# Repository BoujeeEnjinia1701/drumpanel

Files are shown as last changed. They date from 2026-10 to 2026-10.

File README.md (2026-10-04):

# DrumPanel

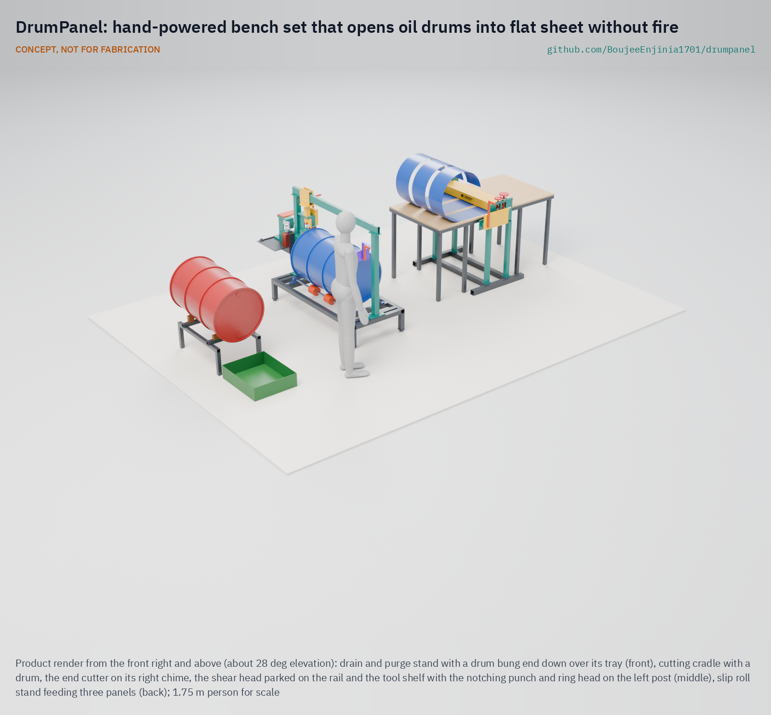
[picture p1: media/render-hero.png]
DrumPanel: hand-powered bench set that opens oil drums into flat sheet without fire


     

**Area:** Circular materials · **TRL:** 3 of 9 (proof of concept on paper) · **Value-engineering target:** USD 3,000 (estimated cost USD 3,489) · **Difficulty:** 3 of 5

Turns empty oil drums into flat sheet by purging and cold-opening them instead of burning them.

## Concept rationale

Used 55 gallon (about 208 L) steel drums are a cheap source of sheet metal for artisans; accounts from Haiti speak of three sheets of about 18 by 72 in (460 by 1,830 mm) per drum. DrumPanel gets three flat panels about 233 x 1,800 mm and two head discs about 552 mm across from each drum. Today the common method is to fill the drum with dried leaves and set it on fire to clear paint and residue, then chisel off the ends, split the side and flatten it. DrumPanel keeps the craft and changes the first steps: purge the drum, check it for vapour, cut it cold and roll it flat with hand-cranked tools on a bench.

The design is manual on purpose. The preliminary IP screen found powered drum cutter-flatteners on the market; DrumPanel assumes workshops with little money and no dependable power. A bench set built from commodity steel and bearings, published openly with a written purge and vapour check, can be made by a local fabricator for an estimated USD 3,489 (value-engineering target USD 3,000, so USD 489 over it) and shared across a workshop cluster.

## Burning platform

In Croix-des-Bouquets, Haiti, the centre of Haitian metal sculpture since Georges Liautaud began the form in the 1950s, drum lids are cut open with a chisel and hammer, the side is split, and the interior is filled with dried sugarcane or grass and set on fire to remove grime before the drum is flattened ([SFO Museum](https://www.sfomuseum.org/exhibitions/haitian-metal-sculpture)). Other accounts describe stuffing drums with banana leaves to burn off paint and residue, and cutting with only hammers and chisels ([Singing Rooster](https://singingrooster.org/about-haitian-art/)). Artists then flatten the body by climbing inside and using their weight to open it up ([Roots of Development](https://store.rootsofdevelopment.org/wp-content/uploads/2023/12/About-Haitian-Metal-Art.pdf)).

This first stage is where newcomers begin: new artists usually start by burning out whole 55 gallon drums, cutting them down and pounding the surfaces flat ([Global Exchange](https://globalexchange.org/tag/haiti-oil-drum-art/)). The work is loud enough that a support group tried supplying ear plugs ([Singing Rooster](https://singingrooster.org/about-haitian-art/)). The raw material is plentiful, a byproduct of shipping through the harbour in Port-au-Prince ([Haiti Hub](https://haitihub.com/the-story-of-haitian-metal-art/)), so better tools for this stage would reach many workshops.

## Where it could be used

### By industry

| Industry | Use |
| --- | --- |
| Artisan metalwork and crafts | Opening and flattening drums into sheet for sculpture, wall art and homewares |
| Informal fabrication | Sheet for stoves, boxes, roofing patches and small tanks in workshops without sheet stock |
| Drum reconditioning and recycling | Cold, manual opening of drums that cannot be reused whole |
| Vocational training | A documented, safer drum preparation method for apprentices |
| Fair trade and export buyers | A cleaner, repeatable supply chain for drum-based products |

### By country or region

| Country or region | Why it matters there |
| --- | --- |
| Haiti, Croix-des-Bouquets | Noailles in Croix-des-Bouquets has long been the centre of Haitian metal art, though gang violence has recently forced artists to relocate ([SFO Museum](https://www.sfomuseum.org/exhibitions/haitian-metal-sculpture)). |
| Haiti, Port-au-Prince | Drums come to artisans as a byproduct of shipping through the harbour, and each 55 gallon drum yields three sheets of about 18 by 72 in ([Haiti Hub](https://haitihub.com/the-story-of-haitian-metal-art/)). |
| United States | Fair trade stores sell Haitian oil drum art, giving artisans who export under fair labour conditions a route out of poverty ([Global Exchange](https://globalexchange.org/tag/haiti-oil-drum-art/)). |
| Europe and North America | Croix-des-Bouquets sculpture made with hacksaws, hammers and chisels is shown in galleries, museums and private collections ([Nader Haitian Art](https://www.naderhaitianart.com/blogs/news/a-deep-dive-into-metal-sculptures-from-croix-des-bouquets)). |

## What sparked the idea

Haiti Hub's account of Haitian metal art says it plainly: each drum is first burned to remove all paint and residue, then cut vertically down both sides and flattened into panels ([Haiti Hub](https://haitihub.com/the-story-of-haitian-metal-art/)). Every sheet in the craft starts with a fire and a chisel. DrumPanel asks whether that first step can be done cold, on a bench, with hand tools a local fabricator can make.

## Problem

Metal artisans who turn used oil drums into sheet usually burn each drum out first and then cut and flatten it by hand with chisels and body weight. The work is loud and relies on open fire, and there is no simple, documented bench method to open drums cold.

Full problem statement: [docs/01-problem.md](docs/01-problem.md)

## Concept

A bench set of manual tools that purges an empty oil drum, checks it for vapour, cold-cuts the ends and seam, and rolls the body flat; metal artisans clamp and crank to turn drums into flat sheet instead of burning them open.

Full design precis: [docs/02-concept.md](docs/02-concept.md) · Requirements: [docs/03-requirements.md](docs/03-requirements.md)

## Key components

- Drain and purge stand, drain tray and purge kit
- Vapour check kit (pumped gas detector)
- Cutting cradle: frame, rollers under the hoops, drum brake
- Rail posts, rail beam, trolley and a swivelling rotary shear head
- End cutter for the heads
- Slip roll: geared pinch rolls, bending roll, 3:1 chain crank, guards and tables
- Bench plate, deburring tools and pictogram procedure sheets

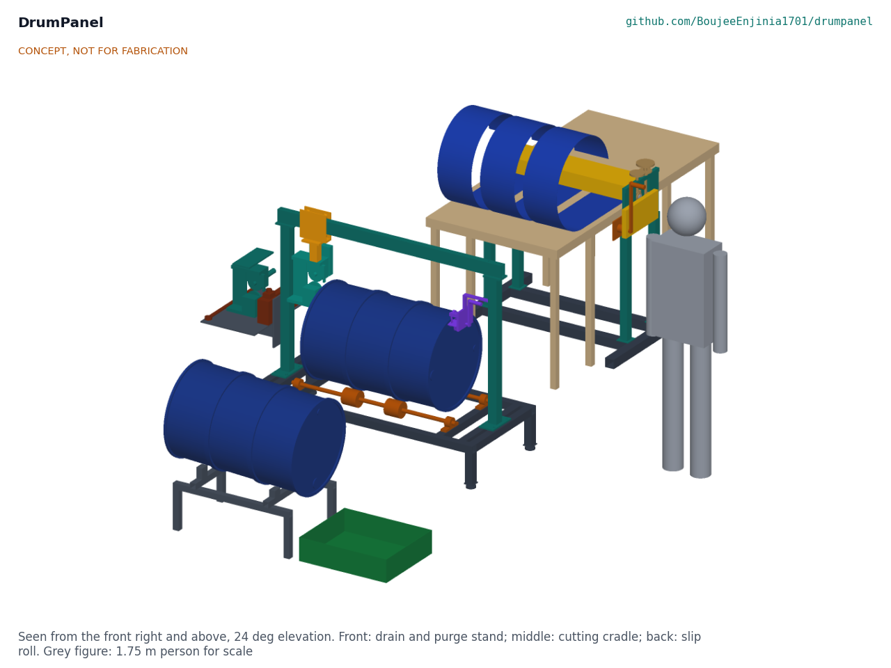
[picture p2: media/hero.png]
Concept overview: drain stand, cutting cradle and slip roll


## Building the prototype

The prototype build plan ([docs/05-build-plan.md](docs/05-build-plan.md)) shows how to make each of the 24 groups of parts and put them together, with a making sketch for every made part, close-ups of the joints and a picture for every assembly step. Almost everything is sawn, drilled and stick-welded from square tube and plate; the rolls are turned on a lathe; the slitting discs, cutter wheel, notching punches and dies, bearings, gears and gas detector are bought or made by a tool shop. It is a plan, not yet built: building and testing it is TRL 4 work.

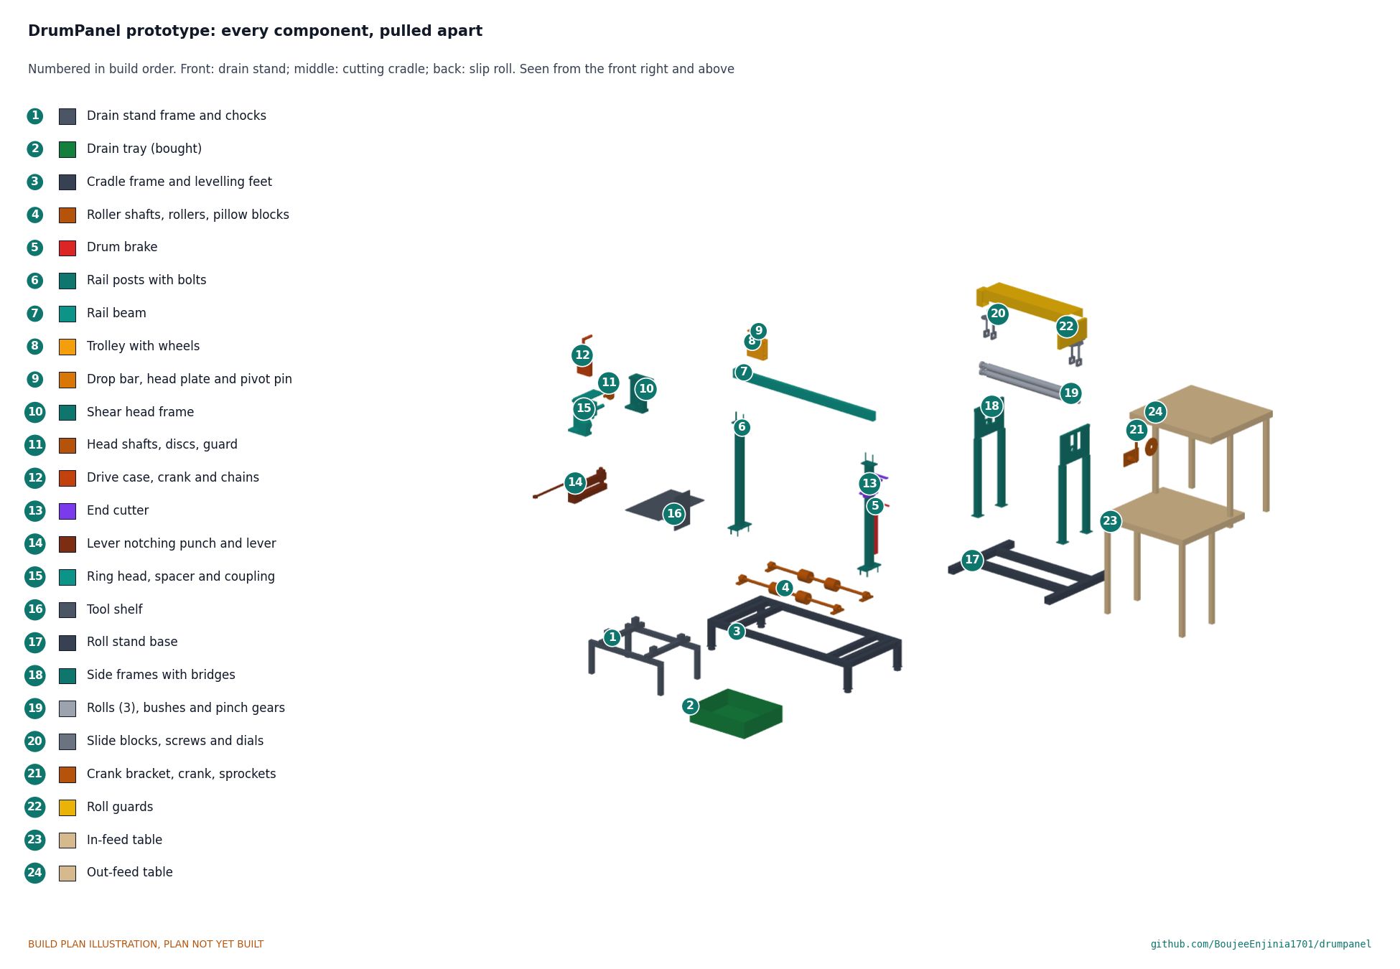
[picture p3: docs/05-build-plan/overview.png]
Every component, pulled apart and numbered in build order


## Safety

> Empty drums can still hold flammable vapour. Never cut, grind, weld or heat a drum until the purge is done and the vapour check passes below 5 % LEL.
>
> Do not process drums that held fuel, solvent, chemicals or unknown contents, or that have no readable label.
>
> A drum full of water weighs about 240 kg: fill and drain it on the stand, never lift it.
>
> Cut steel edges are sharp; wear cut-resistant gloves and eye protection, and deburr sheets before handling.
>
> Crank-driven rolls and cutters have pinch points; keep guards fitted and one person on the crank.
>
> This design is published as an open engineering reference. It is not certified equipment. It is a TRL 3 concept, not for fabrication until built and tested at TRL 4.

## Repository layout

| Folder | Contents |
| --- | --- |
| `docs/` | Problem, concept, requirements, calculations and design decisions |
| `cad/src/` | build123d Python source, the source of truth for all geometry |
| `cad/step/`, `cad/stl/` | Exported models for FreeCAD, other CAD tools and printing |
| `cad/drawings/` | 2D sketches and dimensioned drawings |
| `bom/` | Bill of materials |
| `electronics/` | KiCad schematics and PCB layouts |
| `firmware/` | Microcontroller code |
| `media/` | Renders, perspectives and photos |
| `build-log/` | Dated prototyping notes |

## Documentation

Controlled documents follow the portfolio [documentation standard](.kit/STANDARDS.md). Each carries a document ID (DMP-PRC-001 for the precis), a version and a revision history. Branded PDFs are built with `python .kit/render.py` and attached to GitHub Releases when a document is tagged, for example `DMP-PRC-001/v1.0`.

## Credits

Designed by Amish Chadha at Design Molecule Labs. See [CONTRIBUTORS.md](CONTRIBUTORS.md) for roles. To cite this design, use [CITATION.cff](CITATION.cff) (GitHub shows it as "Cite this repository").

AI assistance (Claude) was used to accelerate prototype documentation and first-pass research. Design direction and all decisions are Amish Chadha's, recorded in this repository's decision records (`docs/decisions/`).

## Licenses

- **Hardware** (CAD, drawings, BOM, electronics): [CERN-OHL-S v2](LICENSE)
- **Software** (firmware, scripts, notebooks): [MIT](LICENSE-SOFTWARE)

A project of the [Design Molecule](https://designmolecule.com) lab.

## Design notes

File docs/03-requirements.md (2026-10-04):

---
doc_id: DMP-REQ-001
title: DrumPanel requirements
project: DrumPanel
doc_type: Requirements
version: "0.5"
status: Draft
date: '2026-10-03'
author: Amish Chadha
license: CERN-OHL-S-2.0
revisions:
- version: "0.1"
  date: '2026-09-30'
  author: Amish Chadha
  change: Initial scaffold
- version: "0.2"
  date: '2026-10-03'
  author: Amish Chadha
  change: TRL 2; targets firmed up; R10 guarding, R11 handling and R12 yield added; concept status for each requirement
- version: "0.3"
  date: '2026-10-03'
  author: Amish Chadha
  change: TRL 3; status of every requirement from DMP-CAL-001 on the constructable design (DMP-DDR-002); R9 worded against the value-engineering target; R12 changed to three panels per drum
- version: "0.4"
  date: '2026-10-03'
  author: Amish Chadha
  change: 'R7 restated to 2.5 drums an hour by Amish on 2026-10-03 (decision 5A, DMP-DDR-003); status of R5, R6, R7, R9 and R11 from DMP-CAL-001 v0.2 after the notching punch, ring head and dial adjuster'
- version: "0.5"
  date: '2026-10-03'
  author: Amish Chadha
  change: "Round-2 decision 5A (DMP-DDR-004): R7 kept at 2.5 drums an hour; the TRL 4 timed trial decides; no design change"
---

# DrumPanel requirements

On paper, the constructable design meets ten of the twelve requirements, misses one, and is over the value-engineering target of R9. On 2026-10-03 Amish chose option A on every requirement decision put to him ("1A 2A 3A 4A 5A 6A 7A 8A 9A 10A 11A"); for DrumPanel that added a lever notching punch and a ring head and restated R7 from 4 to 2.5 drums an hour (5A), and added a fine-pitch dial adjuster to the bending roll (8A) (DMP-DDR-003). R7 is still not met: the estimate is about 2.26 drums an hour, up from 2.0. R5 is now met on paper with a trial pass for each batch of drum steel: the dial sets the bending roll to 0.025 mm against a 0.29 mm allowance. Every figure is from DMP-CAL-001 v0.2 (`docs/04-calcs/sizing.py`); the tag in brackets is the line of its output.

*Table 1. Requirements and their status at TRL 3.*

| ID | Requirement | Target | Verification (TRL 4) | Status at TRL 3 |
| --- | --- | --- | --- | --- |
| R1 | No open flame in the process | Zero heat or flame steps from drum to flat sheet | Procedure review and observed trial | Met by design: purge, check, cut and roll are all cold; no grinder or torch touches a drum |
| R2 | Vapour check before cutting | Check reliably flags a drum with flammable vapour at or above 10 % of the lower explosive limit (LEL) | Bump test of the bought detector with 50 % LEL gas; bench test with a calibrated gas | Met by design: a bought pumped LEL detector with its alarm set at 5 % LEL, half the target (DMP-DDR-001, D2) |
| R3 | Remove ends cold | Both heads off a 208 L drum in under 10 minutes by one person | Timed trials on a batch of drums | Met on paper: about 3.9 min [H7]; crank force 12 to 27 N [C10 to C15] |
| R4 | Open the side | Straight slit along the full body length, edge deviation at or below 5 mm | Measure the cut line on trial drums | Met by design: the shear head runs on a rail straight within 1 mm |
| R5 | Flat sheet | Panels flat within 10 mm over 1 m after rolling | Straightedge and feeler check | Met on paper, with a trial pass for each batch: needs the bending roll within 0.29 mm of the right height [E13], which is 11.8 divisions of the new 0.025 mm dial [E14d], held by a lock nut; a fixed setting can leave 188 mm of sag on other steel [E12], so the reading is found by a trial pass on the first drum of each batch; the last 90 mm of each panel end is set by hand [E15, E16] |
| R6 | Manageable effort | Crank force at or below 150 N at the handle | Spring scale on the handle during trials | Met on paper: end cutter 27 N, shear head 68 N for the slit and 136 N for two ring cuts at 1.5 mm wall, notching punch lever 131 N, slip roll 20 N [C15, D15, D15r, K3, E23] |
| R7 | Throughput | At least 2.5 drums to flat sheet per hour for a two-person team (restated 2026-10-03, was 4) | Timed half-day workshop trial | Not met on paper: about 2.26 drums an hour [H5], 53.1 hands-on minutes a drum against 48.0 [H4, H9]. Kept at 2.5 by Amish (round 2); the TRL 4 timed trial decides |
| R8 | Local build | All parts made or bought in a town with a welder and a lathe | Build by a partner fabricator from the drawings | Met by design: welding, drilling and turning only; the rolls need a lathe with 1.1 m between centres; discs, cutter wheel, bearings, gears and chain are bought |
| R9 | Value engineering | Bench set parts cost at or below the USD 3,000 value-engineering target | Costed bill of materials | Over the target: estimated USD 3,489, USD 489 over the value-engineering target [J1 to J3] |
| R10 | Guarding | No finger reaches a roll nip, disc nip, gear or chain in normal use; guards need a tool to remove | ISO 13857 check of the guards as built | Met on paper: every slot 8 mm or less and 45 mm or more from its nip [G1 to G3]; the shear head's chains run inside its closed drive case and the ring head coupling turns inside a guard sleeve |
| R11 | Handling | No lift over 25 kg by one person; a drum full of water is never lifted | Weigh parts; procedure review | Met with a two-person rule: heaviest piece the 34 kg cradle frame [I4]; shear head 23.7 kg, ring head 20.4 kg, notching punch 18.7 kg [I5, I7, I9]; a full drum (about 240 kg) is filled and drained in place [B2] |
| R12 | Yield | Per drum: three flat panels about 233 x 1,800 mm and two head discs about 550 mm across | Measure the output of trial drums | Met by design: panels 233, 234 and 233 x 1,800 mm; heads 552 mm [A1 to A3] |

## Requirement restated on 2026-10-03

R7 was "at least 4 drums to flat sheet per hour for a two-person team". Amish restated it to 2.5 drums an hour when he chose option 5A on 2026-10-03 ("1A 2A 3A 4A 5A 6A 7A 8A 9A 10A 11A"): add a lever notching punch and a second shear head so two ring cuts are made per pass, and restate R7 to 2.5 drums an hour. The record is DMP-DDR-003.

In round 2 Amish kept R7 at 2.5 drums an hour (5A of DMP-DDR-004): "i agree with all the 46 recommendations you provided. please proceed." The paper estimate of 2.26 drums an hour is not changed, and R7 is not claimed as met. The gap is about 10 % of the hands-on time, inside the uncertainty of the task-time estimates, so the TRL 4 timed half-day trial decides, and no design change is made at TRL 3.

## Assumptions

- Most drums reaching artisans held oils or similar contents that a water purge can clear enough to cut cold. Drums that did not are rejected at the door (DMP-PRB-001, Constraints).
- Artists accept painted panels, with paint removal as a separate cold step (DMP-DDR-001, D4).
- Drum body steel has a yield strength of 200 to 300 MPa and a wall of 0.8 to 1.2 mm; heads are 1.0 to 1.5 mm.
- The rolling hoops are cut out as two strips, so the slip roll never has to straighten them (DMP-DDR-002, P7).
- A pumped LEL detector, bump-tested each day, is good enough for a pass or fail check before cold cutting.

## Safety

> **Safety:** R1, R2, R10 and R11 are safety requirements. They are not traded against cost or throughput: where a cheaper or faster option would weaken them, the conservative option was taken (DMP-DEC-001). The bench set is an open engineering reference, never certified equipment.

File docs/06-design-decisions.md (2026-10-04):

---
doc_id: DMP-DEC-001
title: DrumPanel design decisions register
project: DrumPanel
doc_type: Design decisions register
version: "0.3"
status: Draft
date: '2026-10-03'
author: Amish Chadha
license: CERN-OHL-S-2.0
revisions:
- version: "0.1"
  date: '2026-10-03'
  author: Amish Chadha
  change: Register opened at TRL 3; every decision made under Amish's pre-approval of 2026-10-03
- version: "0.2"
  date: '2026-10-03'
  author: Amish Chadha
  change: Amish's requirement decisions 5A (R7) and 8A (R5) of 2026-10-03 moved to Decisions made (DMP-DDR-003); new open decision on the remaining R7 gap; value engineering updated
- version: "0.3"
  date: '2026-10-03'
  author: Amish Chadha
  change: "Open decision 1 (R7 gap) decided, round 2, 5A (DMP-DDR-004); no open decisions"
---

# DrumPanel design decisions register

Every design decision still to be made, and every decision made, in one place. Each decision is argued in full in its decision record under `docs/decisions/`; this register is the index Amish works from. The build plan (`docs/05-build-plan.md`) describes the design as it stands and does not list open decisions.

## Open decisions

None. Open decision 1 (the remaining R7 gap) was decided by Amish on 2026-10-03: R7 stays at 2.5 drums an hour and the TRL 4 timed trial decides; see Decisions made and DMP-DDR-004.

## To confirm when parts are bought

*Table 2. Items to confirm when parts are bought.*

| # | What to confirm | Why it matters | Source |
| --- | --- | --- | --- |
| 1 | The slitting discs bought: 101 mm outside, 10 mm thick, 25 mm bore, hardness 58 to 60 HRC | The 1.0 mm overlap, the shaft shoulders and the guard clearance are drawn to these sizes | DMP-DDR-002, P4 |
| 2 | The end cutter wheel bought: 50 mm across, 6 mm thick, and its bore | Sets the cutter arm and the cut line 4 mm inside the chime wall | DMP-DDR-002, P3 |
| 3 | Real drums from the first supplier: chime inside radius, hoop positions and height, wall and head thickness | Hoop cut lines (30 mm each side of each hoop), roller positions and the steel range of the calculations | DMP-CAL-001, Table 1 |
| 4 | The gas detector bought: pumped sampling, a 1 m probe that fits a 20 mm bung, an alarm that can be set at 5 % LEL, and its calibration gas | The vapour check procedure depends on it | DMP-DDR-001, D2 |
| 5 | Pinch gear mesh at 61 to 61.5 mm centres with the module 3 gears bought | The pinch opens as the sheet thickens | DMP-CAL-001, section 5.5 |
| 6 | The bending roll setting for the first batch of drums, found by a trial pass | R5 depends on it; the calculation gives only a range (9.3 to 19.3 mm) | DMP-CAL-001, section 5.3 |
| 7 | The driven disc's grip on a 1.5 mm wall | Traction margin is only 1.17 at 1.5 mm | DMP-CAL-001, section 4 |
| 8 | The notching punch on a scrap chime and a scrap hoop: force and a clean cut | The chime notch force (24.3 kN) is the least certain number and sets the lever force (131 N against 150 N) | DMP-CAL-001, section 9 |
| 9 | The #35 sprockets bought (12, 28 and two of 15 teeth) bored to 20 and 25 mm, and their chains' centre distances in the drive case | The drive case bores are drawn to these sprockets | DMP-DDR-003, Q3 |

## Value engineering

Value-engineering target: USD 3,000 (a hypothetical control target, not a limit). Estimated cost of the constructable design: USD 3,489 (USD 489 over the target). Amish's decisions of 2026-10-03 added USD 695 (DMP-DDR-003). Main cost drivers and savings worth trying:

- The vapour check kit (USD 600) is the largest line. It is a safety item; a shared detector across a cooperative's workshops spreads its cost, but the bench set never runs without one.
- The shear head (USD 340) and the ring head (USD 255), mostly their four D2 discs: standard slitter knives from a cutting tool supplier are cheaper than custom-ground discs, and four bought together cost less each.
- The notching punch (USD 330), mostly its two ground punch and die sets: punch and die blanks from a press tooling supplier, finished locally, could save about USD 60.
- The three rolls (USD 285) and their turning: buying ground shafting of the right length and turning only the journals could save about USD 60.
- The side frames (USD 150): plasma-cut plate from a local shop is cheaper than sawn and drilled plate.
- Throughput still limits the design more than cost (R7 not met; open decision 1). Ideas worth trying at TRL 4: set stops on the rail for the three ring passes, and notching a batch of drums ahead of time while another is cut.

## Decisions made

*Table 3. Decisions made.*

| Date | Decision | Decided by | Record |
| --- | --- | --- | --- |
| 2026-10-03 | Purge by water fill with detergent, soak 10 min, drain; water reused through a settling drum | Amish, pre-approval: "start with the first 14 repos from the list of 29 projects. I pre-approve the batch runs along with any recommendations you come up with. I also accept any cost overruns or variations from the assumed scope cost." | DMP-DDR-001, D1 |
| 2026-10-03 | Vapour check with a bought pumped LEL detector; pass only below 5 % LEL (conservative; a reviewed log of 50 drums could support 10 %) | Amish, pre-approval: "start with the first 14 repos from the list of 29 projects. I pre-approve the batch runs along with any recommendations you come up with. I also accept any cost overruns or variations from the assumed scope cost." | DMP-DDR-001, D2 |
| 2026-10-03 | Accept only drums labelled for non-volatile oils; reject fuel, solvent, chemical, unknown and unlabelled drums (conservative) | Amish, pre-approval: "start with the first 14 repos from the list of 29 projects. I pre-approve the batch runs along with any recommendations you come up with. I also accept any cost overruns or variations from the assumed scope cost." | DMP-DDR-001, D3 |
| 2026-10-03 | Panels leave painted; paint removal is a separate cold step outside the design | Amish, pre-approval: "start with the first 14 repos from the list of 29 projects. I pre-approve the batch runs along with any recommendations you come up with. I also accept any cost overruns or variations from the assumed scope cost." | DMP-DDR-001, D4 |
| 2026-10-03 | End cutter: wheel cutter on the chime, after expired US3161952A | Amish, pre-approval: "start with the first 14 repos from the list of 29 projects. I pre-approve the batch runs along with any recommendations you come up with. I also accept any cost overruns or variations from the assumed scope cost." | DMP-DDR-001, D5 |
| 2026-10-03 | One rotary shear head for the slit and all ring cuts | Amish, pre-approval: "start with the first 14 repos from the list of 29 projects. I pre-approve the batch runs along with any recommendations you come up with. I also accept any cost overruns or variations from the assumed scope cost." | DMP-DDR-001, D6 |
| 2026-10-03 | Flatten with a hand slip roll | Amish, pre-approval: "start with the first 14 repos from the list of 29 projects. I pre-approve the batch runs along with any recommendations you come up with. I also accept any cost overruns or variations from the assumed scope cost." | DMP-DDR-001, D7 |
| 2026-10-03 | Steel range: body 0.8 to 1.5 mm, heads 1.0 to 1.5 mm | Amish, pre-approval: "start with the first 14 repos from the list of 29 projects. I pre-approve the batch runs along with any recommendations you come up with. I also accept any cost overruns or variations from the assumed scope cost." | DMP-DDR-001, D8 |
| 2026-10-03 | One shared bench set per cooperative or cluster | Amish, pre-approval: "start with the first 14 repos from the list of 29 projects. I pre-approve the batch runs along with any recommendations you come up with. I also accept any cost overruns or variations from the assumed scope cost." | DMP-DDR-001, D9 |
| 2026-10-03 | Standard 300 mm crank and #40 chain, drawn to accept the proposed hand capstan block later | Amish, pre-approval: "start with the first 14 repos from the list of 29 projects. I pre-approve the batch runs along with any recommendations you come up with. I also accept any cost overruns or variations from the assumed scope cost." | DMP-DDR-001, D10 |
| 2026-10-03 | First co-design candidate to approach: Haitian metal artists through a fair trade partner (Singing Rooster first); not agreed | Amish, pre-approval: "start with the first 14 repos from the list of 29 projects. I pre-approve the batch runs along with any recommendations you come up with. I also accept any cost overruns or variations from the assumed scope cost." | DMP-DDR-001, D11 |
| 2026-10-03 | Slit 50 mm beside the drum's welded seam | Amish, pre-approval: "start with the first 14 repos from the list of 29 projects. I pre-approve the batch runs along with any recommendations you come up with. I also accept any cost overruns or variations from the assumed scope cost." | DMP-DDR-001, D12 |
| 2026-10-03 | Design for construction, changes P1 to P14: fixed sloping drain stand, rollers under the hoops and a screw brake, end cutter on the head only, rail-mounted shear head with a web in the cut, hacksaw notches, slip roll, hoop strips cut out (three panels per drum), swivelling head, guards, hand-set panel ends, bolted side frames, posts moved out, torque arm, height set by the levelling feet | Amish, pre-approval: "start with the first 14 repos from the list of 29 projects. I pre-approve the batch runs along with any recommendations you come up with. I also accept any cost overruns or variations from the assumed scope cost." | DMP-DDR-002 |
| 2026-10-03 | Guards: every nip slot 8 mm or less and at least 20 mm from its nip; guards need a tool to remove (conservative) | Amish, pre-approval: "start with the first 14 repos from the list of 29 projects. I pre-approve the batch runs along with any recommendations you come up with. I also accept any cost overruns or variations from the assumed scope cost." | DMP-DDR-002, P9 |
| 2026-10-03 | Two-person rule for any lift over 25 kg; a drum full of water is never lifted (conservative) | Amish, pre-approval: "start with the first 14 repos from the list of 29 projects. I pre-approve the batch runs along with any recommendations you come up with. I also accept any cost overruns or variations from the assumed scope cost." | DMP-DDR-002, P1 |
| 2026-10-03 | Requirements R10 (guarding), R11 (handling) and R12 (yield) added; R7 reported as not met and R5 as at risk, with no redesign beyond TRL 3 | Amish, pre-approval: "start with the first 14 repos from the list of 29 projects. I pre-approve the batch runs along with any recommendations you come up with. I also accept any cost overruns or variations from the assumed scope cost." | DMP-REQ-001 v0.3 |
| 2026-10-03 | R7 throughput (5A): a lever notching punch replaces the four hacksaw notches (chime notch widened to 60 mm), and a ring head bolted to the shear head makes two ring cuts a pass; R7 restated from 4 to 2.5 drums an hour. Result: about 2.26 drums an hour, not met (open decision 1) | Amish: "1A 2A 3A 4A 5A 6A 7A 8A 9A 10A 11A" | DMP-DDR-003, Q1 and Q2; DMP-REQ-001 v0.4 |
| 2026-10-03 | R5 flatness (8A): fine-pitch M20 x 1.5 bending screws with 60-division dials (0.025 mm) and lock nuts. Result: the 0.29 mm allowance is 11.8 divisions; R5 met on paper with a trial pass for each batch | Amish: "1A 2A 3A 4A 5A 6A 7A 8A 9A 10A 11A" | DMP-DDR-003, Q4 |
| 2026-10-03 | Design for construction while carrying out 5A: the shear head crank moved onto a raised crank shaft in a closed 2.33 to 1 chain drive case (the former crank swept through the drum wall), and a tool shelf on the left rail post | Made under STANDARDS section 18 (Amish, 2026-09-30: "fix the design assumptions to match and be physically feasible") to carry out Amish's 5A: "1A 2A 3A 4A 5A 6A 7A 8A 9A 10A 11A" | DMP-DDR-003, Q3 and Q5 |
| 2026-10-03 | 5A (round 2): R7 kept at 2.5 drums an hour (paper estimate 2.26, not met on paper); the TRL 4 timed half-day trial decides; no design change | Amish: "i agree with all the 46 recommendations you provided. please proceed." | DMP-DDR-004 |

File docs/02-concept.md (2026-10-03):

---
doc_id: DMP-PRC-001
title: DrumPanel design precis
project: DrumPanel
doc_type: Precis
version: "0.4"
status: Draft
date: '2026-10-03'
author: Amish Chadha
license: CERN-OHL-S-2.0
revisions:
- version: "0.1"
  date: '2026-09-30'
  author: Amish Chadha
  change: Initial scaffold
- version: "0.2"
  date: '2026-10-03'
  author: Amish Chadha
  change: TRL 2; how it works in three stations, key design choices, first-order numbers, open questions answered (DMP-DDR-001)
- version: "0.3"
  date: '2026-10-03'
  author: Amish Chadha
  change: 'TRL 3; constructable design (DMP-DDR-002): hoop strips cut out so the body gives three panels, slip roll with a pinch pair, shear head on an overhead rail; figures from DMP-CAL-001'
- version: "0.4"
  date: '2026-10-03'
  author: Amish Chadha
  change: 'Amish''s requirement decisions of 2026-10-03 (DMP-DDR-003): lever notching punch, ring head for two ring cuts a pass, raised shear head drive, fine-pitch dial adjuster on the bending roll; figures from DMP-CAL-001 v0.2'
---

# DrumPanel design precis

Turns empty oil drums into flat sheet by purging and cold-opening them instead of burning them.

## How it works

DrumPanel is a hand-powered bench set in three stations that takes an empty 208 L oil drum to flat steel without fire. Two people run it; nothing needs electricity.

1. **Accept or reject.** Only a drum whose label shows it held a non-volatile oil is taken in. Anything else goes back.
2. **Drain and purge** (drain and purge stand). The drum lies on a low stand that slopes 2.9 degrees toward its bungs, over a tray. Residue drains out of the bottom bung; the drum is then filled with water and a little detergent through the top bung, left 10 minutes, and drained. The water settles in a spare drum and is reused.
3. **Vapour check.** A pumped gas detector samples through both bungs. The drum passes only below 5 % of the lower explosive limit; otherwise it is purged again.
4. **Heads off** (cutting cradle). The drum rolls onto four rollers that carry it on its rolling hoops. A hand-cranked end cutter clamps over the chime: a knurled wheel drives it round while a hardened wheel cuts the head out just inside the chime. A torque arm against a rail post stops it turning with the drum. Both heads come out as flat discs about 552 mm across.
5. **Notch and slit.** A lever notching punch, slid into the open drum end, punches a notch through each chime and a slot through each hoop on the slit line, beside the drum's own welded seam, with up to about 18 swings of its ratchet lever for each. The drum brake is screwed on. A hand-cranked rotary shear head, hanging from a trolley on an overhead rail, is wound along the top of the drum: its upper disc is driven through a small chain drive whose crank turns high, clear of the drum, its lower disc runs inside, and its thin web runs in the cut behind them, so the drum is slit from end to end.
6. **Ring cuts.** The head is swung 90 degrees on its pivot and a second head, the ring head, is lowered through the slit and bolted to it 233 mm along the drum, its upper disc coupled to the first. With the brake off, the crank turns the drum on its rollers past both pairs of discs three times, making two cuts each time: 30 mm in from each end to take off the chime rings, and each side of each hoop to take out the hoop strips. What is left is three curled panels.
7. **Roll flat** (slip roll stand). The three panels are fed side by side, paint side up, through a hand-cranked slip roll: a pinch pair geared together drives them, and a bending roll behind bends them the other way just enough that they spring back flat. The bending roll is set on fine-pitch screws with dials and lock nuts: a trial pass on the first drum of each batch finds the dial reading, and every later drum is set to it. The last 90 mm of each panel end is set flat by hand on a steel plate.
8. **Deburr.** Every cut edge is filed or scraped before the panels are stacked.

Figure 1. Concept overview

*Figure 1. The three stations: drain and purge stand (front), cutting cradle (middle), slip roll stand (back).*

## Components

*Table 1. Components, in build order. Numbers match `bom/bom.csv`.*

| BOM | Component | Role |
| --- | --- | --- |
| 1 | Drain and purge stand | Welded frame with hardwood chocks that holds a drum, full of water if need be, bung end low over the tray |
| 2 | Drain tray | Catches residue and purge water |
| 3 | Purge kit | Hose, bung adaptors, non-sparking bung wrench, settling drum fittings, detergent |
| 4 | Vapour check kit | Pumped LEL gas detector with its alarm at 5 % LEL, and bump-test gas |
| 5 | Cradle frame with levelling feet | Low welded frame; the feet also set the drum height under the rail |
| 6 | Cradle rollers, shafts and pillow blocks | Four rollers under the rolling hoops let the drum turn |
| 7 | Drum brake | Screw and pad that hold the drum still for the slit |
| 8 | Rail posts and rail beam | Portal over the cradle that carries the shear head |
| 9 | Trolley, swivel and drop bar | Carries the head along the rail; the pivot sets slit or ring position |
| 10 | Rotary shear head | Two hardened discs, driven upper and idle lower, in a frame whose web runs in the cut; a 2.33 to 1 chain drive in a closed case with a 155 mm crank |
| 11 | End cutter | Cuts each head out just inside the chime |
| 12 | Roll stand base | Wide base that keeps the slip roll from tipping |
| 13 | Side frames | Plates on legs that carry the three rolls |
| 14 | Rolls | Lower and upper pinch rolls and the bending roll, 60 mm |
| 15 | Bushes, slide blocks and screws | Bronze bushes; blocks and screws that set the pinch and the bend; dials and lock nuts on the fine-pitch bending screws |
| 16 | Pinch gears | Keep the pinch rolls turning together |
| 17 | Crank and chain drive | 300 mm crank and a 3:1 chain to the lower roll |
| 18 | Roll guards | Nip guards with 8 mm slots, lid, chain and gear guards |
| 19 | In-feed and out-feed tables | Support the 1.8 m panels at the sheet line |
| 20 | Finishing tools and bench plate | Plate and mallet for the panel ends; deburring tools |
| 21 | Lever notching punch | C-frame punch with two stations that notches the chimes and slots the hoops on the slit line |
| 22 | Procedure sheets | Pictogram sheets for acceptance, purge, check, cutting, rolling and finishing |
| 23 | Fasteners, paint and welding consumables | Allowance |
| 24 | Personal protective equipment | Cut-resistant gloves, glasses, ear defenders, aprons |
| 25 | Ring head with spacer and coupling | A second shear head bolted to the first for two ring cuts at a time |
| 26 | Tool shelf | Shelf on the left rail post for the notching punch and the ring head |

## Key design choices

Choices 1 to 8 were decided on 2026-10-03 under Amish's pre-approval (DMP-DDR-001 and DMP-DDR-002); choices 9 and 10 are Amish's requirement decisions of 2026-10-03 (DMP-DDR-003). All are in the register DMP-DEC-001.

1. **Water purge, not air or steam.** Water displaces vapour and washes residue with no power or fuel; the water is reused.
2. **A bought pumped LEL detector, pass below 5 % LEL.** Half the usual 10 % hot-work limit, because a cold cut still has friction and a failed check costs only a second purge.
3. **Accept only drums labelled for non-volatile oils.** The purge is sized for oils, not fuels or solvents.
4. **Three panels, hoops cut out.** Straightening a rolling hoop would stretch its crown about 8 %; cutting the hoop strips out leaves three flat panels about 233 x 1,800 mm instead of one buckled sheet.
5. **One shear head for the slit, two for the ring cuts.** It swivels 90 degrees on its pivot; the slit is made with the drum still, the ring cuts with the drum turning and the ring head bolted on.
6. **Slip roll, not a three-roll pyramid.** A pyramid of three plain rolls cannot drive the panels by friction alone; the geared pinch pair grips them with a set force and the bending roll does the bending.
7. **Trial-pass setting.** The setting that leaves a panel flat changes with each batch of drum steel, so the first panel of each batch is used to find it.
8. **Shared bench set.** One set serves a cooperative or a cluster of workshops.
9. **Throughput (R7).** A lever notching punch replaces the hacksaw notches and a ring head makes two ring cuts a pass, so two people turn about 2.26 drums an hour, against Amish's restated target of 2.5.
10. **Flatness (R5).** Fine-pitch bending screws with dials (0.025 mm a division) and lock nuts set the bending roll well inside the 0.29 mm allowance and hold it.

## First-order numbers

*Table 2. Key figures from DMP-CAL-001. Assumptions: drum steel yield 200 to 300 MPa, body 0.8 to 1.2 mm, heads 1.0 to 1.5 mm, shear strength 0.8 of a 360 MPa tensile strength.*

| Quantity | Value | Source |
| --- | --- | --- |
| Output per drum | Three panels 233, 234 and 233 x 1,800 mm; two head discs 552 mm | [A1 to A3] |
| Flat area per drum | 1.26 m² of panels and 0.48 m² of heads | [A4, A5] |
| Drum full of water | About 240 kg, filled and drained in place | [B2] |
| Purge | Fill 11 min at 20 L/min; drain 2.3 min; about 1.4 L left below the bung | [B3 to B5] |
| End cutter | Crank force 12 to 27 N; about 2 min a head with setting up | [C10 to C15, H7] |
| Shear head | Separating force up to 1,429 N; crank force 16 to 68 N for the slit, 32 to 136 N for two ring cuts | [D8 to D15r] |
| Notching punch | 24.3 kN for a chime notch; lever force up to 131 N | [K1, K3] |
| Slip roll | Bending roll about 13.4 mm above the lower roll for 250 MPa, 1.0 mm steel; 9.3 to 19.3 mm over the range; set to 0.29 mm, 11.8 dial divisions | [E10, E11, E13, E14d] |
| Slip roll crank | 20 N at 300 mm through a 3:1 chain; feed 1.9 m/min | [E23, E24] |
| Throughput | About 2.26 drums an hour for two people (estimate; R7 asks 2.5) | [H5] |
| Masses | Cradle with its tools about 196 kg, slip roll stand about 191 kg, drain stand about 15 kg | [I1 to I3] |
| Cost | Value-engineering target: USD 3,000. Estimated cost of the constructable design: USD 3,489 (USD 489 over the target) | [J1 to J3] |

## Patent design-arounds

From the preliminary patent, trademark and prior-art screen (not legal advice):

- Stay manual; powered drum cutter-flatteners already exist. Every DrumPanel station is hand-cranked.
- Publish the purge and vapour check procedure openly with the design. It is in this precis, the build plan and the procedure sheets.
- Build on expired prior art such as the US3161952A drum-head cutter. The end cutter follows its principle: a wheel cutting the head just inside the chime.

## Shared blocks

- Hand crank and chain drive: the slip roll's 300 mm crank with a #40 chain at 3:1 is drawn so it can later be swapped for the proposed hand capstan common block (SaltDrag, SiltHaul) if that block is adopted (DMP-DDR-001, D10).
- CalRig proof-load: used at TRL 4 for the drain stand, frame and post checks; nothing in the TRL 3 design depends on it.

## Safety

> **Safety:** An empty oil drum can still hold flammable vapour. Never cut, grind, weld or heat a drum until the purge is done and the vapour check passes below 5 % LEL; repeat the check if a drum stands overnight.

> **Safety:** Do not process drums that held fuel, solvent, chemicals or unknown contents, or that have no readable label.

> **Safety:** Cut steel edges are sharp. Wear cut-resistant gloves and eye protection for every task that handles cut steel, and deburr every edge before panels are stacked or carried.

> **Safety:** The shear head, ring head, end cutter and slip roll have in-running nips, and the slip roll and the shear head have chains. Keep every guard fitted (a tool is needed to remove them), keep one person on a crank and nobody else's hands near the work, and never reach past a guard.

> **Safety:** A drum full of water weighs about 240 kg. Fill and drain it on the stand; never lift or tip a full drum. Lift anything over 25 kg with two people.

> **Safety:** Purge water carries oil. Settle it, skim the oil into a closed container for a recycler, and never pour it on the ground or into a drain.

This design is published as an open engineering reference. It is not certified equipment.

## Next steps

TRL 3 is complete on paper (DMP-CAL-001, DMP-BLD-001). The recommended next step, for Amish to authorise when the portfolio phase allows it, is TRL 4: approach the first co-design candidate, build the bench set to DMP-BLD-001, and run the first checks in its section 5, starting with the vapour check procedure and the slip roll trial pass (R2, R5).

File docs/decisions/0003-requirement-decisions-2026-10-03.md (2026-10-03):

---
doc_id: DMP-DDR-003
title: DrumPanel requirement decisions of 2026-10-03
project: DrumPanel
doc_type: Design decision record
version: "0.1"
status: Draft
date: '2026-10-03'
author: Amish Chadha
license: CERN-OHL-S-2.0
revisions:
- version: "0.1"
  date: '2026-10-03'
  author: Amish Chadha
  change: Amish's choices 5A (R7) and 8A (R5) carried into the model, calculations, drawings and build plan
---

# 0003: Requirement decisions of 2026-10-03

- **Date:** 2026-10-03
- **Status:** accepted. Decided by Amish on 2026-10-03, choosing option A on every requirement decision put to him: "1A 2A 3A 4A 5A 6A 7A 8A 9A 10A 11A". For DrumPanel these are 5A (R7) and 8A (R5).

## Context

At TRL 3 the constructable design (DMP-DDR-002) missed R7, four drums an hour for two people, at about 2.0 drums an hour: the four hacksaw notches (8 minutes) and the six single ring cuts (about 12 minutes) made the cutting cradle the bottleneck. R5, flat within 10 mm over 1 m, was at risk: the bending roll must be within 0.29 mm of the right height, which was about 1.4 divisions of the 12-division handwheels on the M20 x 2.5 bending screws.

## Options considered

*Table 1. The two decisions put to Amish.*

| Decision | Option chosen | What it asked for |
| --- | --- | --- |
| 5A, R7 throughput | A | Add a lever notching punch to replace the four hacksaw notches, and a second shear head so two ring cuts are made per pass; recompute hands-on minutes and drums an hour; restate R7 to 2.5 drums an hour |
| 8A, R5 flatness | A | Add a fine-pitch screw adjuster with a dial and a lock to set the bending roll height |

## Decision

*Table 2. Changes made to the model, the BOM and the calculations.*

| # | Change | How it is built | Result |
| --- | --- | --- | --- |
| Q1 | Lever notching punch (5A) | A C-frame punch of S355 plate with two stations, slid into the open drum end: station 1 notches each chime (60 x 35 mm, open-ended) with the frame's back face on the drum end; station 2, 338 mm out, slots each hoop (40 x 32 mm) with the drum end against the station 1 die block. D2 punches with faces raked 10 degrees, each pushed by a Tr24 x 5 screw turned by a 500 mm ratchet lever. The chime notch is widened from 40 to 60 mm so the punch's lower jaw passes in through it to reach the hoop | Chime notch 24.3 kN, lever 131 N; hoop slot 6.6 kN, lever 36 N; four notches in 4.0 minutes, down from 8 (DMP-CAL-001, section 9) |
| Q2 | Ring head (5A) | A second shear head made to the same drawings without a drive, lowered through the slit and bolted to the main head with a 10 mm spacer plate once the main head is swivelled for ring cuts; nips 233 mm apart (234 mm for the middle pass); a coupling shaft in a loose guard sleeve joins the two upper shafts | Six ring cuts in three passes, 9.5 minutes, down from about 12.4; 20.4 kg (DMP-CAL-001, sections 4.1 and 8) |
| Q3 | Raised shear head drive (design for construction, found while carrying out Q2) | The crank moves off the upper shaft onto a raised crank shaft in a closed drive case on the side of the head: 12 to 28 tooth #35 chain to a jackshaft, then 15 to 15 tooth down to the upper shaft, 2.33 to 1; crank 155 mm | The former 200 mm crank on the upper shaft swept through the drum wall (about 13,700 mm³ in the model's sweep check), so it could not make a full turn in either mode. The new crank sweeps clear of the drum, posts, beam and trolley in both modes, and two ring cuts on 1.5 mm steel need 136 N, within R6; the slit needs 68 N but takes 2.7 minutes, up from 2.3 |
| Q4 | Fine-pitch dial adjuster (8A) | Each bending screw becomes an M20 x 1.5 fine-pitch screw with an 80 mm dial of 60 divisions (0.025 mm each) clamped to it, a pointer on the bridge, and a lock nut on the bridge that holds the setting | The 0.29 mm allowance is 11.8 divisions; the trial pass on the first drum of a batch gives a reading that every later drum is set to (DMP-CAL-001, section 5.3) |
| Q5 | Tool shelf | A plate shelf bolted to the outer face of the left rail post holds the notching punch, its lever and the ring head with its spacer plate and coupling | The tools have a place at the cradle; about 40 kg on the shelf |

Q3 is a change made to keep the design constructable under STANDARDS section 18 (Amish, 2026-09-30: "fix the design assumptions to match and be physically feasible"). It keeps what the shear head does and does not change the pitch or the safety case; the closed drive case is also the guard for its two chains.

**R7 restated.** R7 now reads "at least 2.5 drums to flat sheet per hour for a two-person team" (DMP-REQ-001 v0.4), as Amish chose in 5A.

## Consequences

- R7: about 2.26 drums an hour for two people, 53.1 hands-on minutes a drum against the 48.0 that 2.5 drums an hour needs. Up from 2.0, but still not met. What to do about the remaining gap is posed to Amish in the register (DMP-DEC-001, Open decisions).
- R5: met on paper with a trial pass for each batch of drum steel.
- R6: met on paper; the hardest efforts are two ring cuts on 1.5 mm steel (136 N) and the punch lever on a chime (131 N).
- R11: the shear head with its drive is 23.7 kg, the ring head 20.4 kg and the punch 18.7 kg, all under the 25 kg one-person limit; the cradle frame (33.7 kg) is still the only two-person lift.
- Cost: value-engineering target USD 3,000. Estimated cost of the constructable design: USD 3,489 (USD 489 over the target). The changes added USD 695: notching punch USD 330 in place of the USD 45 hacksaw line, ring head USD 255, shear head drive USD 75, dial adjusters USD 40, tool shelf USD 40.
- The chime notch force is the least certain new number: a real chime's layers and clinch vary. It is to be confirmed on a scrap chime at TRL 4 (DMP-DEC-001, To confirm when parts are bought).
- The model (52 components), its checks (now with ring passes for both heads, crank sweeps and the four punch positions), the general arrangement DMP-DWG-001 Rev P2, making sketches DMP-DWG-105, 109, 110 and 116 at Rev P2 and new sketches DMP-DWG-120 to 123, the concept media and the build plan DMP-BLD-001 v0.2 are drawn from the changed model.

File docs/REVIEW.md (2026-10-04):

# Review note: DrumPanel

## Session 2026-09-30: scaffolded

### What was done

- Repository created from kit 1.6.0 at TRL 1, target TRL 2.
- `docs/01-problem.md` (DMP-PRB-001 v0.1): problem with cited evidence, users, environment, constraints, prior work, open questions.
- `docs/02-concept.md` (DMP-PRC-001 v0.1): how it works, components, patent design-arounds, shared blocks, safety.
- `docs/03-requirements.md` (DMP-REQ-001 v0.1): 9 proposed requirements.
- `README.md` with concept rationale, burning platform, where it could be used, and what sparked the idea.

### Next

- Run `/populate` to bring the repo to a strong TRL 2 with concept media.

## Session 2026-10-03: TRL 2 (populate), kit 1.7.0

Run as the first half of `/to-trl3` under Amish's pre-approval of 2026-10-03: "start with the first 14 repos from the list of 29 projects. I pre-approve the batch runs along with any recommendations you come up with. I also accept any cost overruns or variations from the assumed scope cost."

### What was done

- Kit 1.7.0 installed (`.kit/`, `.claude/commands/`, `CLAUDE.md`); `.kit/PHASE.yaml` as installed.
- `docs/01-problem.md` (DMP-PRB-001 v0.2): drum facts, the acceptance rule for drum contents, the first co-design candidate and a co-design checklist.
- `docs/03-requirements.md` (DMP-REQ-001 v0.2): targets firmed up; R10 guarding, R11 handling and R12 yield added.
- `docs/02-concept.md` (DMP-PRC-001 v0.2): how it works in three stations, key design choices, first-order numbers, safety.
- Concept media from the model (`cad/src/concept_media.py`): `media/hero.png`, `media/concept-blueprint.png` and `.pdf`, `media/model.glb` and `media/viewer.html`, `media/cutaway.png`, `media/exploded.png`, `media/flow.png` (material flow per drum, estimates).
- `bom/bom.csv` with every line priced.

### Results

- The five open questions of DMP-PRB-001 answered (purge by water, paint left on, steel range, shared set, first partner candidate).

### Requirements not met at TRL 2

- None found at concept level; R7 throughput was flagged for checking at TRL 3.

### Decisions made under the pre-approval (DMP-DDR-001)

- D1 water purge; D2 pumped LEL detector, pass below 5 % LEL; D3 accept only drums labelled for non-volatile oils; D4 panels left painted; D5 end cutter on the chime; D6 one rotary shear head; D7 slip roll; D8 steel range; D9 shared bench set; D10 standard crank and chain; D11 first co-design candidate to approach (not agreed); D12 slit beside the welded seam.

### Safety concerns

- Flammable vapour in "empty" drums is the main hazard; handled by the acceptance rule, the purge and a conservative 5 % LEL pass level (D2, D3).

## Session 2026-10-03: TRL 3 (advance, design for construction, build plan)

### What was done

- `cad/src/model.py`: parametric build123d model of the whole bench set, 42 components; `python cad/src/model.py --check` passes (no overlaps, 49 contacts, shear head clear in all six ring cut positions and at seven slit stations). STEP: `cad/step/drumpanel-bench-set.step`, `drain-stand.step`, `cutting-cradle.step`, `slip-roll-stand.step`, `rotary-shear-head.step`, `end-cutter.step`, `upper-pinch-roll.step`; STL of the shear head and end cutter.
- `docs/04-calcs/01-sizing.md` (DMP-CAL-001 v0.1) and `docs/04-calcs/sizing.py` (writes `results.csv`).
- `cad/drawings/DMP-DWG-001` general arrangement, Rev P1 (`cad/src/sheets.py`).
- `bom/bom.csv`: 24 lines, all priced.
- Design made constructable: `docs/decisions/0002-design-for-construction.md` (DMP-DDR-002); `design_state: constructable`.
- Build plan pictures (`cad/src/build_plan_media.py`): overview, 19 making sketches `cad/drawings/DMP-DWG-101` to `119`, 12 joint close-ups, 17 assembly steps.
- `docs/05-build-plan.md` (DMP-BLD-001 v0.1) and `docs/06-design-decisions.md` (DMP-DEC-001 v0.1).
- Precis DMP-PRC-001 v0.3, requirements DMP-REQ-001 v0.3, problem DMP-PRB-001 v0.3, README (hero render, build section, links), `project.yaml` at TRL 3.
- Appearance model `cad/src/product_model.py` (hero, exploded, detail); scenes exported to `/home/claude/renders/drumpanel` for the photoreal render on Amish's Mac.

### Key results (DMP-CAL-001)

- Output per drum: three panels 233, 234 and 233 x 1,800 mm and two head discs 552 mm.
- Crank forces: end cutter 27 N, shear head 111 N at 1.5 mm wall, slip roll 20 N (limit 150 N).
- Slip roll bending roll setting 13.4 mm nominal, 9.3 to 19.3 mm over likely steel; must be within 0.29 mm for R5.
- Throughput about 2.0 drums an hour for two people.
- Masses: cradle 130 kg, slip roll stand 189 kg, drain stand 15 kg; heaviest lift the 34 kg cradle frame.
- Value-engineering target: USD 3,000. Estimated cost of the constructable design: USD 2,794 (USD 206 under the target).

### Requirements not met

- **R7 not met:** about 2.0 drums an hour against 4. The hacksaw notches and six ring cuts make the cradle the bottleneck. Not redesigned beyond TRL 3; ideas are in the register's value engineering section.
- **R5 at risk:** flatness depends on setting the bending roll by a trial pass for each batch; the last 90 mm of each panel end is set by hand.

### Decisions made under the pre-approval

- DMP-DDR-002, changes P1 to P14 (see build plan findings below). All recorded in DMP-DEC-001 under Decisions made, dated 2026-10-03, decided by Amish with his pre-approval quote. Open decisions: none. Seven items to confirm when parts are bought.

### Build plan findings: design changes made for construction

- P1 fixed drain stand sloping 2.9 degrees; a full drum (240 kg) is never tipped.
- P2 rollers under the rolling hoops and a screw brake.
- P3 end cutter takes the head out inside the chime; the chime ring comes off with the shear head.
- P4 rotary shear head on a trolley and overhead rail; driven upper disc, idle lower disc, web in the cut.
- P5 hacksaw notches through the chime rings and hoops on the slit line.
- P6 slip roll (geared pinch pair, bending roll) instead of a three-roll pyramid, which cannot drive the sheet.
- P7 hoop strips cut out (rolling a hoop flat would stretch it 8.5 %); the body gives three panels, not one sheet.
- P8 head swivels 90 degrees for the six ring cuts.
- P9 guards with 8 mm slots, disc guard skirt, chain and gear guards, cutter cover.
- P10 panel ends set by hand on a bench plate.
- P11 side frames bolted to the base so the lower roll can be fitted.
- P12 rail posts moved out to 712.5 mm.
- P13 end cutter torque arm against a post.
- P14 drum height under the rail set by the levelling feet.

### Appearance model deviations (decided under the pre-approval)

- The chain is drawn as links on its straight runs only; a nameplate, a hazard label, painted drums, a floor and a 1.75 m mannequin are added for the look. The detail view shows a second state (drum with heads off, head halfway along the slit) that is not in `model.py`'s assembled state; its geometry is taken from `model.py`.

### Safety concerns

- Vapour: cut only after a purge and a check below 5 % LEL, with a bump-tested detector; only drums labelled for non-volatile oils. A log of 50 drums reviewed by a competent person could support relaxing the pass level to 10 % LEL.
- In-running nips at the discs, end cutter and rolls: all guarded on paper (ISO 13857 slots); a competent person must check the guards as built.
- Sharp cut edges: cut-resistant gloves and deburring before handling.
- Handling: a full drum is never lifted; two people for the 34 kg cradle frame.
- Oily purge water: settled and skimmed, never poured out.

### Recommended next step

- Photoreal renders on Amish's Mac from `/home/claude/renders/drumpanel` (`media/render-hero.png` is referenced by the README), then `python .kit/cards.py .`.
- When the portfolio phase allows TRL 4: approach the first co-design candidate and build to DMP-BLD-001, starting with the vapour check procedure and the slip roll trial pass.

## 2026-10-03: photoreal renders

Rendered with Blender Cycles on Amish's Mac from `cad/src/product_model.py`; captioned with `.kit/photo_caption.py`; `media/card.png` and `media/social-preview.png` made with `.kit/cards.py`. Views: hero, exploded, detail. image_qc passes and `render.py --check` has no FAIL.

## 2026-10-03: Amish's requirement decisions carried out

Amish chose option A on every requirement decision put to him: "1A 2A 3A 4A 5A 6A 7A 8A 9A 10A 11A". For DrumPanel these are 5A (R7) and 8A (R5). Record: `docs/decisions/0003-requirement-decisions-2026-10-03.md` (DMP-DDR-003).

### Changes and new results

- **Lever notching punch (5A).** A two-station C-frame punch replaces the four hacksaw notches (`cad/src/model.py`, BOM line 21, sketch DMP-DWG-121, joint 14). The chime notch is widened from 40 to 60 mm so the punch's lower jaw passes through it to reach the hoop. Chime notch 24.3 kN, lever 131 N; hoop slot 6.6 kN, lever 36 N [K1 to K4]; four notches in 4.0 minutes, down from 8.
- **Ring head (5A).** A second shear head bolted to the main head with a spacer plate and a coupling in a guard sleeve makes two ring cuts a pass (BOM line 25, sketch DMP-DWG-122, joint 13). Six ring cuts in three passes, 9.5 minutes, down from about 12.4; 20.4 kg.
- **R7 restated to 2.5 drums an hour (5A).** DMP-REQ-001 v0.4. New result: about 2.26 drums an hour (53.1 hands-on minutes a drum against 48.0 needed). **R7 not met**, up from 2.0.
- **Fine-pitch dial adjuster (8A).** M20 x 1.5 bending screws, 60-division dials (0.025 mm) and lock nuts (BOM line 15, sketch DMP-DWG-116 Rev P2). The 0.29 mm allowance is 11.8 divisions [E14d]. **R5 met on paper** with a trial pass for each batch (was at risk).
- **Raised shear head drive (design for construction, found while carrying out 5A).** The former 200 mm crank on the upper shaft swept through the drum wall (about 13,700 mm³ in the new sweep check), so it could not turn. The crank now sits on a raised crank shaft in a closed 2.33 to 1 #35 chain drive case, 155 mm (BOM line 10, sketch DMP-DWG-120). Slit crank 68 N, two ring cuts 136 N at 1.5 mm wall. **R6 met on paper** (worst 136 N). Slit time 2.7 minutes, up from 2.3.
- **Tool shelf** on the left rail post for the punch and ring head (BOM line 26, sketch DMP-DWG-123).
- **R11:** shear head with drive 23.7 kg, ring head 20.4 kg, punch 18.7 kg; met with the two-person rule for the 33.7 kg cradle frame.
- **Cost (R9):** Value-engineering target: USD 3,000. Estimated cost of the constructable design: USD 3,489 (USD 489 over the target). The decisions added USD 695; every new BOM line carries its price basis.
- **Masses:** cradle station with its tools 196 kg, slip roll stand 191 kg, drain stand 15 kg.

### Files

- Model and checks: `cad/src/model.py`, 52 components; `--check` passes (no overlaps, all contacts, three ring passes with both heads, crank sweeps in both modes, four punch positions). New STEP: `cad/step/notching-punch.step`, `cad/step/shear-head-with-ring-head.step`; STL `cad/stl/notching-punch.stl`; all others regenerated.
- Calculations: `docs/04-calcs/01-sizing.md` (DMP-CAL-001 v0.2, new section 9) and `sizing.py`, `results.csv`.
- Drawings: DMP-DWG-001 Rev P2; DMP-DWG-105, 109, 110, 116 Rev P2; new DMP-DWG-120 to 123.
- Build plan DMP-BLD-001 v0.2: overview, joints 6, 9, 13 and 14, steps 8 to 18 (new step 10; former steps 10 to 17 renumbered 11 to 18), new sections 3.13 to 3.15.
- Concept media: hero, exploded, cutaway, model.glb, concept blueprint (Rev P2). Precis DMP-PRC-001 v0.4; register DMP-DEC-001 v0.2; README cost and build lines.
- Appearance model `cad/src/product_model.py` (drive case, tool shelf, punch, ring head, dials; new group "tools" in the hero and exploded views); scenes exported to `/home/claude/renders/drumpanel`. Photoreal renders not redone: `media/render-hero.png` and the other renders now predate these changes.

### Decisions proposed and awaiting Amish

- **R7 gap (register, open decision 1).** About 2.26 against 2.5 drums an hour. Options: A keep 2.5 and let the TRL 4 timed trial decide; B restate R7 to 2.25; C add more speed-ups now (rail stops for the ring passes, a second deburring station). Recommendation: A, because the gap is about 10 % of hands-on time, inside the uncertainty of the task-time estimates.

### Safety

- New hazards covered in the build plan: the coupling shaft turns in a guard sleeve; both shear head chains are inside the closed drive case; the punch moves only by its screw, hands on the lever (safety stop S10). The chime punch force is the least certain number and is to be confirmed on a scrap chime (register, item 8).

## 2026-10-03: photoreal renders redone after Amish's requirement decisions

Rendered with Blender Cycles on Amish's Mac from `cad/src/product_model.py`; captioned with `.kit/photo_caption.py`; `media/card.png` and `media/social-preview.png` made with `.kit/cards.py`. Views: hero, exploded, detail. image_qc passes and `render.py --check` has no FAIL.

## 2026-10-03: Amish's round-2 requirement decisions carried out

Amish, 2026-10-03: "i agree with all the 46 recommendations you provided. please proceed." For DrumPanel this is decision 5A on R7, recorded in `docs/decisions/0004-r7-kept-at-2-5-drums-an-hour.md` (DMP-DDR-004) and in the register `docs/06-design-decisions.md` (DMP-DEC-001 v0.3). A records and wording change only: no geometry, bill of materials, drawing or picture changed.

| Change | Files | New result |
| --- | --- | --- |
| R7 kept at 2.5 drums an hour; the TRL 4 timed trial decides | `docs/03-requirements.md` v0.5, `docs/05-build-plan.md` (Throughput check wording), `docs/06-design-decisions.md` v0.3, DMP-DDR-004 | **R7 not met on paper: about 2.26 drums an hour, 53.1 hands-on minutes a drum against 48.0**; the gap is about 10 % of hands-on time, inside the estimate's uncertainty; the trial decides |
| Open decision 1 closed | register v0.3 | Open decisions: none |
| Cost | unchanged | Value-engineering target: USD 3,000. Estimated cost of the constructable design: USD 3,489 (USD 489 over the target). `budget_usd` unchanged |

Mass unchanged. Pictures changed: none; the appearance model is unchanged and no views were re-exported.

### Decisions proposed, awaiting Amish

None.

### Cross-repo actions

None.

### Safety

The throughput target never justifies skipping a vapour stop: S4 and S5 apply to every drum.

### Recommended next step

TRL 4 (the timed half-day trial, with each task timed, is the test that decides R7) needs a new instruction from Amish.

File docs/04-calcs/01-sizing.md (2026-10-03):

---
doc_id: DMP-CAL-001
title: DrumPanel sizing calculations
project: DrumPanel
doc_type: Calculation
version: "0.2"
status: Draft
date: '2026-10-03'
author: Amish Chadha
license: CERN-OHL-S-2.0
revisions:
- version: "0.1"
  date: '2026-10-03'
  author: Amish Chadha
  change: First issue at TRL 3, on the constructable design of DMP-DDR-002
- version: "0.2"
  date: '2026-10-03'
  author: Amish Chadha
  change: Amish's requirement decisions of 2026-10-03 (DMP-DDR-003); lever notching punch (new section 9), ring head and raised shear head drive, fine-pitch dial adjuster, throughput against R7 restated to 2.5 drums an hour, masses and cost
---

# DrumPanel sizing calculations

On paper the DrumPanel bench set meets ten of its twelve requirements and misses one, and its estimated cost is over the value-engineering target. Every crank and lever force is at or below 136 N against the 150 N limit of R6, and the guards meet ISO 13857 on paper. R7, restated by Amish on 2026-10-03 to 2.5 drums an hour, is not met: with the lever notching punch, the ring head and the dial-set bending roll, two people would turn about 2.26 drums an hour into flat panels, up from 2.0. R5 is met on paper with a trial pass for each batch: the slip roll leaves a panel flat only when its bending roll is within about 0.29 mm of the right height for that batch of drum steel, and the new fine-pitch dial sets and holds that height to 0.025 mm, about a twelfth of the allowance; the last 90 mm at each panel end is still set by hand. Value-engineering target: USD 3,000. Estimated cost of the constructable design: USD 3,489 (USD 489 over the target). Rolling the hoops flat would stretch their crowns about 8.5 %, which is why the hoops are cut out and the body becomes three panels about 233 x 1,800 mm. Every number in this note is printed by `docs/04-calcs/sizing.py`; the tag in brackets, for example [D15], is the line of that script's output that carries it.

> **Safety:** These are first-principles estimates for a paper proof of concept. They do not show that a purged drum is free of vapour, that the guards are safe as built, or that the frames carry their loads in service. The vapour check, the guard openings and the drain stand must be checked on hardware before any drum is cut. See DMP-PRC-001, Safety.

## Scope and method

The note checks every requirement in DMP-REQ-001 v0.4 against the design in DMP-PRC-001 v0.4 and the parametric model `cad/src/model.py`. The script imports the model's `PARAMS`, `levels()` and `components()`, so the drum, rollers, shear head, slip roll and guards used here are the ones in the STEP files and in drawing DMP-DWG-001. It reads `bom/bom.csv` for the cost and `budget_usd` in `project.yaml` for the target. Run it from the repo root with `python docs/04-calcs/sizing.py`; it also writes `docs/04-calcs/results.csv`. The model's own checks (`python cad/src/model.py --check`) show that no two of its 52 parts overlap, that every joint face touches, that the shear head with the ring head bolted on clears the drum in all three ring passes and alone at seven stations along the slit, that its crank sweeps clear of the drum, the posts, the rail beam and the trolley in both modes, and that the notching punch fits each of the four notches with its die faces on the steel.

## Assumptions

*Table 1. Main assumptions.*

| Area | Assumption | Basis |
| --- | --- | --- |
| Drum | 572 mm inside diameter, 880 mm over the chimes, body 1.0 mm (0.8 to 1.2), heads 1.2 mm (1.0 to 1.5), hoops 298.5 mm outside radius at 147 mm each side of the middle | Common 55 US gallon tight-head drums |
| Steel | Yield 250 MPa (200 to 300), tensile strength 360 MPa, shear strength 0.8 of tensile, modulus 200 GPa, elastic and perfectly plastic in bending | Low-carbon drum sheet; screening values |
| Shearing | Force = shear strength x t² / (2 tan of the nip angle); feed resistance = force x tan of half the nip angle; discs overlap 1.0 mm | Standard rotary shear estimate |
| Edge spreading | Pushing the cut edges round the 10 mm web adds 100 N at 1.2 mm, scaling with the cube of the wall | Estimate, to confirm at TRL 4 |
| Traction | Driven shear disc: effective friction 0.3 (the edge bites); knurled end cutter wheel 0.3; steel pinch rolls on painted steel 0.15 | Screening values |
| Losses | 20 % for the shear head bearings and idle disc; 30 % for the end cutter's rollers; bronze bushes friction 0.10; chain 95 % | Screening values |
| Slip roll | Panels fed three side by side (700 mm); pinch rolls 60 mm, bending roll 90 mm behind the pinch line; pinch force 2 kN set by two M16 screws | Model geometry |
| Notching punch | Inclined-edge shear per edge 0.5 x shear strength x t² / tan(rake), punch faces raked 10 degrees; the chime is five layers; 20 % for stripping; Tr24 x 5 screw, friction 0.15 | Screening values; the chime force is to confirm on a scrap chime at TRL 4 |
| Work rate | 30 crank turns a minute; times for loading, setting up and handling as listed in section 8 | Estimates for a practised two-person team |
| Purge | Hose at 20 L/min; 50 mm bung, discharge coefficient 0.6 | Screening values |

## 1. What a drum yields

After the two heads, the two chime rings and the two hoop strips are cut out, the body gives three panels and the heads give two discs.

*Table 2. Output per drum.*

| Quantity | Value | Tag |
| --- | --- | --- |
| Panel length (body circumference at mid-wall) | 1,800 mm | [A1] |
| Panel widths, outer, middle, outer | 233, 234 and 233 mm | [A2] |
| Head discs, two | 552 mm across | [A3] |
| Flat area: panels; heads | 1.26 m²; 0.48 m² | [A4, A5] |
| Empty drum; three panels at 1.0 mm | 19.2 kg; 9.9 kg | [A6, A7] |

The rest of the steel comes off as two chime rings and two hoop strips, about 4.8 kg, which artisans can use as strip.

## 2. Drain and purge

A full drum is filled and drained on its stand, never lifted. The stand slopes 2.9 degrees toward the bung end so it drains to within about 1.4 L.

*Table 3. Purge and the drain stand.*

| Quantity | Value | Tag |
| --- | --- | --- |
| Inside volume (brimful) | 221 L | [B1] |
| Drum full of water | 240 kg | [B2] |
| Fill time at 20 L/min | 11.0 min | [B3] |
| Drain time through the 2 in bung | 2.3 min | [B4] |
| Water left below the bung opening | 1.4 L | [B5] |
| Contact on the chocks, from vertical | 31.5 deg | [B6] |
| Normal force on each chock, full drum | 691 N | [B7] |
| Bending stress in a saddle, full drum | 10.4 MPa | [B8] |
| Compressive stress in a leg, full drum | 1.3 MPa | [B9] |

The stresses are small against the 275 MPa yield of S275; the stand is sized by handling and welding, not strength. The purge itself is a procedure, not a calculation: fill, soak 10 minutes with detergent, drain, then check (DMP-DDR-001, D1 and D2). Whether one fill is enough for a given drum is what the vapour check decides; a failed check means a second fill.

## 3. End cutter

The end cutter needs little force: the cut is short-stroke shearing of the head against the chime's inside wall.

*Table 4. End cutter, 50 mm cutter wheel, 40 mm drive wheel, 150 mm crank.*

| Head thickness | Cut force | Feed resistance | Drive torque | Crank force | Tag |
| --- | --- | --- | --- | --- | --- |
| 1.0 mm | 429 N | 70 N | 1.8 N·m | 12 N | [C10] |
| 1.2 mm | 571 N | 100 N | 2.6 N·m | 17 N | [C12] |
| 1.5 mm | 807 N | 156 N | 4.1 N·m | 27 N | [C15] |

The drive wheel and guide roller must pinch the chime with about 520 N for the knurl to drive a 1.5 mm head [C20]; the cutter's clamp screw sets this. One trip round a head is 13.8 crank turns, about half a minute [C21, C22].

## 4. Rotary shear head

The shear head with the ring head bolted on is the hardest crank in the set: two ring cuts at once on a 1.5 mm wall need 136 N, inside the 150 N limit of R6.

The crank is no longer on the upper shaft. A 200 mm crank there swept through the drum wall in both slit and ring modes (the model's sweep check found about 13,700 mm³ of overlap), so it could not make a full turn. The crank now sits on a raised crank shaft in a drive case on the side of the head: a 12 tooth to 28 tooth #35 chain to a jackshaft, then a 15 tooth to 15 tooth chain down to the upper shaft, 2.33 to 1 overall, with a 155 mm crank (DMP-DDR-003, Q3). The reduction keeps two ring cuts on one crank within R6; the drive case is the chain guard.

*Table 5. Shear head, 101 mm discs, 1.0 mm overlap, 155 mm crank through a 2.33 to 1 drive (chains 95 % each).*

| Wall | Separating force | Nip angle | Feed resistance | Crank force, one cut (slit) | Crank force, two ring cuts | Traction over resistance | Tag |
| --- | --- | --- | --- | --- | --- | --- | --- |
| 0.8 mm | 482 N | 10.8 deg | 85 N | 16 N | 32 N | 1.69 | [D8, D8r] |
| 1.0 mm | 713 N | 11.4 deg | 139 N | 26 N | 52 N | 1.54 | [D10, D10r] |
| 1.2 mm | 977 N | 12.0 deg | 213 N | 39 N | 79 N | 1.38 | [D12, D12r] |
| 1.5 mm | 1,429 N | 12.8 deg | 365 N | 68 N | 136 N | 1.17 | [D15, D15r] |

Only the upper disc of each head is driven, because a gear between the discs would have to pass through the drum wall. With the ring head on, a coupling shaft joins the two upper shafts, so each head drives its own cut and the traction margin is the same as for one head. At 1.5 mm the driven disc has 17 % more traction than it needs; if it slips on a thick drum, the operator pushes the trolley along by hand while cranking. The separating force is carried round the frame: the 10 mm web sees 12.1 MPa and a 25 mm shaft 17.7 MPa [D20, D21]. At 30 crank turns a minute the discs now cut at 4.08 m/min [D22], about 2.3 times slower than a direct crank; the ring head more than wins this back by halving the number of ring passes (section 8). The trolley, drop bar and head with its drive weigh 28.2 kg and bend the rail beam 0.15 mm at mid-span [D23, D24].

### 4.1 Ring head

The ring head is a second shear head, made to the same drawings without a drive, that is lowered through the slit and bolted to the main head with a 10 mm spacer plate once the main head is swivelled for ring cuts (DMP-DDR-003, Q2). Its nip sits 233 mm along the drum from the main head's (234 mm for the middle pass), so the six ring cuts are made in three passes: the left chime ring with the left hoop's outer side, the two inner hoop sides, and the right hoop's outer side with the right chime ring. It weighs 20.4 kg with its spacer plate and coupling [D25]; with both heads at mid-span the rail beam bends 0.26 mm [D26], and the spacer plate carrying the ring head 233 mm out sees 24.4 MPa [D27].

## 5. Slip roll: reverse bending to flat

### 5.1 Why the hoops are cut out

A rolling hoop stands about 12 mm out from the body wall. Bent to the reverse curvature the slip roll needs, its crown would be stretched about 8.5 % [E29], far past what the sheet can take without tearing or buckling. So the hoop strips are cut out with the shear head (DMP-DDR-002, P7) and only flat panels go through the rolls.

### 5.2 The setting that leaves a panel flat

A panel leaves the drum curled to a 286.5 mm radius [E1]. To come out flat, it must be bent the other way past the elastic limit by just the right amount, so that it springs back to flat. For an elastic and perfectly plastic sheet the change of curvature x (in units of the elastic limit curvature) must satisfy x - M(x) / M_e = drum curvature / elastic limit curvature, where M / M_e = 1.5 (1 - 1 / (3 x²)). The script solves this for each steel and wall, then finds the bending roll height that bends the panel to that radius between the pinch line and the bending roll 90 mm behind it.

*Table 6. Settings and forces for the three panels fed together (700 mm).*

| Yield | Wall | Reverse radius | Bending roll above lower roll | Moment | Bending roll force | Feed resistance | Tag |
| --- | --- | --- | --- | --- | --- | --- | --- |
| 200 MPa | 0.8 mm | 278 mm | 13.4 mm | 21.5 N·m | 239 N | 71 N | [E200-8] |
| 200 MPa | 1.0 mm | 345 mm | 11.0 mm | 33.9 N·m | 376 N | 112 N | [E200-10] |
| 200 MPa | 1.2 mm | 411 mm | 9.3 mm | 49.1 N·m | 545 N | 163 N | [E200-12] |
| 250 MPa | 0.8 mm | 225 mm | 16.4 mm | 26.6 N·m | 295 N | 87 N | [E250-8] |
| 250 MPa | 1.0 mm | 278 mm | 13.4 mm | 41.9 N·m | 466 N | 138 N | [E250-10] |
| 250 MPa | 1.2 mm | 331 mm | 11.4 mm | 60.8 N·m | 676 N | 201 N | [E250-12] |
| 300 MPa | 0.8 mm | 189 mm | 19.3 mm | 31.6 N·m | 351 N | 103 N | [E300-8] |
| 300 MPa | 1.0 mm | 234 mm | 15.8 mm | 49.9 N·m | 554 N | 164 N | [E300-10] |
| 300 MPa | 1.2 mm | 278 mm | 13.4 mm | 72.5 N·m | 805 N | 239 N | [E300-12] |

The nominal setting is 13.4 mm [E10]; the range over likely drum steel is 9.3 to 19.3 mm [E11], well inside the 60 mm of slot travel.

### 5.3 The trial pass and the dial adjuster (R5)

The setting is sensitive. If the nominal setting were used on steel at the edges of the range, a panel could sag up to 188 mm over 1 m [E12]. To stay within the 10 mm over 1 m of R5, the bending roll must be within 0.29 mm of the right height [E13]. With the former M20 x 2.5 screws and 12-division handwheels that allowance was only about 1.4 divisions [E14c], so the setting was at risk.

Each bending screw is now a fine-pitch M20 x 1.5 screw with an 80 mm dial of 60 divisions, 0.025 mm each, read against a pointer on the bridge, and a lock nut that holds the setting (DMP-DDR-003, Q4). The 0.29 mm allowance is 71 degrees of a turn, or 11.8 divisions [E14, E14d], so both ends can be set to the same reading well inside it and returned to after a change. The right height still depends on the batch of drum steel, so the first panel of each batch is passed, checked with a straightedge, and the dials adjusted until it comes out flat; the reading is then written on the batch and every later drum is set to it. R5 is met on paper with this trial pass; a TRL 4 trial will show how many passes the first panel of a batch takes.

### 5.4 Panel ends

The slip roll cannot bend the leading 90 mm of a panel (from the pinch line to the bending roll) [E15]; left alone, that end would stand 14.1 mm above flat [E16]. The ends are set flat by hand with a dead-blow mallet over the edge of the bench plate. This is quieter and far shorter work than the hammering it replaces.

### 5.5 Drive, rolls and bushes

*Table 7. Slip roll drive and parts, worst case (300 MPa, 1.2 mm).*

| Quantity | Value | Tag |
| --- | --- | --- |
| Bending roll force | 805 N | [E17] |
| Feed resistance | 239 N | [E18] |
| Pinch force needed (friction 0.15, margin 1.5) | 1,193 N | [E19] |
| Pinch force set by the two M16 screws | 2,000 N | [E20] |
| M16 screw torque for 1 kN; force on the 90 mm handwheel rim | 3.2 N·m; 71 N | [E21] |
| Torque to turn the pinch rolls | 16.8 N·m | [E22] |
| Crank force at 300 mm through the 3:1 chain | 20 N | [E23] |
| Feed speed at 30 crank turns a minute | 1.9 m/min | [E24] |
| Upper pinch roll load; mid-span deflection | 2,805 N; 0.25 mm | [E25] |
| Upper pinch roll bending stress | 15.5 MPa | [E26] |
| Bronze bush pressure | 2.3 MPa | [E27] |
| Pinch gear tooth stress (Lewis) | 15 MPa | [E28] |

Every part runs far below its limits; the rolls are 60 mm because they must stay straight to a fraction of the 0.29 mm setting tolerance, not for strength.

## 6. Cutting cradle

The drum sits on its hoops at 33 degrees from vertical each side [F2], with its axis 603 mm and its top 890 mm from the floor [F1], a comfortable height for the crank work. With 1 kN on the drum (the drum plus a person leaning on it) a roller shaft sees 72 MPa and bends 3.2 mm at mid-span [F3]; under the drum alone it bends about 0.6 mm. A sideways push of 122 N rolls an empty drum over a roller [F4], so the drum brake is used whenever the drum must stay still.

## 7. Guards (ISO 13857, slot openings)

ISO 13857 Table 4 allows a slot opening of up to 8 mm when the danger point is at least 20 mm behind it.

*Table 8. Guard openings.*

| Opening | Slot | Distance to the nip | Needed | Result | Tag |
| --- | --- | --- | --- | --- | --- |
| Slip roll in-feed slot under the nip guard | 8.0 mm | 45 mm | 20 mm | Meets | [G1] |
| Slip roll out-feed slot | 8.0 mm | 85 mm | 20 mm | Meets | [G2] |
| Shear head front skirt over the sheet | 7.5 mm | 52 mm | 20 mm | Meets | [G3] |

The slip roll chain, sprockets and pinch gears are fully enclosed, and so are the shear head's two chains, inside its drive case. The coupling shaft between the main head and the ring head is a smooth 25 mm shaft turning at about 13 revolutions a minute inside a loose guard sleeve. The end cutter's wheel works inside the head recess under a sheet cover. The notching punch moves only as its screw is turned by the lever, with the hands 480 mm from the punch. These are desk checks on the model; a competent person checks the guards as built before any trial.

## 8. Throughput

Two people turn about 2.26 drums an hour into flat panels [H5], against the 2.5 of R7 as restated by Amish on 2026-10-03. R7 is not met: 2.5 drums an hour needs 48.0 hands-on minutes per drum [H9], and the estimate is 53.1 [H4].

*Table 9. Hands-on minutes per drum.*

| Station | Before (DMP-CAL-001 v0.1) | Now | Tag |
| --- | --- | --- | --- |
| Purge and vapour check | 14 | 14 | [H1] |
| Cutting cradle: load, two heads, four notches, slit, six ring cuts, unload | 30.1 | 23.6 | [H2] |
| Slip roll and finishing: setting, three passes, handling, panel ends, deburring | 17.1 | 15.6 | [H3] |
| Total | 61.2 | 53.1 | [H4] |
| Drums per hour for two people | 2.0 | 2.26 | [H5] |

What changed at the cradle [H8]: the four notches take 4.0 minutes with the lever notching punch, down from 8 with a hacksaw (1.2 minutes for each chime notch, 0.8 for each hoop slot [K9]). The six ring cuts take 9.5 minutes in three passes with the ring head, down from about 12.4 in six, including a minute a drum to bolt the ring head on and take it off. The slit takes 2.7 minutes, up from 2.3, because the new drive turns the discs 2.33 times slower. At the slip roll, the dial lets every drum after the first of a batch be set to a written reading: the trial pass is taken as 10 minutes for a batch of about ten drums plus half a minute a drum to check the dials, 1.5 minutes a drum in all, down from 3.

The purge takes about 22.9 minutes elapsed but runs while the cradle works [H6]. Taking both heads off is about 3.9 minutes [H7]. The remaining gap of about 5 minutes a drum is spread over handling, setting up the ring passes and deburring; ways to close it are listed in the design decisions register (DMP-DEC-001, Open decisions and Value engineering). Even at 2.26 drums an hour, a two-person team turns a drum into panels in under 30 minutes, against the hours of fire and chisel work the method replaces.

## 9. Lever notching punch

The discs cannot start a cut through a folded chime or a hoop ridge, so four notches are made on the slit line first: an open-ended notch 60 x 35 mm at each drum end through the chime, and a slot 40 x 32 mm through each hoop. The lever notching punch replaces the hacksaw for these (DMP-DDR-003, Q1). It is a C-frame that slides into the open drum end with its lower jaw inside the drum: station 1, at the back of the frame, notches the chime with the frame's back face on the drum end; station 2, 338 mm out, slots the hoop with the drum end against the station 1 die block, its lower jaw passing in through the chime notch already cut. Each station has a D2 punch with its face raked 10 degrees, pushed into a matching die by a Tr24 x 5 screw turned by a 500 mm ratchet lever.

*Table 10. Lever notching punch, 1.5 mm steel (the worst case of the accepted range).*

| Quantity | Chime notch | Hoop slot | Tag |
| --- | --- | --- | --- |
| Punch force | 24.3 kN | 6.6 kN | [K1, K2] |
| Screw torque; lever force at 480 mm | 63 N·m; 131 N | 17 N·m; 36 N | [K3, K4] |
| Jaw root bending stress, lower and upper jaw | 18 and 18 MPa | 96 and 93 MPa | [K5, K6] |
| Lever swings under load (60 degrees each) | 18 | 8 | [K8] |
| Time per notch | 1.2 min | 0.8 min | [K9] |

The chime notch is the hard one: the punch shears five layers of the folded seam. The lever force of 131 N is within R6, and the jaws, S355 plate, are at about a third of yield at the hoop station. Under the hoop slot force the jaws open about 1.3 mm at the hoop station [K7]; the punch is guided in its boss, so this is taken up in the screw stroke rather than shifting the punch off its die. The chime force is the least certain number here, because a real chime seam's layers and its clinch vary; it is to be confirmed on a scrap chime at TRL 4. The punch weighs 18.7 kg and is carried to the drum by one person [I9].

## 10. Masses

*Table 11. Masses (steel at 7,850 kg/m³; chocks, tray, bushes and plywood at their own densities).*

| Item | Mass | Tag |
| --- | --- | --- |
| Drain and purge stand with tray | 15 kg | [I1] |
| Cutting cradle with posts, beam, shear head, ring head, end cutter, notching punch and tool shelf | 196 kg | [I2] |
| Slip roll stand with tables | 191 kg | [I3] |
| Heaviest lift: cradle frame, one welded piece | 33.7 kg | [I4] |
| Shear head with shafts, discs, guard, drive and drop bar | 23.7 kg | [I5] |
| Lower pinch roll | 21.0 kg | [I6] |
| Ring head with its spacer plate and coupling | 20.4 kg | [I7] |
| Side frame with legs and bridge, each | 20.1 kg | [I8] |
| Notching punch, carried to the drum | 18.7 kg | [I9] |

Only the cradle frame is over the 25 kg one-person limit of R11; it is lifted by two people. The shear head with its drive (23.7 kg) and the ring head (20.4 kg) are under the limit but awkward to hold while bolting; the build plan fits each with a second person steadying it.

## 11. Cost

Value-engineering target: USD 3,000. Estimated cost of the constructable design: USD 3,489 (USD 489 over the target) [J1 to J3]. The decisions of 2026-10-03 added USD 695: the notching punch (USD 330, replacing the USD 45 hacksaw line), the ring head (USD 255), the shear head drive (USD 75), the dial adjusters (USD 40) and the tool shelf (USD 40). The largest lines are now the vapour check kit (USD 600), the shear head (USD 340), the notching punch (USD 330) and the three rolls (USD 285) [J4 to J7].

## 12. Results against the requirements

*Table 12. Requirement status at TRL 3.*

| ID | Requirement | Result | Status |
| --- | --- | --- | --- |
| R1 | No open flame | All steps cold | Met by design |
| R2 | Vapour check flags 10 % LEL | Detector alarm at 5 % LEL | Met by design |
| R3 | Both heads off in under 10 min | 3.9 min [H7] | Met on paper |
| R4 | Straight slit, 5 mm | Rail-guided head | Met by design |
| R5 | Flat within 10 mm over 1 m | Needs 0.29 mm setting accuracy [E13]; dial reads 0.025 mm, the allowance is 11.8 divisions [E14d]; set by a trial pass for each batch; ends hand-set [E16] | Met on paper, with a trial pass for each batch |
| R6 | Crank force at or below 150 N | 136 N worst, two ring cuts at 1.5 mm [D15r]; punch lever 131 N [K3] | Met on paper |
| R7 | 2.5 drums an hour, two people (restated 2026-10-03) | 2.26 drums an hour [H5] | **Not met** |
| R8 | Local build | Welding, drilling, turning; bought discs and bearings | Met by design |
| R9 | Value-engineering target USD 3,000 | USD 3,489 [J1] | Over the target by USD 489 |
| R10 | Guarding | All slots meet ISO 13857 on paper [G1 to G3] | Met on paper |
| R11 | Handling | 33.7 kg frame by two people [I4]; every other piece 23.7 kg or less [I5 to I9]; full drum never lifted | Met with a two-person rule |
| R12 | Yield | Three panels 233 to 234 x 1,800 mm, two 552 mm heads [A1 to A3] | Met by design |

## Where the numbers come from

- `docs/04-calcs/sizing.py` (this note's script) and `docs/04-calcs/results.csv`.
- `cad/src/model.py`: geometry, `PARAMS`, `levels()`, fit checks.
- `bom/bom.csv` and `project.yaml`.
- ISO 13857:2019, Safety of machinery: safety distances to prevent hazard zones being reached by upper and lower limbs, Table 4.

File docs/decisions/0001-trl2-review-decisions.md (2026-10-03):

---
doc_id: DMP-DDR-001
title: DrumPanel TRL 2 review decisions
project: DrumPanel
doc_type: Design decision record
version: "0.1"
status: Draft
date: '2026-10-03'
author: Amish Chadha
license: CERN-OHL-S-2.0
revisions:
- version: "0.1"
  date: '2026-10-03'
  author: Amish Chadha
  change: TRL 2 review items and the open questions of DMP-PRB-001 decided under Amish's pre-approval of 2026-10-03
---

# 0001: TRL 2 review decisions

- **Date:** 2026-10-03
- **Status:** accepted. Decided by Amish under his pre-approval of 2026-10-03: "start with the first 14 repos from the list of 29 projects. I pre-approve the batch runs along with any recommendations you come up with. I also accept any cost overruns or variations from the assumed scope cost."

## Context

The TRL 2 review (`docs/REVIEW.md`, session 2026-10-03, TRL 2) found five open questions in DMP-PRB-001 v0.1 and eight key design choices for the precis. Amish pre-approved every recommendation for this batch, so each is recorded here as decided. Choices that touch safety take the conservative option, and each says what evidence would relax it. Partners and regions are the first candidate to approach, not agreed.

## Options considered

*Table 1. Options for each item.*

| # | Item | Options | Chosen |
| --- | --- | --- | --- |
| D1 | Purge method | (a) water fill with detergent, soak and drain; (b) air flush with a blower; (c) steam | (a): no power or fuel; water reused through a settling drum |
| D2 | Vapour check | (a) bought pumped LEL detector, pass below 5 % LEL; (b) pass below 10 % LEL; (c) indicator tubes or a smell test | (a), the conservative threshold |
| D3 | Drums accepted | (a) only drums labelled for non-volatile oils (flash point above 60 °C); (b) any drum after purge | (a), the conservative rule |
| D4 | Paint | (a) panels leave painted, paint removal a separate cold step; (b) a stripping station in the set | (a) |
| D5 | Heads | (a) hand-cranked wheel cutter on the chime, after US3161952A; (b) chisel; (c) bought deheader | (a) |
| D6 | Side and rings | (a) one hand-cranked rotary shear head for the slit and the ring cuts; (b) lever shear; (c) separate tools | (a) |
| D7 | Flattening | (a) hand slip roll; (b) three-roll pyramid; (c) hammering | (a); see DMP-DDR-002, P6 |
| D8 | Steel range | Body 0.8 to 1.5 mm, heads 1.0 to 1.5 mm; forces sized at 1.5 mm | As stated |
| D9 | Ownership | (a) one shared bench set per cooperative or cluster; (b) one per workshop | (a) |
| D10 | Shared blocks | (a) standard 300 mm crank with #40 chain, drawn to accept the proposed hand capstan block later; (b) wait for the block | (a) |
| D11 | First co-design partner | (a) Haitian metal artists reached through a fair trade organisation already working with them (first candidate: Singing Rooster), a vocational welding school second; (b) a vocational school first | (a), first candidate to approach only; nothing agreed |
| D12 | Slit position | (a) 50 mm beside the drum's welded side seam; (b) through it | (a): the shear cannot cut the seam weld cleanly |

## Decision

*Table 2. Decisions.*

| # | Decision | Safety note: evidence that would relax it |
| --- | --- | --- |
| D1 | Water fill with a little detergent through the top bung, soak 10 min, drain through the bottom bung; repeat if the check fails. Water settles in a spare drum; oil is skimmed for a recycler | Not a safety relaxation |
| D2 | Pumped LEL detector, bump-tested each day; a drum passes only below 5 % LEL at both bungs; recheck a drum that stands overnight | A log of at least 50 drums with readings, reviewed by a competent person, could support the 10 % LEL limit used for hot work, since cold cutting is a smaller ignition source |
| D3 | Only drums labelled for non-volatile oils; fuel, solvent, chemical, unknown and unlabelled drums are rejected | A supplier audit and a validated purge for a named product could add it to the accepted list |
| D4 | Panels painted; paint removal outside the design, cold only | None needed |
| D5 | End cutter with a hardened wheel cutting just inside the chime | None needed |
| D6 | One shear head, swivelled 90 degrees between slit and ring position | None needed |
| D7 | Slip roll (pinch pair plus bending roll) | None needed |
| D8 | Steel range as stated | None needed |
| D9 | Shared bench set | None needed |
| D10 | Standard crank and chain now | None needed |
| D11 | First candidate to approach as stated; not agreed | None needed |
| D12 | Slit 50 mm beside the welded seam | None needed |

## Consequences

The purge, vapour check and acceptance rule are written into DMP-PRC-001 and DMP-BLD-001 and into the procedure sheets (BOM line 22). The vapour check kit is the largest cost line (USD 600). D6 and D7 set the shape of the constructable design in DMP-DDR-002.

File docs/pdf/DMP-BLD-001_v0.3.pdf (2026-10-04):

D R U M PA N E L · B U I L D P L A N

# DrumPanel prototype build plan

Design Molecule Lab · designmolecule.com

D O C U M E N T CO N T RO L

Document ID | DMP-BLD-001 | Version | 0.3
Status | Draft | Date | 2026-10-03
Author | Amish Chadha | License | CERN-OHL-S-2.0
Project TRL | TRL 3 | Proof of concept
Repository | github.com/BoujeeEnjinia1701/drumpanel
Source | docs/05-build-plan.md @ uncommitted

R EV I S I O N H I STO RY

Version | Date | Author | Change
0.3 | 2026-10-03 | Amish Chadha

Throughput check names the TRL 4 timed trial as the test that decides R7 (DMP-DDR-004, Amish's round-2 decision 5A)

0.2 | 2026-10-03 | Amish Chadha | Amish's requirement decisions of 2026-10-03 (DMP-DDR-003): lever notching punch, ring head, raised shear head drive, dial adjusters on the bending screws, tool shelf
0.1 | 2026-10-03 | Amish Chadha | First build plan; design made constructable (DMP-DDR-002)

D R A F T · N O T F O R F A B R I C A T I O N

## DrumPanel prototype build plan

Plan, not yet built. How to build the first proof-of-concept prototype, component by component. Building and testing to it is TRL 4 work. Decisions are kept in the design decisions register (docs/06-design-decisions.md), not here.

### 1. What you are building

Figure 1. Every component pulled apart and numbered in build order.
The prototype is a hand-powered bench set in three stations that turns an empty 208 L oil drum into flat steel without fire: a drain and purge stand where the drum is washed out with water and checked for vapour, a cutting cradle where the heads are cut out and the body is slit and cut into three panels, and a slip roll that bends the curled panels flat. Beside the cradle stand a lever notching punch, which notches the drum on its slit line before it is slit, and a ring head, a second shear head that is bolted to the first so the ring cuts are made two at a time; both live on a shelf on the left rail post. The overview shows the 24 groups of parts in the order you make or fit them. Nearly everything is sawn, drilled and stick-welded from square tube and plate; the three rolls are turned on a lathe; the slitting discs, the end cutter wheel, the punches and dies, bearings, bushes, gears, chains, the gas detector and the hand tools are bought or made by a tool shop. The parts cost about USD 3,489 from the bill of materials, USD 489 over the USD 3,000 value-engineering target.

Safety: An empty oil drum can still hold flammable vapour and explode when cut, ground or heated. No drum comes near the workshop's welding area, and no drum is cut until it has been purged and has passed the vapour check below 5 % LEL. Building the bench set involves stick welding, grinding and lifts of up to 34 kg; using it involves sharp cut edges and in-running nips at the discs and rolls. Work only within the safety stops of section 6. Nothing in this plan authorises cutting a drum; the first cut is TRL 4 work.

### 2. What changed to make it buildable

The concept named eight tools in words; some could not be made or could not work as described. Each change keeps what DrumPanel does and is recorded in decision record DMP-DDR-002, decided on 2026-10-03. The last four rows carry out Amish's requirement decisions of 2026-10-03 and are recorded in DMP-DDR-003.
Table 1. Changes from the concept.

Component | The concept had | The buildable design has | Why
Drain and purge station | A tilting stand | A fixed stand sloping 2.9 degrees to the bung end (Figure 2) | A drum full of water weighs about 240 kg and is never tipped
Drum cradle and clamps | Not defined | Rollers under the rolling hoops and a screw brake (Figure 5) | The drum must turn for the ring cuts and stay still for the slit
End cutter | Cuts each whole end off | Cuts the head out just inside the chime (Figure 21) | No hand wheel cuts the five-layer chime seam
Seam slitter | A lever or crank tool | A rotary shear head on a trolley and overhead rail, web running in the cut (Figure 16) | Straight cut; the discs cannot be geared through the drum wall
Start of the cut | Not shown | Notches through the chime rings and hoops on the slit line | The discs cannot shear a seam or a ridge
Flattening rolls | A three-roll set | A slip roll: geared pinch pair and adjustable bending roll (Figure 31) | A plain three-roll set cannot drive the sheet by friction
Drum body | Rolled flat in one piece | Hoop strips cut out; three panels about 233 x 1,800 mm | Rolling a hoop flat would stretch it 8.5 %
Ring cuts | A separate tool | The same shear head swivelled 90 degrees on its pivot | One tool
Guards | None drawn | Disc guard with skirt, nip guards with 8 mm slots, chain and gear guards, cutter cover (Figure 36) | Fingers kept out of every nip
Panel ends | Not considered | Last 90 mm set by hand on the bench plate | A slip roll cannot bend them
Side frames | Not considered | Bolted to the base; rolls fitted in order | The lower roll cannot go between welded frames
Rail posts | Not drawn | 712.5 mm each side of the middle on two cross members | Room for the end cutter and the parked head
Notches | Cut with a hacksaw Punched with a lever notching punch; the
| | chime notches widened to 60 mm (Figure 23) | Four notches in about 4 minutes instead of
| | | 8
Ring cuts, faster One cut a pass | A ring head bolted to the shear head, so
| | two cuts are made each pass (Figure 26) | Three passes instead of six
Shear head crank | On the upper shaft, 200 mm | On a raised crank shaft in a closed 2.33 to 1 chain drive case, 155 mm (Figure 19) | A crank on the upper shaft sweeps through the drum wall; two ring cuts on one crank stay under 150 N
Bending roll setting | Screws with marked handwheels | Fine-pitch screws with dials of 0.025 mm and lock nuts (Figure 33) | The setting must be within 0.29 mm and must hold

### 3. Making the components

Make and check each component before the assembly step that needs it. Sizes are in millimetres. "Left" and "right" are as seen from the front (the drain stand side); "front" is toward the drain stand, "back" toward the slip roll. Workshop tolerance is 0.5 mm unless a step says otherwise. Weld with 3.2 mm E6013 electrodes; fillets are 4 mm on 3 mm tube and 6 mm on plate. Mark every part with its name in paint marker as you make it. No drum is in the workshop while welding or grinding.

### 3.1 Drain and purge stand

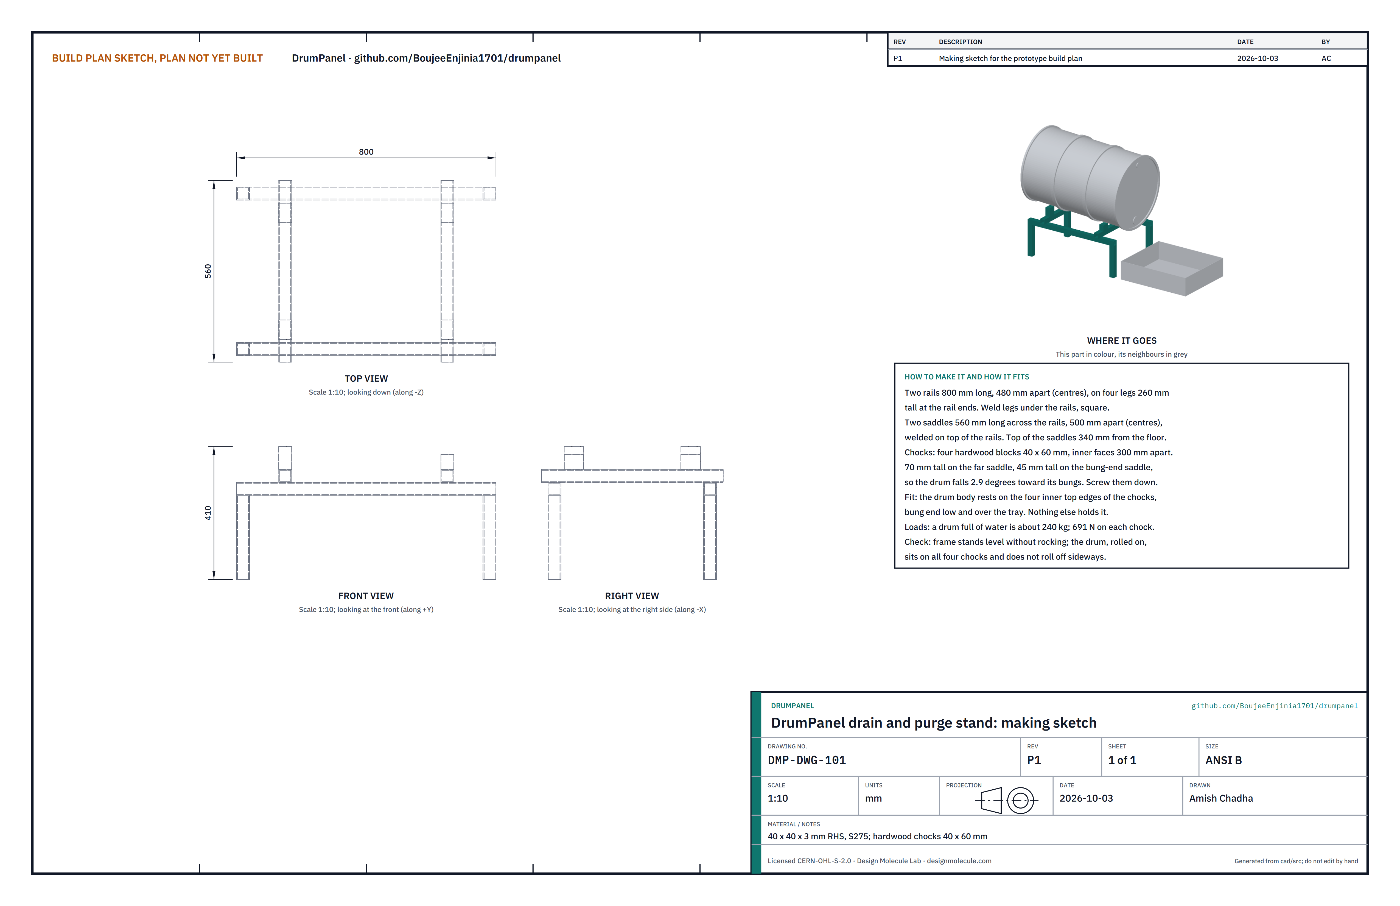
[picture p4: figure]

Figure 2. Drain stand making sketch (DMP-DWG-101).
What it is and what it is made from. A low frame that holds a drum on its side, bung end low, over the tray, full of water if need be. 40 x 40 x 3 mm square tube, S275; four hardwood chocks 40 x 60 mm.
How to make it.
Cut two rails 800 mm, four legs 260 mm and two saddles 560 mm from the tube.
Weld a leg square under each end of each rail. Lay the rails 480 mm apart between centres.
Weld the saddles across the top of the rails, 500 mm apart between centres, centred on the frame.
Cut the chocks: two 70 mm tall and two 45 mm tall. Screw the tall pair to the far saddle and the short pair to the bung-end saddle, with their inner faces 300 mm apart.

How it fits the parts next to it.

1.
2.
3.
4.

Figure 3. Joint 1. The drum body rests on the inner top edges of the four chocks; nothing else holds it.
The tray stands on the floor under the bung end, its near edge 60 mm beyond the stand legs.
Check before moving on. The stand does not rock on the floor; a drum rolled on sits on all four chocks and falls toward the bung end.

### 3.2 Cradle frame

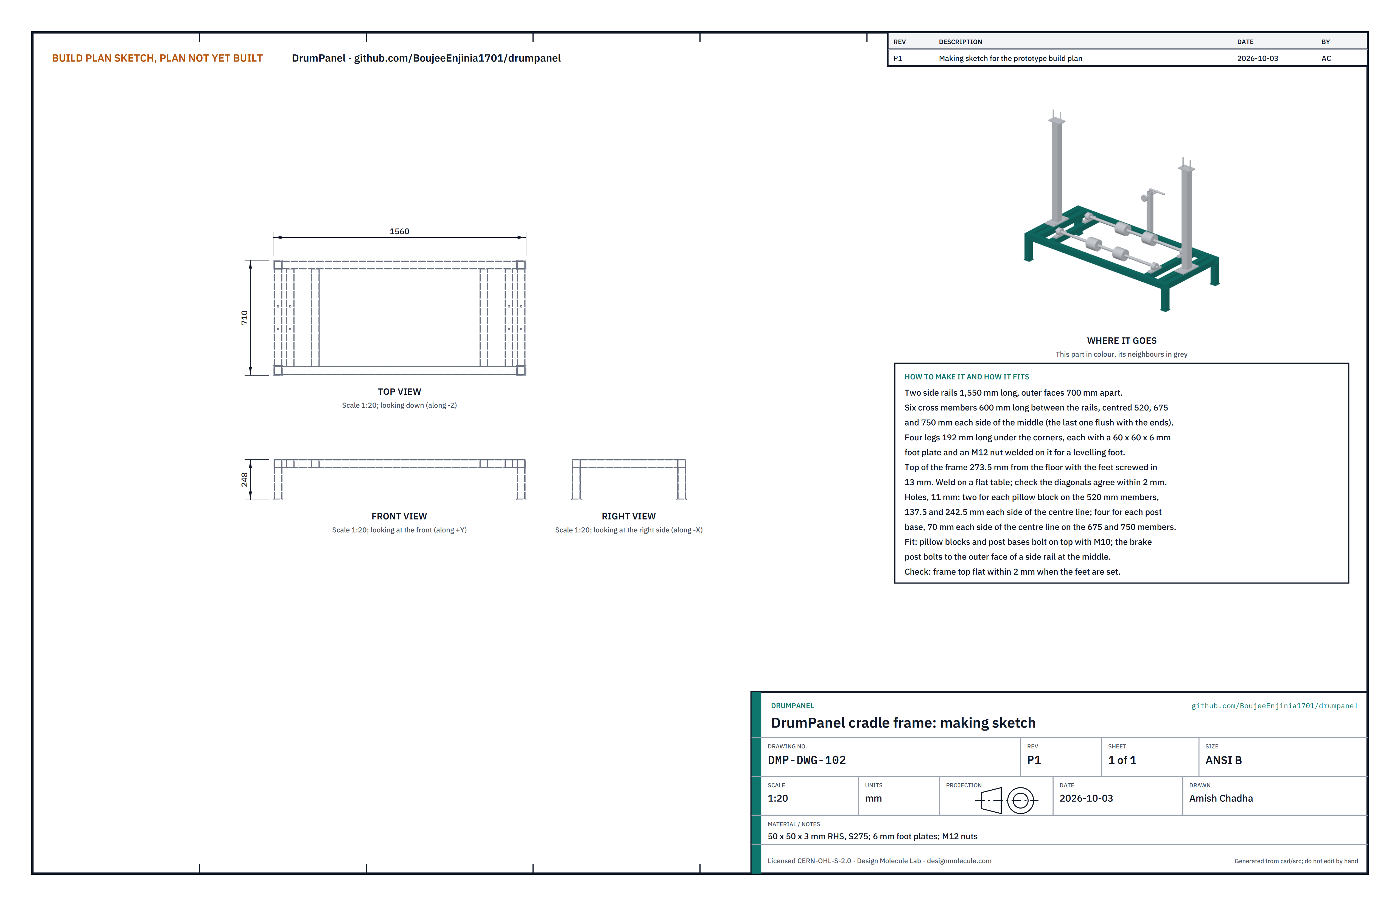
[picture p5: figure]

Figure 4. Cradle frame making sketch (DMP-DWG-102).
What it is and what it is made from. The low frame that carries the rollers, the brake and the two rail posts. 50 x 50 x 3 mm square tube, S275; 6 mm foot plates; four M12 nuts and levelling feet.
How to make it.
Cut two side rails 1,550 mm, six cross members 600 mm and four legs 192 mm.
Lay the side rails on a flat table, outer faces 700 mm apart. Weld the cross members between them, centred 520, 675 and 750 mm each side of the middle (the outer pair flush with the ends). Check the diagonals agree within 2 mm.
Weld a 60 x 60 x 6 mm foot plate with an M12 nut on its underside to one end of each leg; weld the legs under the four corners.
Drill 11 mm holes: two for each pillow block on the 520 mm cross members, 137.5 and 242.5 mm each side of the centre line; four for each post base, 70 mm each side of the centre line, on the 675 and 750 mm members.

How it fits the parts next to it. The pillow blocks and post bases bolt on top with M10 bolts; the brake post bolts to the outer face of the right-hand side rail at the middle.
Check before moving on. With the feet screwed in 13 mm, the frame top is 273.5 mm from the floor and flat within 2 mm.

1.
2.

3.

4.

### 3.3 Roller shafts with rollers (make 2)

Figure 5. Roller shaft making sketch (DMP-DWG-103).
What it is and what it is made from. Two shafts, each with two rollers that carry the drum on its rolling hoops. 25 mm bright steel bar; 101.6 x 4 mm tube; 10 mm plate discs; four bought UCP205 pillow blocks.
How to make it.
Cut each shaft 1,120 mm and chamfer the ends.
Cut four tube pieces 100 mm long. Cut eight 10 mm discs 93 mm across, bore them 25 mm, and weld one into each end of each tube piece.
Slide two rollers onto each shaft, centred 147 mm each side of its middle. Weld the discs to the shaft all round. Turn the roller faces true in a lathe if they run out more than 0.5 mm.

How it fits the parts next to it.

1.
2.

3.
4.

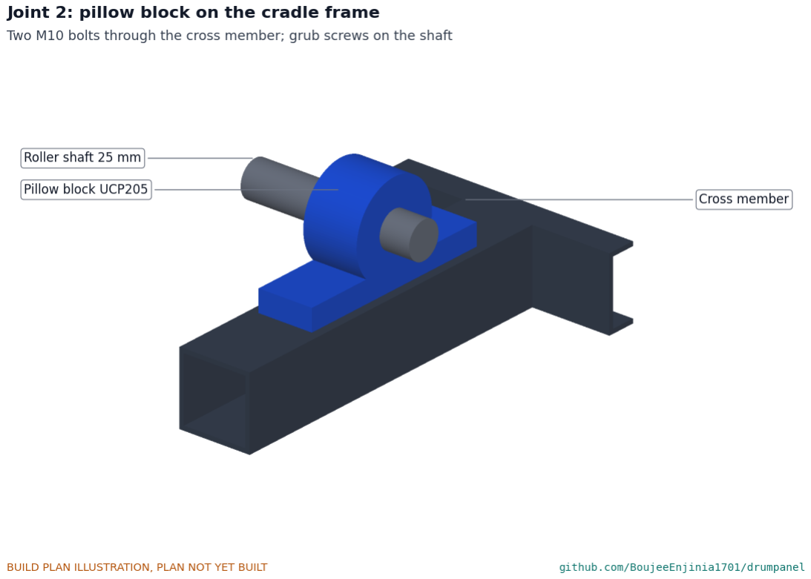
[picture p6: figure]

Figure 6. Joint 2. Each pillow block sits on a 520 mm cross member with two M10 bolts; its grub screws lock the shaft.

Figure 7. Joint 8. The drum's hoop sits on the rollers at 33 degrees from vertical on each side; the shafts are 380 mm apart.
Check before moving on. Each shaft turns freely by hand in its blocks; the rollers run true within 0.5 mm.

### 3.4 Drum brake

Figure 8. Drum brake making sketch (DMP-DWG-104).
What it is and what it is made from. A screw and pad that hold the drum still while it is slit. 40 x 40 x 3 mm tube; an M16 x 200 screw and nut; 16 mm bar; a 60 mm rubber pad.
How to make it.
Cut the post 460 mm. Drill two 11 mm holes 25 mm apart, 56 and 81 mm from its foot.
Drill an 18 mm hole through both walls 423 mm from the foot. Weld an M16 nut over it on the outer face.
Weld a 16 mm bar 160 mm long across the screw head as a T-handle. Fit the rubber pad on a swivel plate at the screw tip.

How it fits the parts next to it. The post bolts to the outer face of the right side rail at the middle of the frame with two M10 bolts. Screwed in, the pad presses on the drum side between the hoops, at the height of the drum axis. Check before moving on. With the screw tight, a drum on the rollers cannot be turned by hand.

1.
2.
3.

### 3.5 Rail posts (make 2)

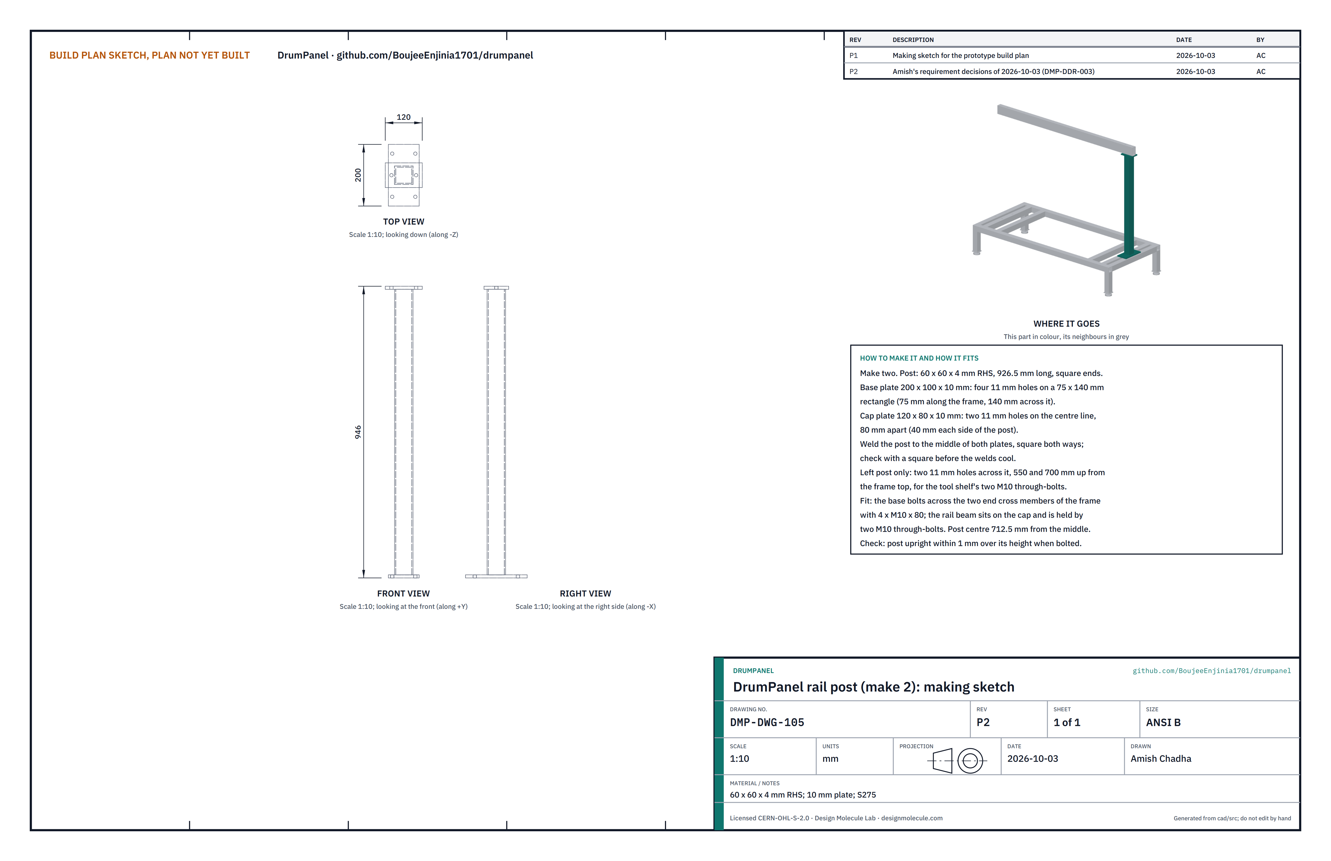
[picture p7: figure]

Figure 9. Rail post making sketch (DMP-DWG-105).
What it is and what it is made from. The two posts that hold the rail beam over the cradle. 60 x 60 x 4 mm tube; 10 mm plate.
How to make it.
Cut each post 926.5 mm with square ends.
Cut a base plate 200 x 100 mm with four 11 mm holes on a 75 x 140 mm rectangle, and a cap plate 120 x 80 mm with two 11 mm holes 80 mm apart on its centre line.
Weld the post to the middle of both plates, square both ways.
Left post only: drill two 11 mm holes straight across it, 550 and 700 mm up from the frame top, for the tool shelf's bolts.

How it fits the parts next to it.

1.
2.

3.
4.

Figure 10. Joint 3. The base plate spans the two end cross members and is held by four M10 x 80 bolts. Check before moving on. Bolted down, each post is upright within 1 mm over its height.

### 3.6 Rail beam

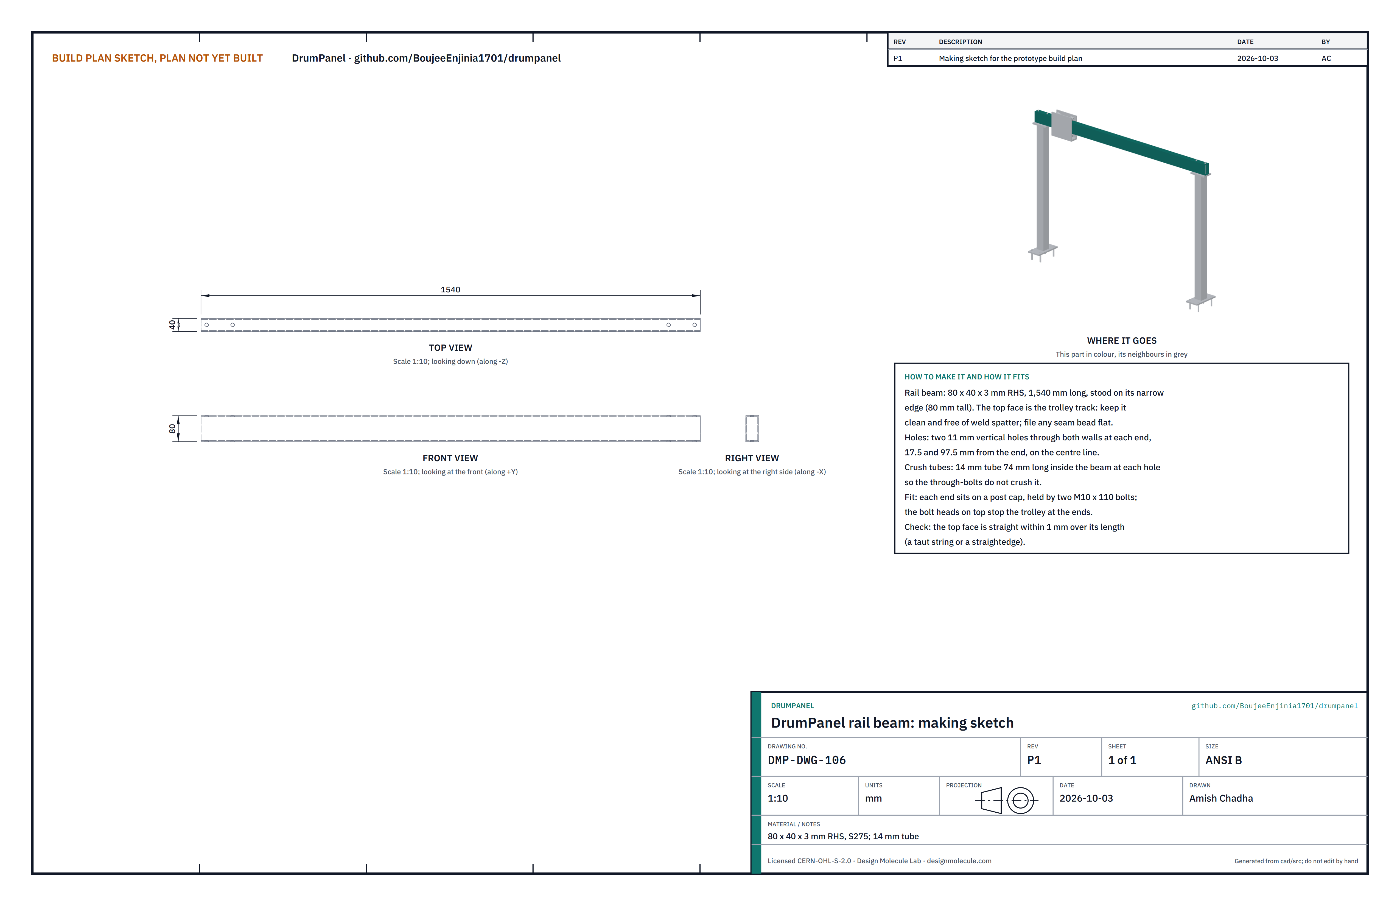
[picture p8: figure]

Figure 11. Rail beam making sketch (DMP-DWG-106).
What it is and what it is made from. The track the shear head runs along. 80 x 40 x 3 mm tube, 1,540 mm long, stood on its narrow edge; four short lengths of 14 mm tube.
How to make it.
Cut the beam 1,540 mm. File the top face clean of spatter and seam bead: it is the trolley track.
Drill two 11 mm vertical holes through both walls at each end, 17.5 and 97.5 mm from the end. Push a 74 mm crush tube into the beam at each hole.

How it fits the parts next to it.

1.
2.
3.

Figure 12. Joint 4. Each end sits on a post cap and is held by two M10 x 110 through-bolts; the bolt heads stop the trolley.
Check before moving on. The top face is straight within 1 mm over its length.

### 3.7 Trolley

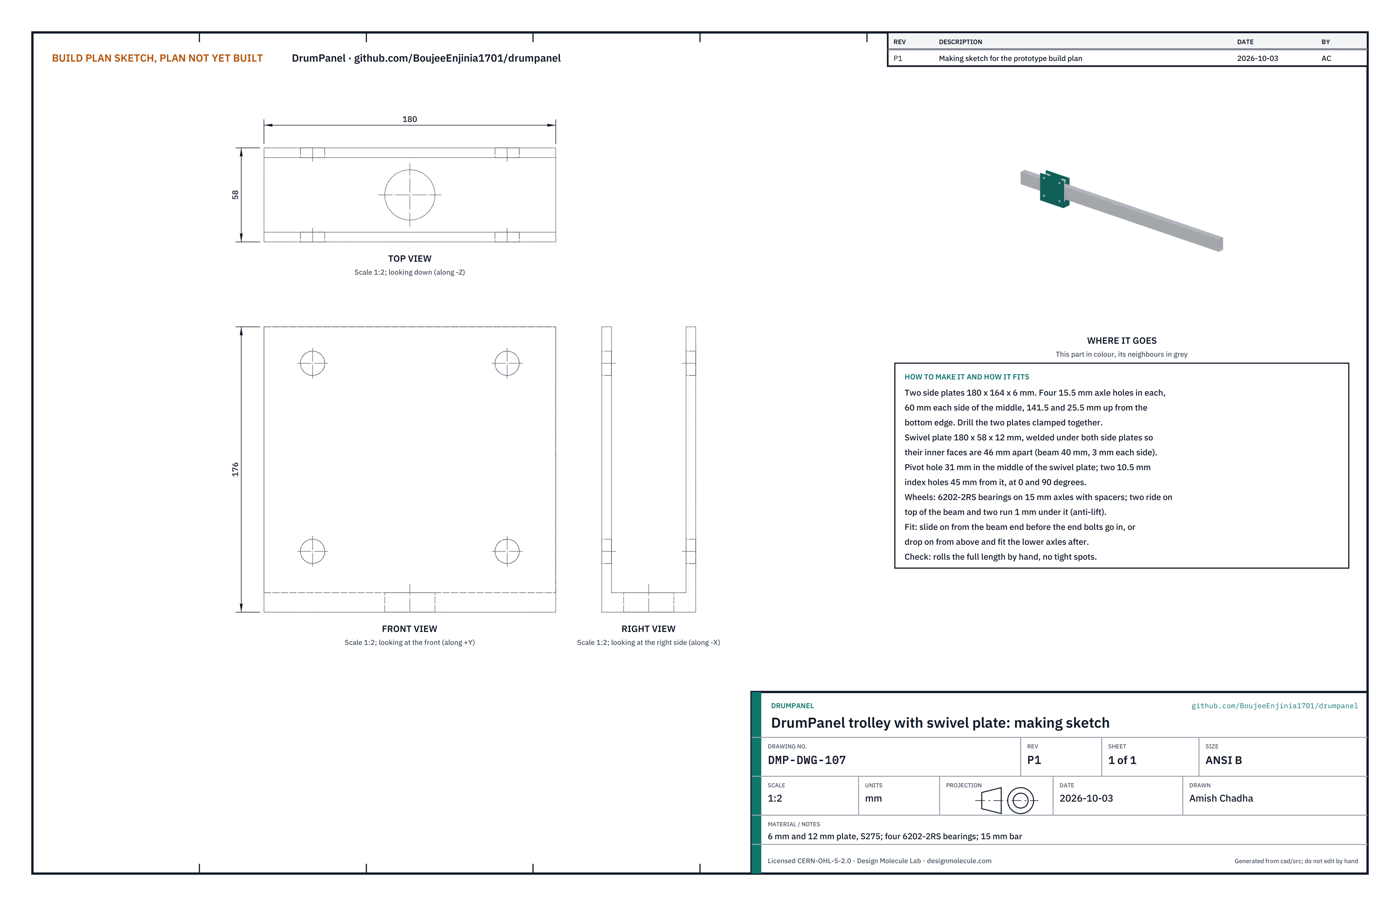
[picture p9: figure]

Figure 13. Trolley making sketch (DMP-DWG-107).
What it is and what it is made from. A carriage that rolls along the beam and carries the shear head on a pivot. 6 mm and 12 mm plate; four bought 6202-2RS bearings; 15 mm bar.
How to make it.
Cut two side plates 180 x 164 mm. Clamp them together and drill four 15.5 mm axle holes, 60 mm each side of the middle, 141.5 and 25.5 mm up from the bottom edge.
Cut a swivel plate 180 x 58 x 12 mm. Drill a 31 mm pivot hole in its middle and two 10.5 mm index holes 45 mm from it, at 0 and 90 degrees.
Weld the side plates on top of the swivel plate, inner faces 46 mm apart.
Cut four 15 mm axles 58 mm long, threaded M15 or held by circlips; spacers centre each bearing.

How it fits the parts next to it.

1.

2.

3.
4.

Figure 14. Joint 5. Two wheels ride on top of the beam and two run 1 mm under it, so the trolley cannot lift off; the head plate hangs from the pivot pin.
Check before moving on. The trolley rolls the full length of the beam by hand without tight spots.

### 3.8 Drop bar, head plate and pivot pin

Figure 15. Drop bar, head plate and pivot pin making sketch (DMP-DWG-108).
What it is and what it is made from. The link between the trolley and the shear head. 50 x 50 x 4 mm tube; 12 mm plate; 30 and 10 mm bar.
How to make it.
Cut the head plate 120 x 120 mm; drill a 31 mm hole in its middle and a 10.5 mm hole 45 mm from it.
Cut the drop bar 126 mm and weld it square under the middle of the head plate.
Cut the pivot pin 30 mm bar, 55 mm long; weld a 40 mm collar at its top; drill a 6 mm hole for an R-clip.
Make a 10 mm index pin on a lanyard.
Weld the lower end of the drop bar to the middle of the shear head's top plate, over the nip line, once the head frame is made (section 3.9).

How it fits the parts next to it. The pin drops down through the swivel plate and the head plate and takes an R-clip below; the index pin locks the head in its slit or ring position.
Check before moving on. With the index pin out the head turns freely through 90 degrees; the index pin drops in at both positions.

1.
2.
3.
4.
5.

### 3.9 Shear head frame

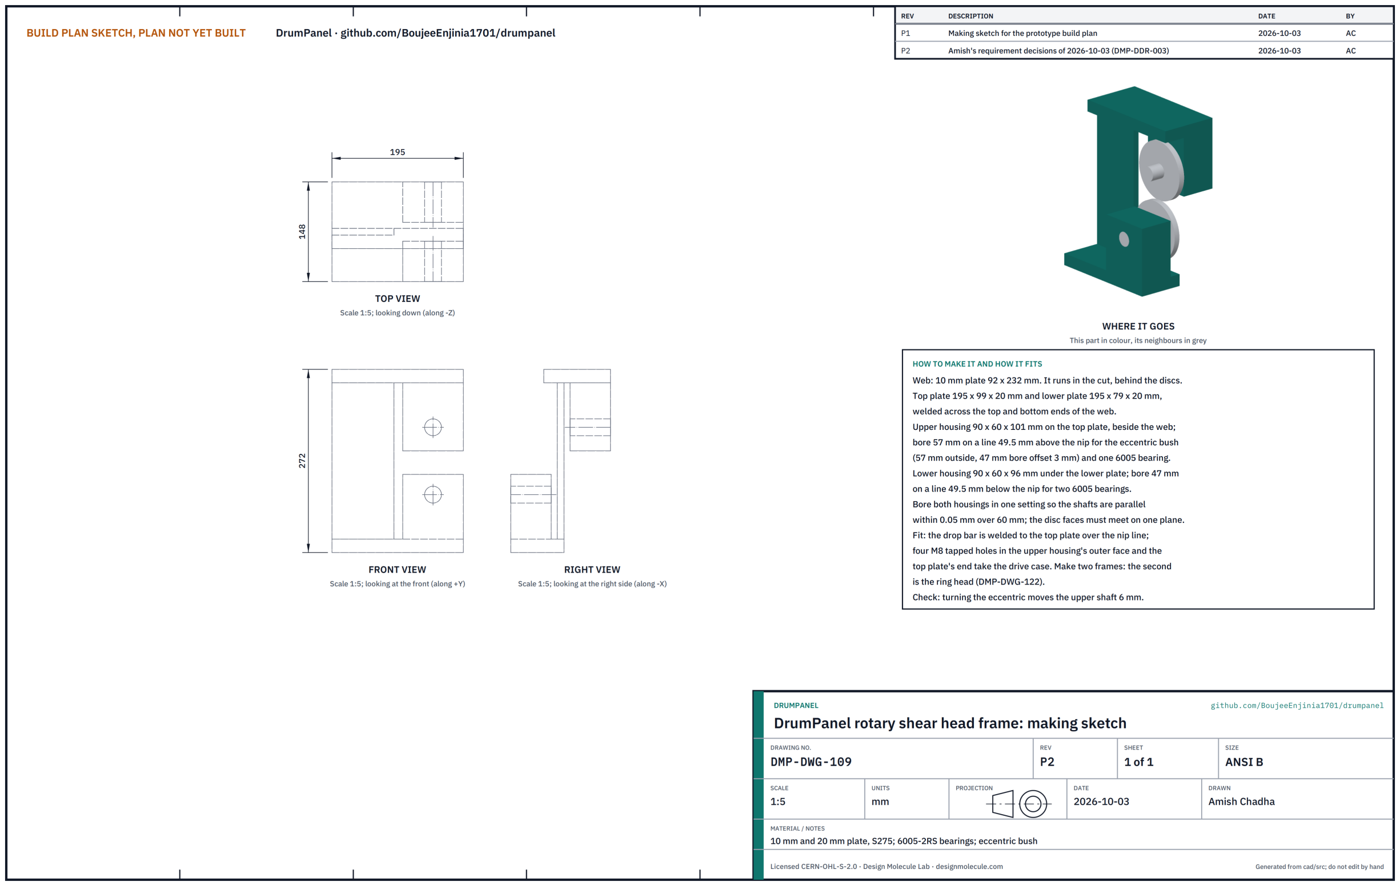
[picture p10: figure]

Figure 16. Shear head frame making sketch (DMP-DWG-109).
What it is and what it is made from. The frame that holds the two slitting discs. Its thin web runs in the cut behind the discs, so the head can travel the full length of the drum. 10 mm and 20 mm plate, S275; bought 6005-2RS bearings; an eccentric bush. Make two frames: the second is the ring head (section 3.14).
How to make it.
Cut the web 92 x 232 mm from 10 mm plate, the top plate 195 x 99 mm and the lower plate 195 x 79 mm from 20 mm plate.
Cut two bearing housings 90 x 60 mm, 101 mm tall (upper) and 96 mm tall (lower).
Weld the top and lower plates across the ends of the web, the upper housing under the top plate beside the web, and the lower housing on the lower plate, as the sketch shows.
Bore both housings in one setting so the shafts are parallel within 0.05 mm over 60 mm: the upper 57 mm on a line 49.5 mm above the nip line, for the eccentric bush; the lower 47 mm on a line 49.5 mm below it, for two bearings.
Make the eccentric bush: 57 mm outside, 47 mm bore offset 3 mm, with a lever and a locking set screw.
On the main head only, tap four M8 holes for the drive case: two in the outer face of the upper housing and two in the end of the top plate.

How it fits the parts next to it.

1.

2.
3.

4.

5.
6.

Figure 17. Joint 6. The upper disc is driven through the drive case, the lower disc runs inside the drum, and the 10 mm web follows in the cut; the cut edges spread round it. The crank turns high on the drive case, clear of the drum. Disc guard left off for clarity.
Check before moving on. Turning the eccentric moves the upper shaft through 6 mm.

### 3.10 Head shafts, discs and drive case

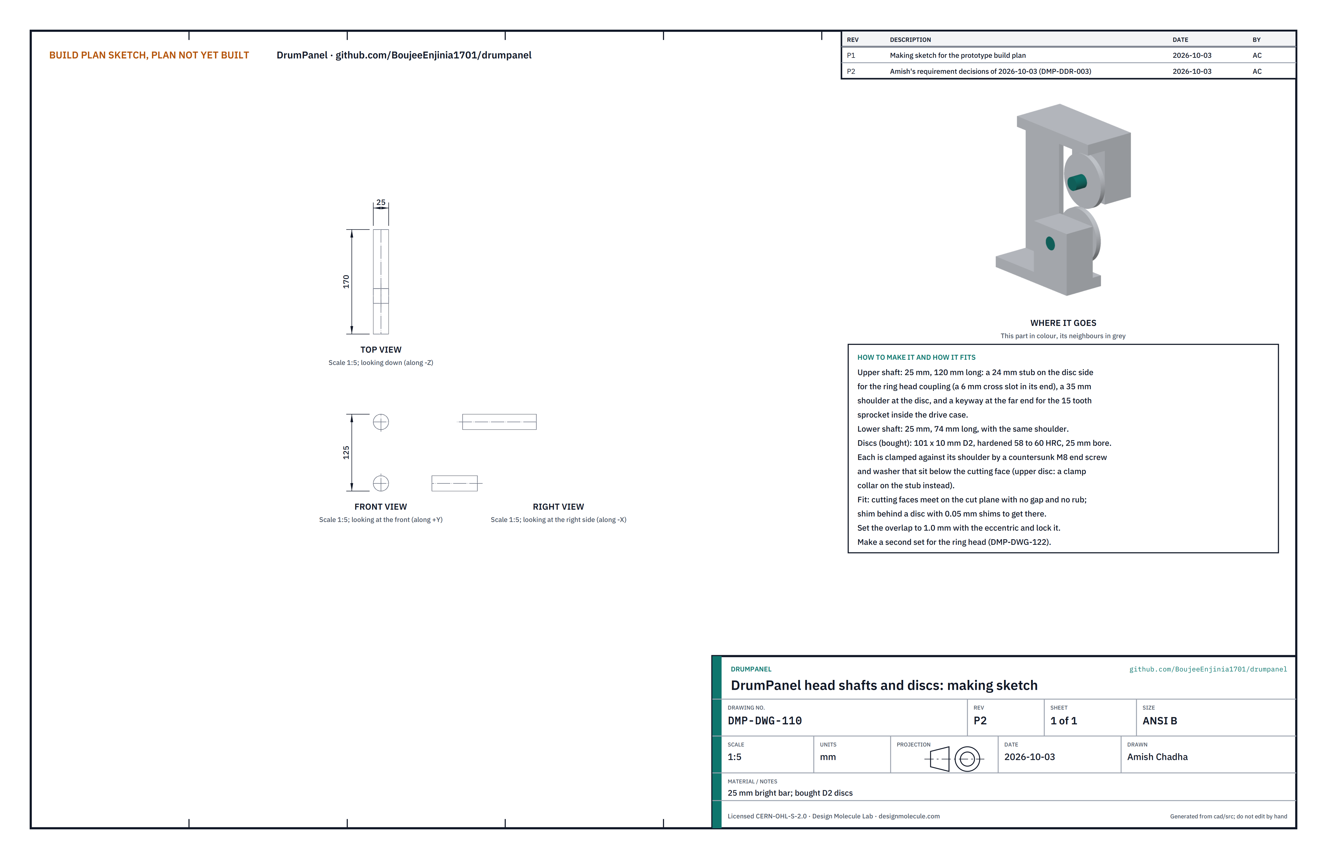
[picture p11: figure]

Figure 18. Head shafts making sketch (DMP-DWG-110).

Figure 19. Drive case and crank making sketch (DMP-DWG-120).
What it is and what it is made from. The two shafts that carry the discs, and the drive case that turns the upper one from a crank set high on the side of the head, where it cannot hit the drum. 25 mm and 20 mm bright bar; 8 mm plate and 1.5 mm sheet; 20 x 12 mm flat; four bought 6004-2RS bearings; bought #35 sprockets of 12, 28 and two of 15 teeth and about 1 m of #35 chain; two bought D2 slitting discs 101 x 10 mm. Make a second set of shafts and discs, without the drive, for the ring head.
How to make it.
Turn the upper shaft 120 mm long: a 24 mm stub on the disc side with a 6 mm slot across its end for the ring head coupling, a 35 mm shoulder at the disc, and a keyway at the far end for a 15 tooth sprocket. Turn the lower shaft 74 mm long with the same shoulder.
Cut two plates 140 x 182 mm from 8 mm plate and drill them clamped together: a 26 mm clearance hole on the disc line for the upper shaft, and two 42 mm bearing bores, one 80 mm above the disc line for the jackshaft and one 60 mm back and 120 mm above the disc line for the crank shaft.
Turn the jackshaft and the crank shaft from 20 mm bar, 38 mm and 44 mm long, with keyways for their sprockets.
Fold a 1.5 mm sheet band to join the two plates all round, 22 mm apart; it is the chain guard. Screw it to both plates.
Make the crank: a 20 x 12 mm arm with 155 mm between centres and a 24 mm grip 100 mm long that spins freely on a 16 mm pin.
Clamp each disc against its shoulder: the lower disc with a countersunk M8 end screw, the upper disc with a clamp collar on the stub, both below the cutting face.

1.

2.

3.

4.

5.

6.

How it fits the parts next to it. The two cutting faces meet on one plane with no gap and no rub; shim behind a disc with 0.05 mm shims to get there. Set the overlap to 1.0 mm with the eccentric and lock it. The inner plate of the drive case bolts to the upper housing and the top plate with four M8 screws. The 12 tooth sprocket on the crank shaft drives the 28 tooth on the jackshaft; a 15 tooth beside it drives the 15 tooth on the upper shaft. Fit the chains with about 3 mm of slack before closing the band.
Check before moving on. About 2.3 turns of the crank turn the discs once; nothing rubs; a strip of 1 mm sheet cuts cleanly by hand.
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

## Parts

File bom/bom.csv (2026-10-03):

item | qty | spec | supplier | unit_cost_usd | make_buy | notes
1 Drain and purge stand | 1 | Welded frame of 40 x 40 x 3 mm RHS: two rails 800 mm, four legs 260 mm, two saddles 560 mm; four hardwood chocks 40 x 60 mm on the saddles, 70 mm high at the far end and 45 mm at the bung end (2.9 degree slope); S275; about 13 kg | Local steel stockist; timber yard (chocks) | 42.00 | make | Holds a water-filled drum (about 227 kg); DMP-CAL-001 section 3
2 Drain tray 60 L | 1 | HDPE oil drain tray about 600 x 500 x 150 mm, placed under the bung end of the drain stand | Hardware or motor parts store | 35.00 | buy | Catches residue and purge water
3 Purge kit | 1 | 15 m of 19 mm garden hose with tap connector; 3/4 in bung hose adaptor; 2 in bung drain spout; non-sparking (brass or bronze) bung wrench; one tap fitted to a spare drum used as a settling drum so purge water is reused; biodegradable detergent | Hardware store; drum supplier | 95.00 | buy | Water fill purge decided 2026-10-03 (DMP-DDR-001 D1)
4 Vapour check kit | 1 | Portable combustible gas detector with a catalytic bead or infrared LEL sensor, internal sampling pump and 1 m probe hose, alarm settable at 5 % LEL (a 4-gas meter reading LEL, O2, CO and H2S is acceptable); bump-test gas (50 % LEL methane) with a demand regulator | Safety equipment supplier | 600.00 | buy | Pass below 5 % LEL; bump test each day of use (DMP-DDR-001 D2)
5 Cradle frame with levelling feet | 1 | 50 x 50 x 3 mm RHS: two side rails 1,500 mm, six cross members 600 mm, four legs 192.5 mm with 60 x 60 x 6 mm foot plates; four M12 levelling feet with 60 mm pads; S275; about 34 kg | Local steel stockist | 95.00 | make | Bolt holes for the post bases in the four end cross members
6 Cradle rollers shafts and pillow blocks | 1 | Two 25 mm bright steel shafts 1,120 mm; four rollers from 101.6 x 4 mm tube 100 mm long with 10 mm end discs bored 25 mm, welded to the shafts under the rolling hoops; four UCP205 pillow blocks with 8 x M10 bolts | Local steel stockist; bearing supplier | 105.00 | make | Rollers 380 mm apart carry the drum on its hoops at 33 degrees from vertical
7 Drum brake | 1 | 40 x 40 x 3 mm RHS post 460 mm bolted to the outer face of the +Y side rail with 2 x M10; M16 x 200 screw with a welded T-handle running in a welded nut; 60 mm rubber pad on a swivel plate | Local steel stockist; hardware store | 22.00 | make | Holds the drum still for the seam slit
8 Rail posts rail beam and bolts | 1 | Two 60 x 60 x 4 mm RHS posts 927 mm with 200 x 100 x 10 mm base plates and 120 x 80 x 10 mm caps; 80 x 40 x 3 mm RHS rail beam 1,540 mm; 8 x M10 x 80 base bolts and 4 x M10 x 110 through-bolts with 14 mm crush tubes; about 24 kg | Local steel stockist; fastener supplier | 62.00 | make | Portal frame over the cradle for the shear head trolley
9 Trolley swivel and drop bar | 1 | Two 6 mm side plates 180 x 164 mm on a 12 mm swivel plate; four 6202-2RS bearings as wheels on 15 mm axles (two on the beam top, two under it); 30 mm pivot pin with a 10 mm index pin and two index holes at 90 degrees; 50 x 50 x 4 mm RHS drop bar 126 mm welded between a 120 x 120 x 12 mm head plate and the shear head; drum height set by the cradle levelling feet | Local steel stockist; bearing supplier | 48.00 | make | Swivel sets slit mode or ring mode
10 Rotary shear head | 1 | Frame from 20 mm plate (top and lower plates, two 90 x 60 mm bearing housings) and a 10 mm web in the cut plane; two D2 slitting discs 101 x 10 mm hardened 58 to 60 HRC with 25 mm bores; two 25 mm shafts, the upper one with a stub for the ring head coupling; three 6005-2RS bearings; eccentric bush (3 mm offset) on the upper shaft to set the 1.0 mm overlap and open the nip 6 mm; 1.5 mm sheet disc guard; drive case of two 8 mm plates and a 1.5 mm sheet band (the chain guard) carrying a 20 mm crank shaft and a 20 mm jackshaft in four 6004-2RS bearings, #35 sprockets 12 and 28 teeth (crank to jackshaft) and two of 15 teeth (jackshaft to upper shaft), about 1 m of #35 chain, 155 mm crank with a free-spinning grip | Local steel stockist; machine shop; cutting tool supplier (discs) | 340.00 | make | Driven upper disc; lower disc idles; 2.33 to 1 drive raised clear of the drum (DMP-DDR-003, Q3); DMP-CAL-001 section 5. Price basis: USD 265 for the head as first costed plus about USD 75 for the drive (four #35 sprockets USD 45, 1 m of #35 chain USD 10, four bearings USD 12, plate and sheet USD 8)
11 End cutter | 1 | 12 mm body plate 160 x 120 mm; 40 mm knurled drive wheel on a 16 mm shaft with a 150 mm crank; 30 mm guide roller on a 12 mm axle; 50 x 6 mm hardened cutter wheel (sold as a drum deheader or rotary cutter spare) on a 12 mm arm with an M12 clamp screw; 30 x 8 mm flat bar torque arm resting against the rail post | Local steel stockist; machine shop; cutting tool supplier (wheel) | 115.00 | make | Cuts the head just inside the chime; follows expired US3161952A
12 Roll stand base | 1 | 60 x 60 x 3 mm RHS: two cross rails 800 mm and two long rails 1,000 mm; S275; about 20 kg | Local steel stockist | 45.00 | make | Cross rails spread the stand against tipping
13 Side frames | 2 | 20 mm plate 370 x 250 mm with a 40 mm bush bore and two 60 mm slots (pinch and bending), on two 50 x 50 x 3 mm RHS legs 700 mm; 25 mm top bridge bar with M16 and M20 threaded holes; about 23 kg each | Local steel stockist | 75.00 | make | Plasma or saw cut; slots filed to fit the slide blocks
14 Rolls | 3 | 60 mm bright bar C45 (EN8), 900 mm face, 30 mm journals turned each end; lower pinch roll 1,092 mm long, upper pinch roll 1,032 mm, bending roll 984 mm; about 22 kg each | Local steel stockist; machine shop (turning) | 95.00 | make | Needs a lathe with 1.1 m between centres
15 Bushes slide blocks and screws | 1 | Six flanged bronze bushes 30 x 40 x 20 mm (flange 52 x 6); four 20 x 60 x 60 mm steel slide blocks bored 40 mm; two M16 pinch screws with 90 mm handwheels; two fine-pitch M20 x 1.5 bending screws with 110 mm handwheels, each with an M20 x 1.5 lock nut on the bridge, an 80 mm dial of 60 divisions (0.025 mm each) clamped to the screw by a set screw, and a pointer on the bridge; captive collars on all four screws | Bearing supplier; machine shop | 160.00 | make | Grease points on each bush; bending roll set to 0.025 mm and locked (DMP-DDR-003, Q4). Price basis: USD 120 as first costed plus USD 40 (two M20 x 1.5 screws and an M20 x 1.5 tap USD 15, two engraved dials USD 20, two lock nuts and pointers USD 5)
16 Pinch gears | 1 | Two spur gears module 3, 20 teeth, 20 mm face, bored 30 mm with keyway; one on each pinch roll at the gear end | Gear or power transmission supplier | 60.00 | buy | Keep the pinch rolls turning together; 61 mm centres with 1 mm sheet
17 Crank and chain drive | 1 | 10 mm crank bracket 190 x 120 mm bolted to the side frame; housing tube 50 x 6 mm with two bronze bushes; 25 mm crank shaft; 300 mm crank with a free-spinning grip; #40 (12.7 mm pitch) sprockets 13 and 39 teeth; about 1.3 m of #40 roller chain | Power transmission supplier; local steel stockist | 95.00 | make | 3:1 reduction; DMP-CAL-001 section 6
18 Roll guards | 1 | 1.5 mm steel sheet: in-feed nip guard with an 8 mm slot above the in-feed table, out-feed guard with a 10 mm slot, lid between them; chain guard box and gear guard box; all bolted on (a tool is needed to remove them) | Local steel stockist | 55.00 | make | ISO 13857 slot distances checked in DMP-CAL-001 section 8
19 In-feed and out-feed tables | 2 | 18 mm exterior plywood 900 x 815 mm (in-feed) and 900 x 810 mm (out-feed) on 40 x 40 x 3 mm angle frames with four 40 x 40 x 3 mm RHS legs; tops at the sheet line (900 and 913 mm) | Timber yard; local steel stockist | 60.00 | make | Support the 1.8 m panels in and out
20 Finishing tools and bench plate | 1 | 10 mm steel plate 600 x 400 mm; 1.5 kg dead-blow mallet; swivel-blade deburring tool with spare blades; 250 mm flat and half-round files | Hardware store; steel stockist (plate offcut) | 85.00 | buy | Ends of each panel are set flat by hand on the plate
21 Lever notching punch | 1 | C-frame of S355 plate: lower jaw 56 x 50 mm and upper jaw 40 x 60 mm, 385 mm long, gap 40 mm, die faces ground to the drum's inside radius; station 1: open-ended chime notch 60 x 35 mm; station 2: hoop slot 40 x 32 mm, 338 mm out; two D2 punches (faces raked 10 degrees) with matching dies, 0.1 to 0.2 mm clearance; two Tr24 x 5 screws in bronze nut blocks with needle thrust bearings on the punches; 500 mm ratchet lever with a hex socket; about 19 kg | Local steel stockist; tool and die shop (punches and dies); power transmission supplier (screws, nuts, bearings); hardware store (ratchet) | 330.00 | make | Replaces the hacksaw notches (DMP-DDR-003, Q1); lever force 131 N at most (DMP-CAL-001 section 9). Price basis: about 15 kg of S355 plate USD 35; two D2 punch and die sets ground by a tool shop USD 140; two Tr24 x 5 screws with bronze nuts USD 50; two needle thrust bearings USD 15; 500 mm ratchet lever and socket USD 35; machining allowance USD 55
22 Procedure sheets | 1 | Printed and laminated pictogram sheets: drum acceptance, drain and purge, vapour check, cutting, rolling, finishing | Local print shop | 20.00 | buy | Drafted from DMP-BLD-001 and DMP-PRC-001
23 Fasteners paint and welding consumables | 1 | M10, M12, M16 bolts, nuts and washers not listed above; 3.2 mm E6013 electrodes; primer and enamel; thread locker; grease | Hardware store | 120.00 | buy | Allowance
24 Personal protective equipment | 1 | Cut-resistant gloves EN 388 level C or higher (4 pairs); safety glasses (4); ear defenders (2); leather aprons (2); nitrile gloves (box of 100) | Safety equipment supplier | 110.00 | buy | Cut-resistant gloves are worn for every task that handles cut edges
25 Ring head with spacer and coupling | 1 | A second shear head made to the same drawings as line 10 without its drive: 20 mm plate frame and 10 mm web, two D2 slitting discs 101 x 10 mm, two 25 mm shafts, three 6005-2RS bearings, eccentric bush, 1.5 mm disc guard; a 10 mm spacer plate 115 x 270 mm with slotted holes for 233 and 234 mm head spacing, bolted to both top plates with four M12 bolts; a 25 mm coupling shaft 135 mm long with dog ends joining the two upper shafts, in a loose plastic guard sleeve; about 20 kg | Local steel stockist; machine shop; cutting tool supplier (discs) | 255.00 | make | Bolted on for the ring cuts so two are made in each pass (DMP-DDR-003, Q2). Price basis: the line 10 head as first costed less its crank, about USD 230 (two D2 discs USD 110, plate and machining USD 90, bearings USD 15, guard USD 15), plus USD 25 for the spacer plate and coupling shaft
26 Tool shelf | 1 | 6 mm plate shelf 380 x 600 mm on two 6 mm brackets, welded to a 10 mm back plate 200 x 310 mm bolted to the outer face of the left rail post with two M10 through-bolts; holds the notching punch, its lever and the ring head; S275; about 14 kg | Local steel stockist | 40.00 | make | Price basis: about 14 kg of S275 plate at about USD 2 a kg (USD 28) plus cutting and bolts USD 12

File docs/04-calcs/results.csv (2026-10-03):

tag | quantity | value | unit
A1 | Panel length (body circumference at mid-wall) | 1800 | mm
A2 | Panel widths (outer, middle, outer) | 233 / 234 / 233 | mm
A3 | Head discs, two, diameter | 552 | mm
A4 | Flat area per drum: three panels | 1.26 | m2
A5 | Flat area per drum: two head discs | 0.48 | m2
A6 | Empty drum mass (estimate) | 19.2 | kg
A7 | Mass of the three panels at 1.0 mm | 9.9 | kg
B1 | Drum volume (inside) | 221 | L
B2 | Mass of a drum full of water | 240 | kg
B3 | Fill time at 20 L/min | 11.0 | min
B4 | Drain time through the 2 in bung at the bottom of the low head, full to nearly empty | 2.3 | min
B5 | Water left below the bung opening, stand sloping 2.9 deg | 1.4 | L
B6 | Contact angle of the drum on the chocks, from vertical | 31.5 | deg
B7 | Normal force on each chock, full drum | 691 | N
B8 | Bending stress in a saddle (40 x 40 x 3 RHS), full drum | 10.4 | MPa
B9 | Compressive stress in a drain stand leg, full drum | 1.3 | MPa
C10 | End cutter, head 1.0 mm: cut force 429 N, feed 70 N, drive torque 1.8 N m, crank force | 12 | N
C12 | End cutter, head 1.2 mm: cut force 571 N, feed 100 N, drive torque 2.6 N m, crank force | 17 | N
C15 | End cutter, head 1.5 mm: cut force 807 N, feed 156 N, drive torque 4.1 N m, crank force | 27 | N
C20 | Pinch needed between drive wheel and guide roller for 1.5 mm heads (knurl, friction 0.3) | 520 | N
C21 | Crank turns to go once round a head | 13.8
C22 | Cutting time per head at 30 crank turns a minute | 0.46 | min
D8 | Shear head, wall 0.8 mm: separating force 482 N, nip angle 10.8 deg, feed resistance 85 N, disc torque 5.2 N m, crank force (one cut: the slit) | 16 | N
D8r | Shear head with the ring head coupled on, wall 0.8 mm: crank force (two ring cuts at once) | 32 | N
D8t | Shear head, wall 0.8 mm: traction of the driven disc over resistance | 1.69
D10 | Shear head, wall 1.0 mm: separating force 713 N, nip angle 11.4 deg, feed resistance 139 N, disc torque 8.4 N m, crank force (one cut: the slit) | 26 | N
D10r | Shear head with the ring head coupled on, wall 1.0 mm: crank force (two ring cuts at once) | 52 | N
D10t | Shear head, wall 1.0 mm: traction of the driven disc over resistance | 1.54
D12 | Shear head, wall 1.2 mm: separating force 977 N, nip angle 12.0 deg, feed resistance 213 N, disc torque 12.9 N m, crank force (one cut: the slit) | 39 | N
D12r | Shear head with the ring head coupled on, wall 1.2 mm: crank force (two ring cuts at once) | 79 | N
D12t | Shear head, wall 1.2 mm: traction of the driven disc over resistance | 1.38
D15 | Shear head, wall 1.5 mm: separating force 1429 N, nip angle 12.8 deg, feed resistance 365 N, disc torque 22.1 N m, crank force (one cut: the slit) | 68 | N
D15r | Shear head with the ring head coupled on, wall 1.5 mm: crank force (two ring cuts at once) | 136 | N
D15t | Shear head, wall 1.5 mm: traction of the driven disc over resistance | 1.17
D20 | Stress in the 10 mm web at 1.5 mm wall | 12.1 | MPa
D21 | Bending stress in a 25 mm head shaft at 1.5 mm wall | 17.7 | MPa
D22 | Cutting speed at 30 crank turns a minute through the 2.33 to 1 drive | 4.08 | m/min
D23 | Mass of the trolley, drop bar and shear head | 28.2 | kg
D24 | Rail beam deflection with the head at mid-span | 0.15 | mm
D25 | Mass of the ring head with its spacer plate and coupling | 20.4 | kg
D26 | Rail beam deflection with both heads at mid-span | 0.26 | mm
D27 | Bending stress in the 10 mm spacer plate from the ring head's weight (233 mm out) | 24.4 | MPa
E1 | Drum curvature to take out (radius) | 286.5 | mm
E2 | Width fed at once (three panels side by side) | 700 | mm
E200-8 | Yield 200 MPa, 0.8 mm: bent to reverse radius 278 mm, bending roll 13.4 mm above the lower roll, moment 21.5 N m, bending roll force 239 N, feed resistance | 71 | N
E200-10 | Yield 200 MPa, 1.0 mm: bent to reverse radius 345 mm, bending roll 11.0 mm above the lower roll, moment 33.9 N m, bending roll force 376 N, feed resistance | 112 | N
E200-12 | Yield 200 MPa, 1.2 mm: bent to reverse radius 411 mm, bending roll 9.3 mm above the lower roll, moment 49.1 N m, bending roll force 545 N, feed resistance | 163 | N
E250-8 | Yield 250 MPa, 0.8 mm: bent to reverse radius 225 mm, bending roll 16.4 mm above the lower roll, moment 26.6 N m, bending roll force 295 N, feed resistance | 87 | N
E250-10 | Yield 250 MPa, 1.0 mm: bent to reverse radius 278 mm, bending roll 13.4 mm above the lower roll, moment 41.9 N m, bending roll force 466 N, feed resistance | 138 | N
E250-12 | Yield 250 MPa, 1.2 mm: bent to reverse radius 331 mm, bending roll 11.4 mm above the lower roll, moment 60.8 N m, bending roll force 676 N, feed resistance | 201 | N
E300-8 | Yield 300 MPa, 0.8 mm: bent to reverse radius 189 mm, bending roll 19.3 mm above the lower roll, moment 31.6 N m, bending roll force 351 N, feed resistance | 103 | N
E300-10 | Yield 300 MPa, 1.0 mm: bent to reverse radius 234 mm, bending roll 15.8 mm above the lower roll, moment 49.9 N m, bending roll force 554 N, feed resistance | 164 | N
E300-12 | Yield 300 MPa, 1.2 mm: bent to reverse radius 278 mm, bending roll 13.4 mm above the lower roll, moment 72.5 N m, bending roll force 805 N, feed resistance | 239 | N
E10 | Nominal setting (250 MPa, 1.0 mm): bending roll above the lower roll | 13.4 | mm
E11 | Range of settings over 200 to 300 MPa and 0.8 to 1.2 mm | 9.3 to 19.3 | mm
E12 | Worst sag over 1 m if the nominal setting is used on other drum steel (no trial pass) | 188 | mm
E13 | Allowed error in the bending roll height to stay within 10 mm over 1 m | 0.29 | mm
E14 | That is this much of a turn of the fine-pitch M20 x 1.5 bending screw | 71 | deg
E14d | Dial: 60 divisions a turn, 0.025 mm each; the allowed error in divisions | 11.8
E14c | The same allowed error on the former M20 x 2.5 screw with a 12-division handwheel, in divisions | 1.4
E29 | Strain at a rolling hoop's crown if the hoop were rolled flat with the panel (why the hoops are cut out) | 8.5 | %
E15 | Leading end left unbent (pinch to bending roll) | 90 | mm
E16 | Rise of that unbent end above flat | 14.1 | mm
E17 | Worst bending roll force | 805 | N
E18 | Worst feed resistance (plastic work per mm) | 239 | N
E19 | Pinch force needed for traction (both pinch rolls driven by the gears, friction 0.15, margin 1.5) | 1193 | N
E20 | Pinch force set with the two M16 screws (1 kN each) | 2000 | N
E21 | M16 screw torque for 1 kN; force on the 90 mm handwheel rim | 3.2 N m; 71 | N
E22 | Torque to turn the pinch rolls (worst) | 16.8 | N m
E23 | Crank force at 300 mm through the 3:1 chain | 20 | N
E24 | Feed speed at 30 crank turns a minute | 1.88 | m/min
E25 | Upper pinch roll: load, mid-span deflection | 2805 N; 0.25 | mm
E26 | Upper pinch roll bending stress | 15.5 | MPa
E27 | Bronze bush bearing pressure (30 x 20 mm) | 2.3 | MPa
E28 | Pinch gear tooth stress (Lewis, module 3, 20 mm face) | 15 | MPa
F1 | Drum axis height; top of the drum | 603; 890 | mm
F2 | Roller contact on the hoops, from vertical | 33.0 | deg
F3 | Roller shaft at 1 kN on the drum: stress, deflection | 72 MPa; 3.2 | mm
F4 | Side push that rolls an empty drum over a roller | 122 | N
G1 | Slip roll in-feed slot under the nip guard: slot 8.0 mm, distance to the nip 45 mm, needed 20 mm | meets
G2 | Slip roll out-feed slot: slot 8.0 mm, distance to the nip 85 mm, needed 20 mm | meets
G3 | Shear head front skirt over the sheet: slot 7.5 mm, distance to the nip 52 mm, needed 20 mm | meets
K1 | Notching punch force, chime notch (60 x 35 mm, open-ended, punch face raked 10 deg), 1.5 mm steel | 24.3 | kN
K2 | Notching punch force, hoop slot (40 x 32 mm), 1.5 mm wall | 6.6 | kN
K3 | Screw torque (Tr24 x 5) and lever force at 480 mm, chime notch | 63 N m; 131 | N
K4 | Screw torque and lever force, hoop slot | 17 N m; 36 | N
K5 | Jaw root bending stress, hoop station (lower jaw 56 x 50; upper jaw 40 x 60) | 96; 93 | MPa
K6 | Jaw root bending stress, chime station | 18; 18 | MPa
K7 | Opening of the jaws at the hoop station under the hoop slot force (taken up in the screw stroke) | 1.32 | mm
K8 | Lever swings under load (60 deg each), chime notch; hoop slot | 18; 8
K9 | Time per notch, chime; hoop (place, run the punch down by hand, lever, back off, take out) | 1.2; 0.8 | min
H1 | Purge and vapour check, hands-on minutes per drum | 14
H2 | Cutting cradle minutes per drum | 23.6
H3 | Slip roll and finishing minutes per drum | 15.6
H4 | Total hands-on minutes per drum | 53.1
H5 | Drums per hour for two people, work shared evenly | 2.26
H8 | Notches, slit and ring cuts at the cradle, minutes per drum | 4.0; 2.7; 9.5
H9 | Hands-on minutes per drum for 2.5 drums an hour (R7) | 48.0
H6 | Elapsed purge time per drum (fill, soak 10 min, drain), done while the cradle works | 22.9 | min
H7 | Heads off a drum, both ends, one person (R3) | 3.9 | min
I1 | Drain and purge stand with tray | 15 | kg
I2 | Cutting cradle with posts, beam, shear head, ring head, end cutter, notching punch and tool shelf | 196 | kg
I3 | Slip roll stand with tables | 191 | kg
I4 | Lift 1: Cradle frame, one welded piece | 33.7 | kg
I5 | Lift 2: Shear head with its shafts, discs, guard, drive and drop bar | 23.7 | kg
I6 | Lift 3: Lower pinch roll | 21.0 | kg
I7 | Lift 4: Ring head with its spacer plate and coupling | 20.4 | kg
I8 | Lift 5: Side frame with its legs and bridge, each | 20.1 | kg
I9 | Lift 6: Notching punch, carried to the drum | 18.7 | kg
I10 | Lift 7: Roller shaft with its two rollers, each | 16.3 | kg
I11 | Lift 8: Table frame, each | 16.1 | kg
J1 | Estimated cost of the constructable design (bom/bom.csv) | 3,489 | USD
J2 | Value-engineering target (project.yaml) | 3,000 | USD
J3 | Under (-) or over (+) the target | +489 | USD
J4 | Cost driver 1: 4 Vapour check kit | 600 | USD
J5 | Cost driver 2: 10 Rotary shear head | 340 | USD
J6 | Cost driver 3: 21 Lever notching punch | 330 | USD
J7 | Cost driver 4: 14 Rolls | 285 | USD

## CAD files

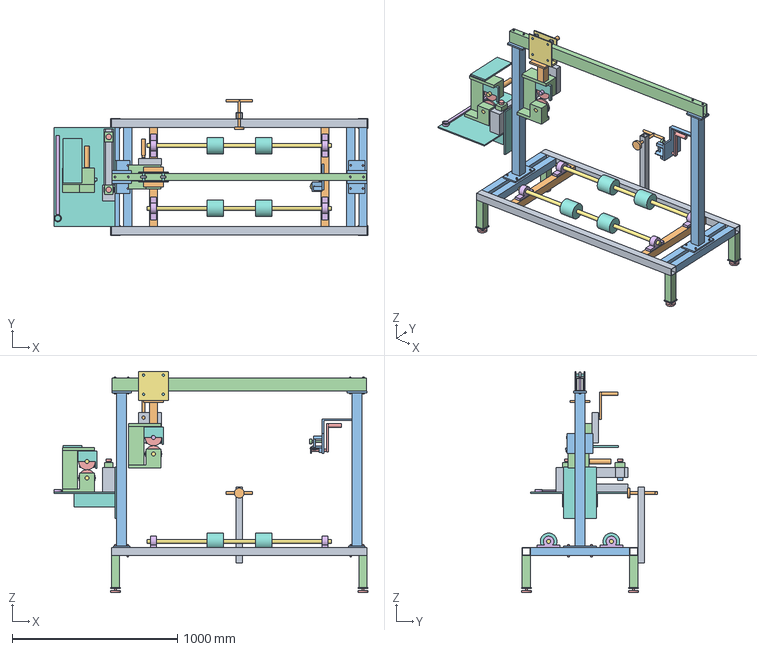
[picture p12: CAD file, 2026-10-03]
cad/step/cutting-cradle.step
1902.5 x 825.0 x 1340.0 mm

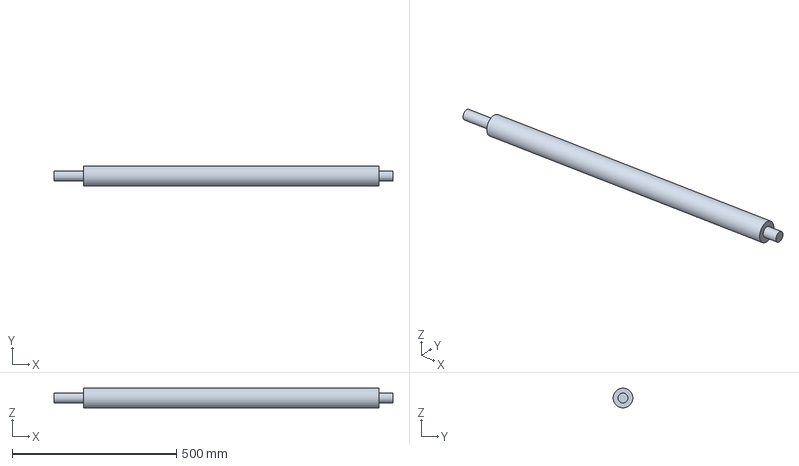
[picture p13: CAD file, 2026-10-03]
cad/step/upper-pinch-roll.step
1032.0 x 60.0 x 59.9 mm

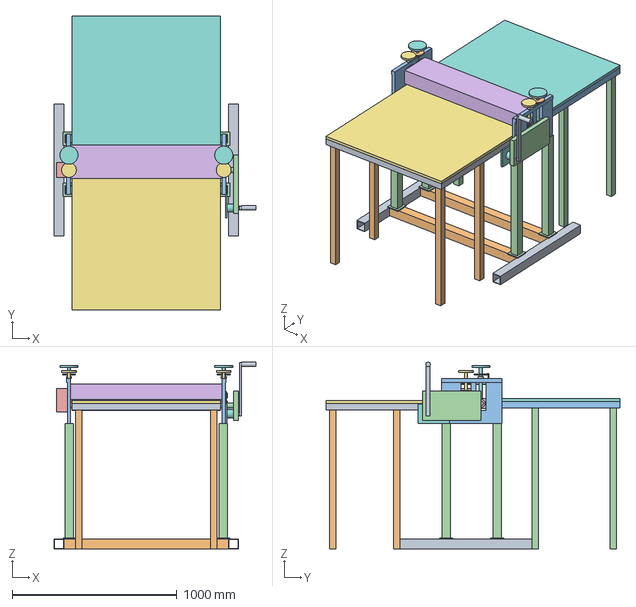
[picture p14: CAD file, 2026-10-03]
cad/step/slip-roll-stand.step
1225.0 x 1785.0 x 1134.0 mm

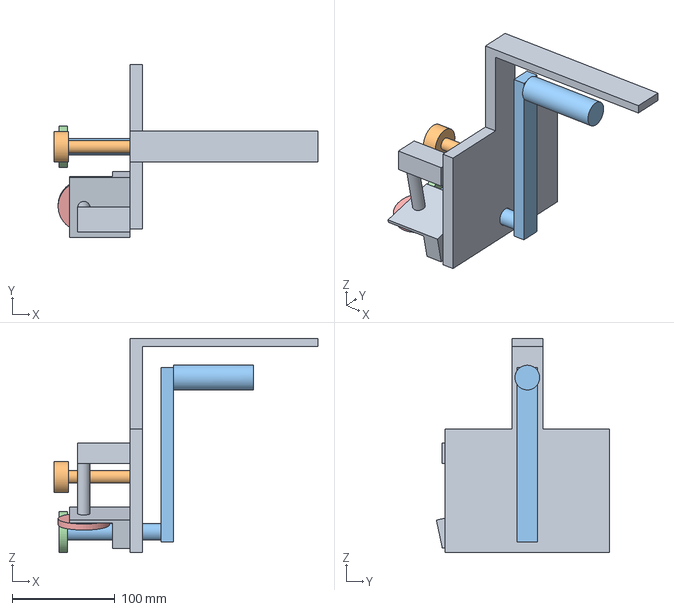
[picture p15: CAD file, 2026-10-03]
cad/step/end-cutter.step
256.5 x 168.4 x 208.0 mm

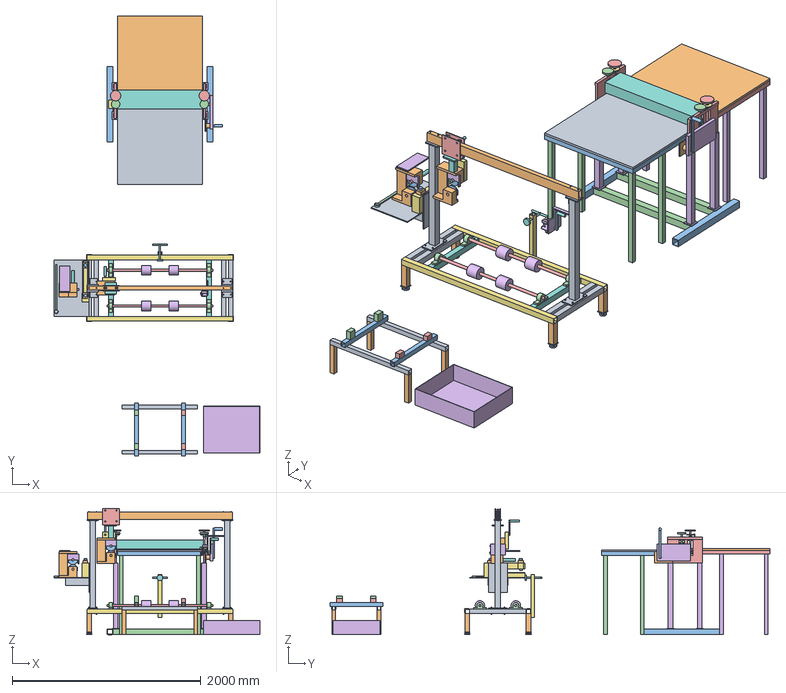
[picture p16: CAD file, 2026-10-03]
cad/step/drumpanel-bench-set.step
2182.5 x 4665.0 x 1340.0 mm

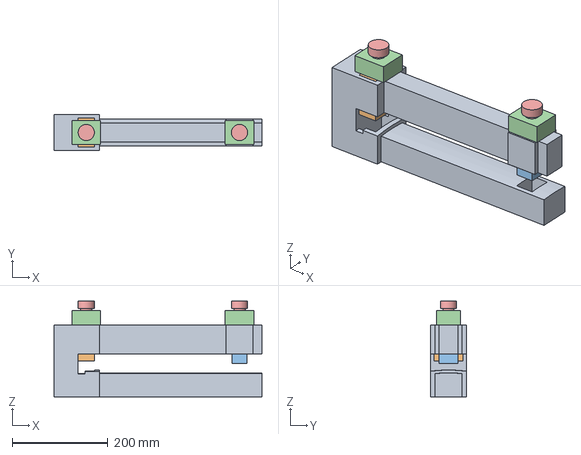
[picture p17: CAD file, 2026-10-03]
cad/step/notching-punch.step
435.0 x 76.0 x 200.0 mm

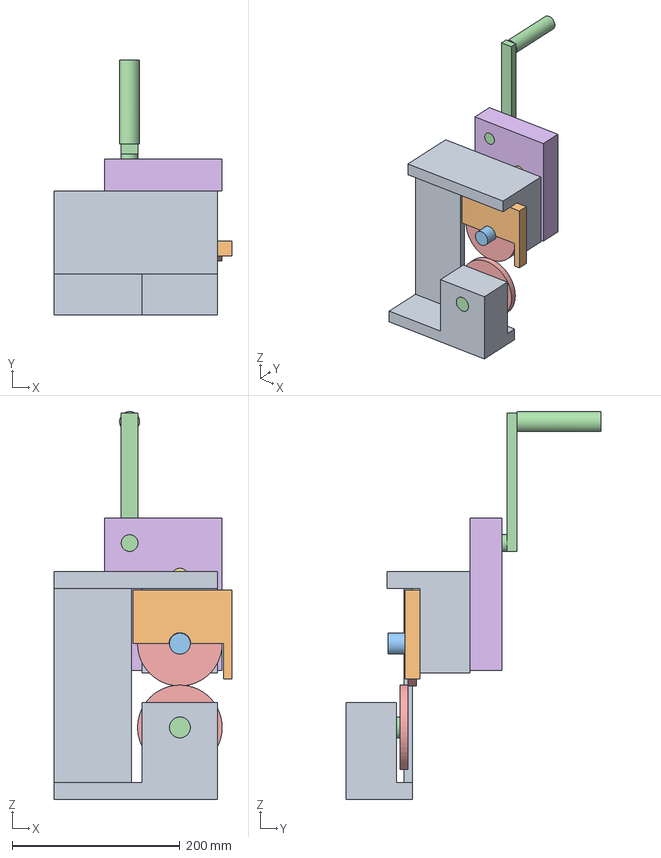
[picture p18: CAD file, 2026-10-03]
cad/step/rotary-shear-head.step
212.0 x 304.0 x 463.0 mm

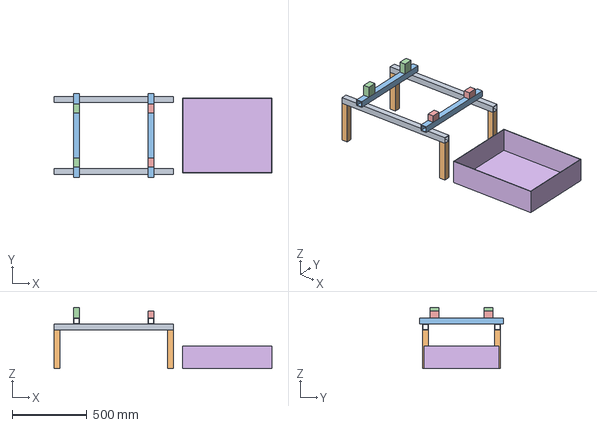
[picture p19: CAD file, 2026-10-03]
cad/step/drain-stand.step
1460.0 x 560.0 x 410.0 mm

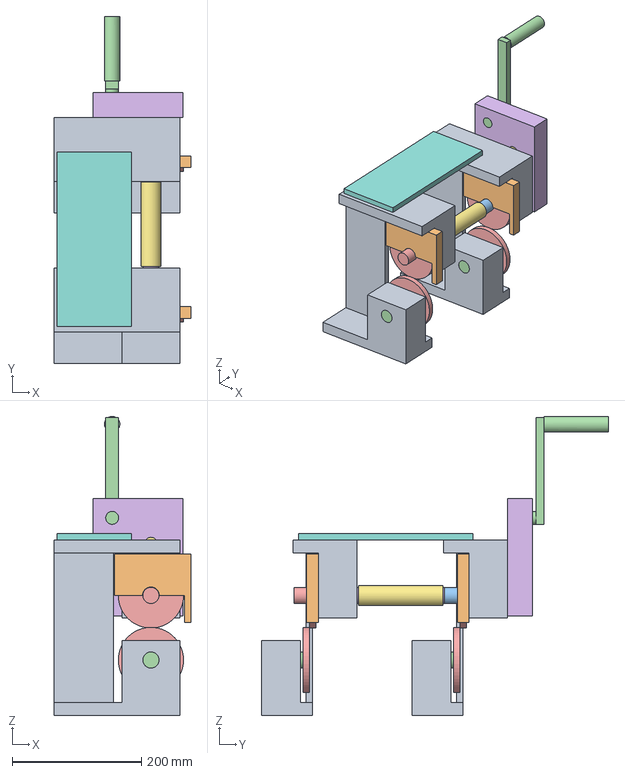
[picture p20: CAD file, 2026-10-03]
cad/step/shear-head-with-ring-head.step
212.0 x 537.0 x 463.0 mm

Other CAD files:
cad/stl/end-cutter.stl
cad/stl/notching-punch.stl
cad/stl/rotary-shear-head.stl

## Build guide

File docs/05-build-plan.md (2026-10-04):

---
doc_id: DMP-BLD-001
title: DrumPanel prototype build plan
project: DrumPanel
doc_type: Build plan
version: "0.3"
status: Draft
date: '2026-10-03'
author: Amish Chadha
license: CERN-OHL-S-2.0
revisions:
- version: "0.1"
  date: '2026-10-03'
  author: Amish Chadha
  change: First build plan; design made constructable (DMP-DDR-002)
- version: "0.2"
  date: '2026-10-03'
  author: Amish Chadha
  change: 'Amish''s requirement decisions of 2026-10-03 (DMP-DDR-003): lever notching punch, ring head, raised shear head drive, dial adjusters on the bending screws, tool shelf'
- version: "0.3"
  date: '2026-10-03'
  author: Amish Chadha
  change: "Throughput check names the TRL 4 timed trial as the test that decides R7 (DMP-DDR-004, Amish's round-2 decision 5A)"
---

# DrumPanel prototype build plan

**Plan, not yet built.** How to build the first proof-of-concept prototype, component by component. Building and testing to it is TRL 4 work. Decisions are kept in the design decisions register ([docs/06-design-decisions.md](06-design-decisions.md)), not here.

## 1. What you are building

Figure 1. Every component, pulled apart and numbered in build order

*Figure 1. Every component pulled apart and numbered in build order.*

The prototype is a hand-powered bench set in three stations that turns an empty 208 L oil drum into flat steel without fire: a drain and purge stand where the drum is washed out with water and checked for vapour, a cutting cradle where the heads are cut out and the body is slit and cut into three panels, and a slip roll that bends the curled panels flat. Beside the cradle stand a lever notching punch, which notches the drum on its slit line before it is slit, and a ring head, a second shear head that is bolted to the first so the ring cuts are made two at a time; both live on a shelf on the left rail post. The overview shows the 24 groups of parts in the order you make or fit them. Nearly everything is sawn, drilled and stick-welded from square tube and plate; the three rolls are turned on a lathe; the slitting discs, the end cutter wheel, the punches and dies, bearings, bushes, gears, chains, the gas detector and the hand tools are bought or made by a tool shop. The parts cost about USD 3,489 from the bill of materials, USD 489 over the USD 3,000 value-engineering target.

> **Safety:** An empty oil drum can still hold flammable vapour and explode when cut, ground or heated. No drum comes near the workshop's welding area, and no drum is cut until it has been purged and has passed the vapour check below 5 % LEL. Building the bench set involves stick welding, grinding and lifts of up to 34 kg; using it involves sharp cut edges and in-running nips at the discs and rolls. Work only within the safety stops of section 6. Nothing in this plan authorises cutting a drum; the first cut is TRL 4 work.

## 2. What changed to make it buildable

The concept named eight tools in words; some could not be made or could not work as described. Each change keeps what DrumPanel does and is recorded in decision record DMP-DDR-002, decided on 2026-10-03. The last four rows carry out Amish's requirement decisions of 2026-10-03 and are recorded in DMP-DDR-003.

*Table 1. Changes from the concept.*

| Component | The concept had | The buildable design has | Why |
| --- | --- | --- | --- |
| Drain and purge station | A tilting stand | A fixed stand sloping 2.9 degrees to the bung end (Figure 2) | A drum full of water weighs about 240 kg and is never tipped |
| Drum cradle and clamps | Not defined | Rollers under the rolling hoops and a screw brake (Figure 5) | The drum must turn for the ring cuts and stay still for the slit |
| End cutter | Cuts each whole end off | Cuts the head out just inside the chime (Figure 21) | No hand wheel cuts the five-layer chime seam |
| Seam slitter | A lever or crank tool | A rotary shear head on a trolley and overhead rail, web running in the cut (Figure 16) | Straight cut; the discs cannot be geared through the drum wall |
| Start of the cut | Not shown | Notches through the chime rings and hoops on the slit line | The discs cannot shear a seam or a ridge |
| Flattening rolls | A three-roll set | A slip roll: geared pinch pair and adjustable bending roll (Figure 31) | A plain three-roll set cannot drive the sheet by friction |
| Drum body | Rolled flat in one piece | Hoop strips cut out; three panels about 233 x 1,800 mm | Rolling a hoop flat would stretch it 8.5 % |
| Ring cuts | A separate tool | The same shear head swivelled 90 degrees on its pivot | One tool |
| Guards | None drawn | Disc guard with skirt, nip guards with 8 mm slots, chain and gear guards, cutter cover (Figure 36) | Fingers kept out of every nip |
| Panel ends | Not considered | Last 90 mm set by hand on the bench plate | A slip roll cannot bend them |
| Side frames | Not considered | Bolted to the base; rolls fitted in order | The lower roll cannot go between welded frames |
| Rail posts | Not drawn | 712.5 mm each side of the middle on two cross members | Room for the end cutter and the parked head |
| Notches | Cut with a hacksaw | Punched with a lever notching punch; the chime notches widened to 60 mm (Figure 23) | Four notches in about 4 minutes instead of 8 |
| Ring cuts, faster | One cut a pass | A ring head bolted to the shear head, so two cuts are made each pass (Figure 26) | Three passes instead of six |
| Shear head crank | On the upper shaft, 200 mm | On a raised crank shaft in a closed 2.33 to 1 chain drive case, 155 mm (Figure 19) | A crank on the upper shaft sweeps through the drum wall; two ring cuts on one crank stay under 150 N |
| Bending roll setting | Screws with marked handwheels | Fine-pitch screws with dials of 0.025 mm and lock nuts (Figure 33) | The setting must be within 0.29 mm and must hold |

## 3. Making the components

Make and check each component before the assembly step that needs it. Sizes are in millimetres. "Left" and "right" are as seen from the front (the drain stand side); "front" is toward the drain stand, "back" toward the slip roll. Workshop tolerance is 0.5 mm unless a step says otherwise. Weld with 3.2 mm E6013 electrodes; fillets are 4 mm on 3 mm tube and 6 mm on plate. Mark every part with its name in paint marker as you make it. No drum is in the workshop while welding or grinding.

### 3.1 Drain and purge stand

Figure 2. Making sketch of the drain stand

*Figure 2. Drain stand making sketch (DMP-DWG-101).*

**What it is and what it is made from.** A low frame that holds a drum on its side, bung end low, over the tray, full of water if need be. 40 x 40 x 3 mm square tube, S275; four hardwood chocks 40 x 60 mm.

**How to make it.**

1. Cut two rails 800 mm, four legs 260 mm and two saddles 560 mm from the tube.
2. Weld a leg square under each end of each rail. Lay the rails 480 mm apart between centres.
3. Weld the saddles across the top of the rails, 500 mm apart between centres, centred on the frame.
4. Cut the chocks: two 70 mm tall and two 45 mm tall. Screw the tall pair to the far saddle and the short pair to the bung-end saddle, with their inner faces 300 mm apart.

**How it fits the parts next to it.**

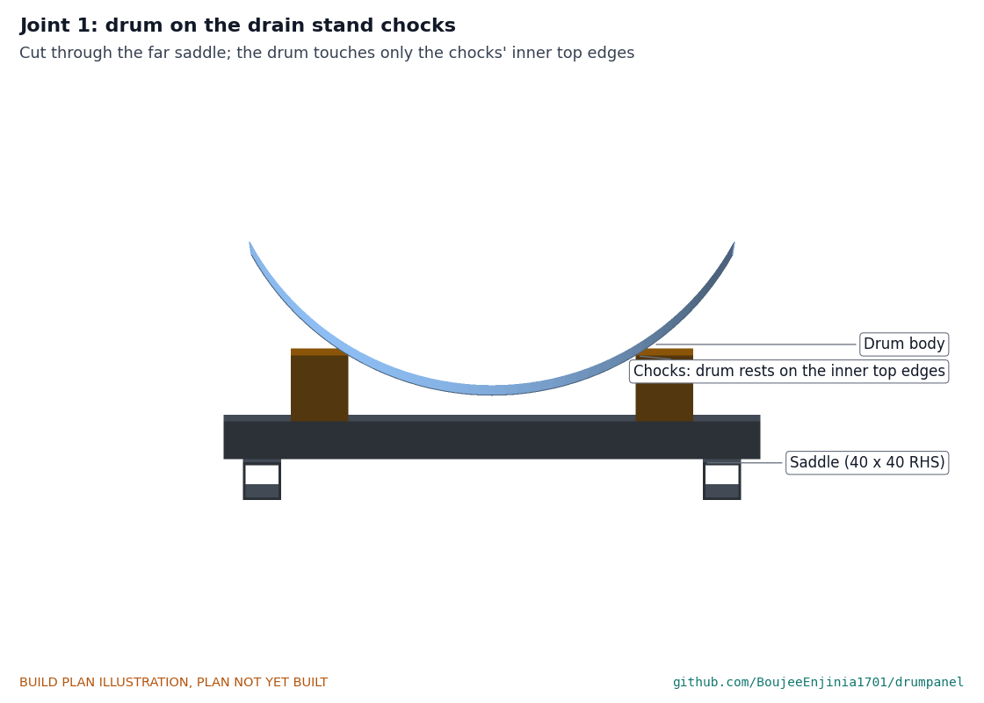
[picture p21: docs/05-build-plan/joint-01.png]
Figure 3. Joint 1: drum on the chocks


*Figure 3. Joint 1. The drum body rests on the inner top edges of the four chocks; nothing else holds it.*

The tray stands on the floor under the bung end, its near edge 60 mm beyond the stand legs.

**Check before moving on.** The stand does not rock on the floor; a drum rolled on sits on all four chocks and falls toward the bung end.

### 3.2 Cradle frame

Figure 4. Making sketch of the cradle frame

*Figure 4. Cradle frame making sketch (DMP-DWG-102).*

**What it is and what it is made from.** The low frame that carries the rollers, the brake and the two rail posts. 50 x 50 x 3 mm square tube, S275; 6 mm foot plates; four M12 nuts and levelling feet.

**How to make it.**

1. Cut two side rails 1,550 mm, six cross members 600 mm and four legs 192 mm.
2. Lay the side rails on a flat table, outer faces 700 mm apart. Weld the cross members between them, centred 520, 675 and 750 mm each side of the middle (the outer pair flush with the ends). Check the diagonals agree within 2 mm.
3. Weld a 60 x 60 x 6 mm foot plate with an M12 nut on its underside to one end of each leg; weld the legs under the four corners.
4. Drill 11 mm holes: two for each pillow block on the 520 mm cross members, 137.5 and 242.5 mm each side of the centre line; four for each post base, 70 mm each side of the centre line, on the 675 and 750 mm members.

**How it fits the parts next to it.** The pillow blocks and post bases bolt on top with M10 bolts; the brake post bolts to the outer face of the right-hand side rail at the middle.

**Check before moving on.** With the feet screwed in 13 mm, the frame top is 273.5 mm from the floor and flat within 2 mm.

### 3.3 Roller shafts with rollers (make 2)

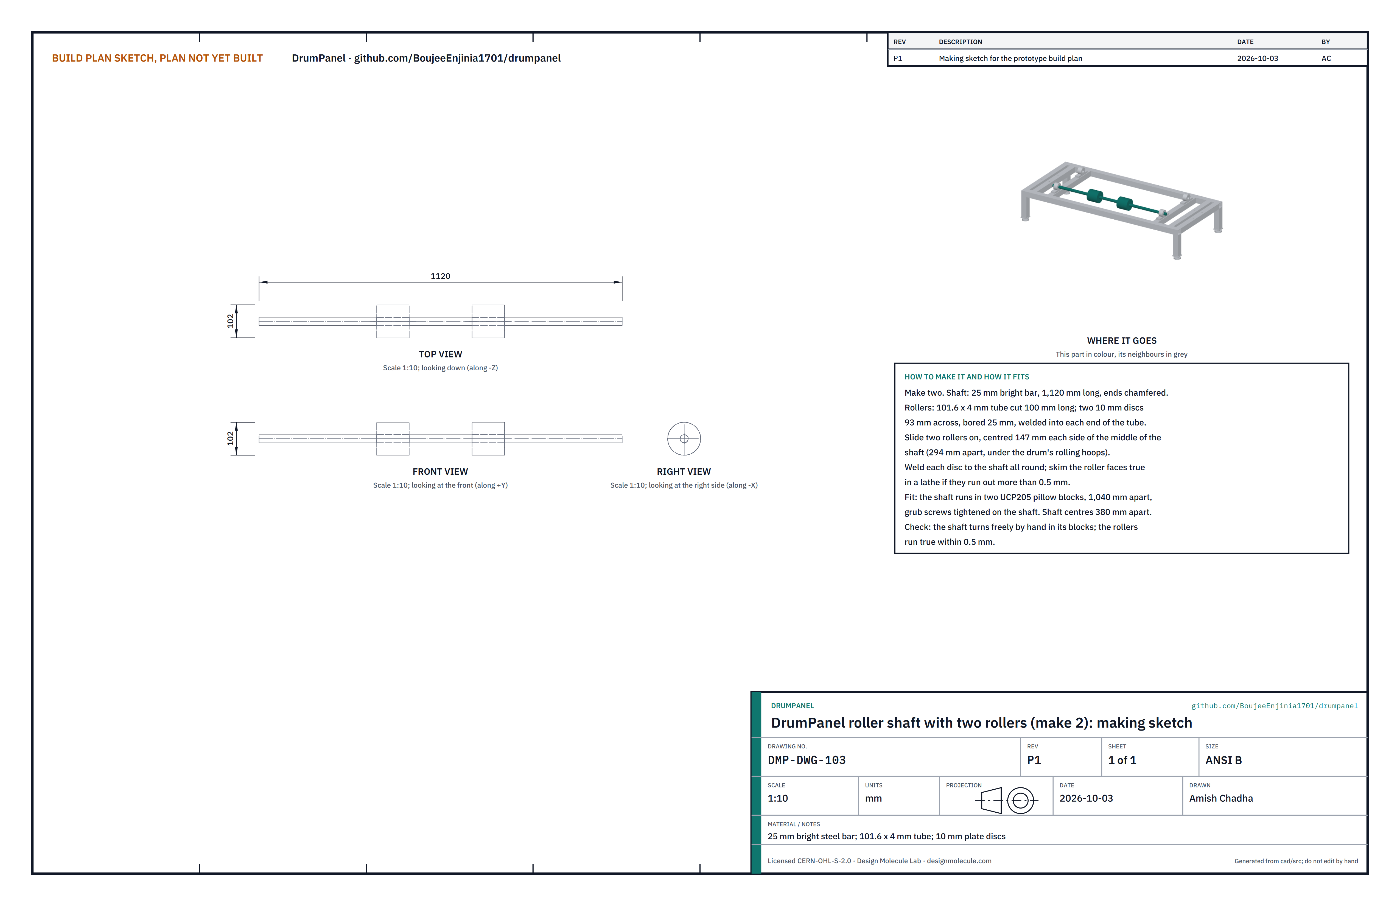
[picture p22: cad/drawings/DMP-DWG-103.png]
Figure 5. Making sketch of a roller shaft


*Figure 5. Roller shaft making sketch (DMP-DWG-103).*

**What it is and what it is made from.** Two shafts, each with two rollers that carry the drum on its rolling hoops. 25 mm bright steel bar; 101.6 x 4 mm tube; 10 mm plate discs; four bought UCP205 pillow blocks.

**How to make it.**

1. Cut each shaft 1,120 mm and chamfer the ends.
2. Cut four tube pieces 100 mm long. Cut eight 10 mm discs 93 mm across, bore them 25 mm, and weld one into each end of each tube piece.
3. Slide two rollers onto each shaft, centred 147 mm each side of its middle. Weld the discs to the shaft all round.
4. Turn the roller faces true in a lathe if they run out more than 0.5 mm.

**How it fits the parts next to it.**

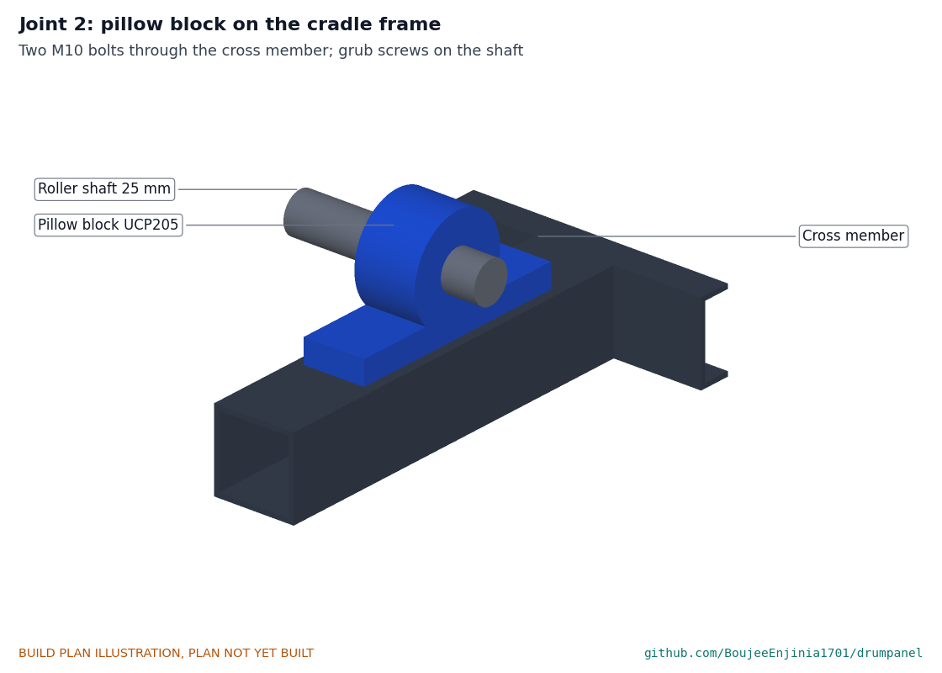
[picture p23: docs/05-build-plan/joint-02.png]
Figure 6. Joint 2: pillow block on the frame


*Figure 6. Joint 2. Each pillow block sits on a 520 mm cross member with two M10 bolts; its grub screws lock the shaft.*

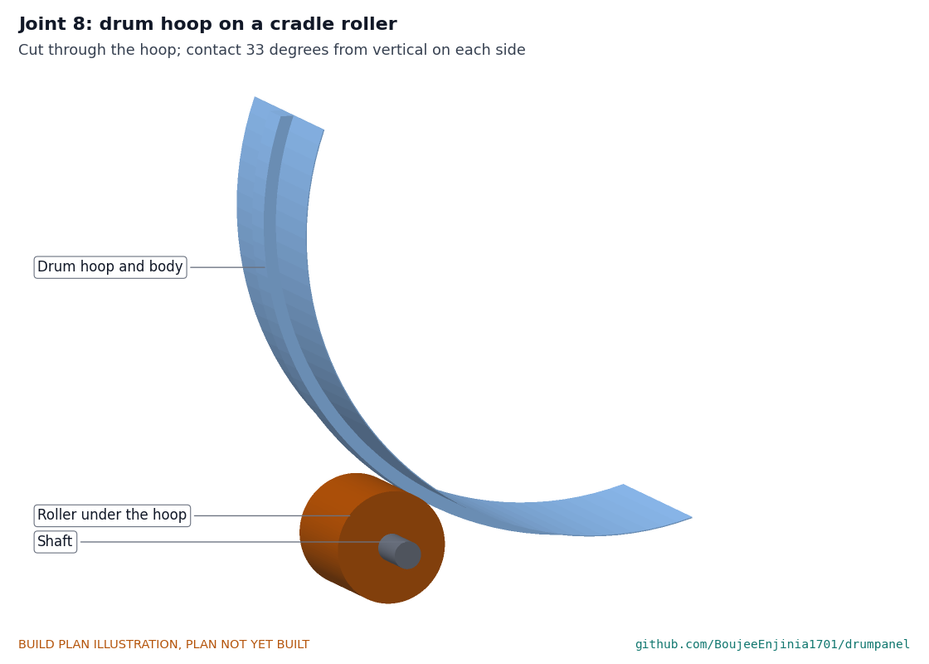
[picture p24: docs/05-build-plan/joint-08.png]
Figure 7. Joint 8: drum hoop on a roller


*Figure 7. Joint 8. The drum's hoop sits on the rollers at 33 degrees from vertical on each side; the shafts are 380 mm apart.*

**Check before moving on.** Each shaft turns freely by hand in its blocks; the rollers run true within 0.5 mm.

### 3.4 Drum brake

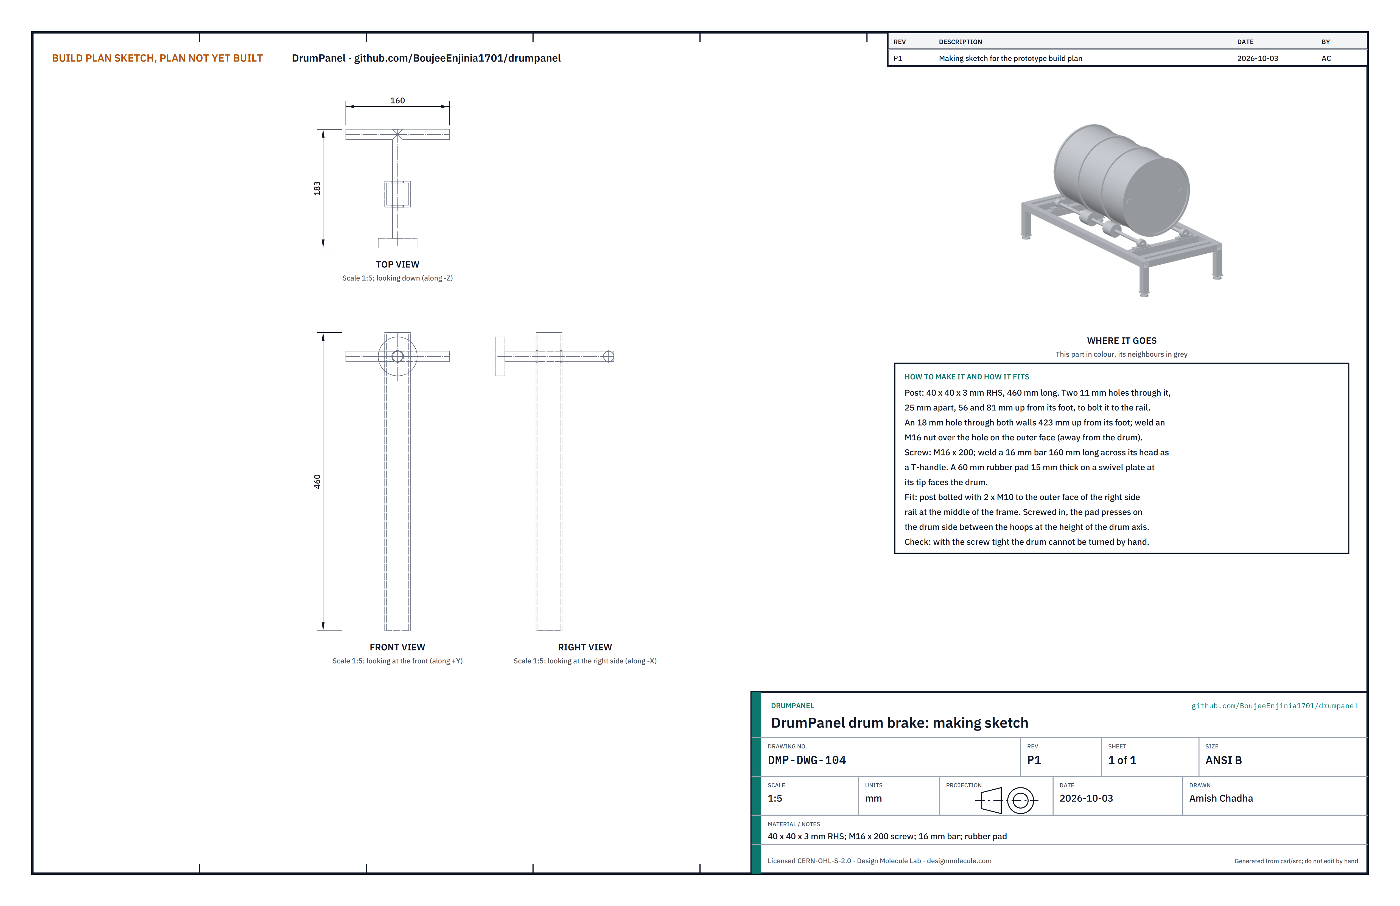
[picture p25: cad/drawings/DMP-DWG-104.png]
Figure 8. Making sketch of the drum brake


*Figure 8. Drum brake making sketch (DMP-DWG-104).*

**What it is and what it is made from.** A screw and pad that hold the drum still while it is slit. 40 x 40 x 3 mm tube; an M16 x 200 screw and nut; 16 mm bar; a 60 mm rubber pad.

**How to make it.**

1. Cut the post 460 mm. Drill two 11 mm holes 25 mm apart, 56 and 81 mm from its foot.
2. Drill an 18 mm hole through both walls 423 mm from the foot. Weld an M16 nut over it on the outer face.
3. Weld a 16 mm bar 160 mm long across the screw head as a T-handle. Fit the rubber pad on a swivel plate at the screw tip.

**How it fits the parts next to it.** The post bolts to the outer face of the right side rail at the middle of the frame with two M10 bolts. Screwed in, the pad presses on the drum side between the hoops, at the height of the drum axis.

**Check before moving on.** With the screw tight, a drum on the rollers cannot be turned by hand.

### 3.5 Rail posts (make 2)

Figure 9. Making sketch of a rail post

*Figure 9. Rail post making sketch (DMP-DWG-105).*

**What it is and what it is made from.** The two posts that hold the rail beam over the cradle. 60 x 60 x 4 mm tube; 10 mm plate.

**How to make it.**

1. Cut each post 926.5 mm with square ends.
2. Cut a base plate 200 x 100 mm with four 11 mm holes on a 75 x 140 mm rectangle, and a cap plate 120 x 80 mm with two 11 mm holes 80 mm apart on its centre line.
3. Weld the post to the middle of both plates, square both ways.
4. Left post only: drill two 11 mm holes straight across it, 550 and 700 mm up from the frame top, for the tool shelf's bolts.

**How it fits the parts next to it.**

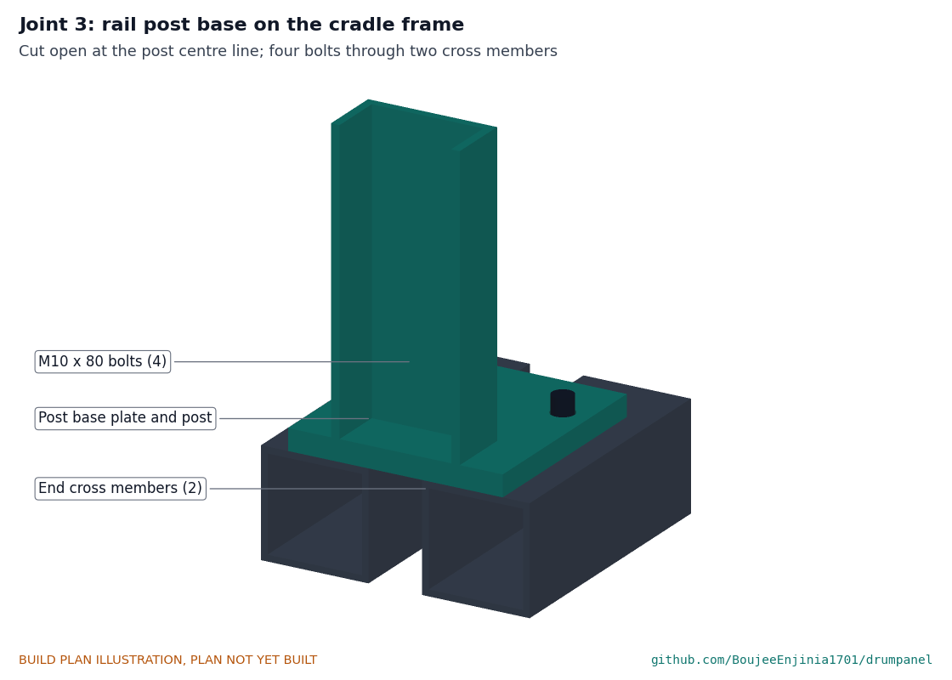
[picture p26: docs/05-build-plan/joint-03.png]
Figure 10. Joint 3: post base on the frame


*Figure 10. Joint 3. The base plate spans the two end cross members and is held by four M10 x 80 bolts.*

**Check before moving on.** Bolted down, each post is upright within 1 mm over its height.

### 3.6 Rail beam

Figure 11. Making sketch of the rail beam

*Figure 11. Rail beam making sketch (DMP-DWG-106).*

**What it is and what it is made from.** The track the shear head runs along. 80 x 40 x 3 mm tube, 1,540 mm long, stood on its narrow edge; four short lengths of 14 mm tube.

**How to make it.**

1. Cut the beam 1,540 mm. File the top face clean of spatter and seam bead: it is the trolley track.
2. Drill two 11 mm vertical holes through both walls at each end, 17.5 and 97.5 mm from the end.
3. Push a 74 mm crush tube into the beam at each hole.

**How it fits the parts next to it.**

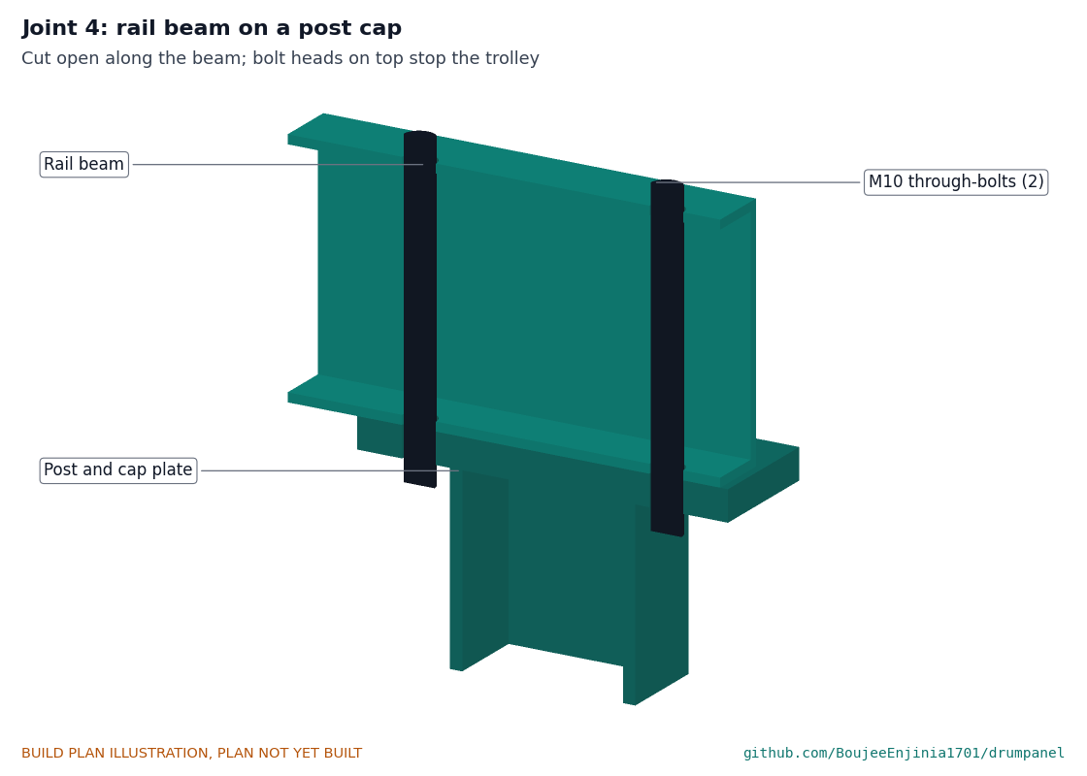
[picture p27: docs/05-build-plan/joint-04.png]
Figure 12. Joint 4: rail beam on a post cap


*Figure 12. Joint 4. Each end sits on a post cap and is held by two M10 x 110 through-bolts; the bolt heads stop the trolley.*

**Check before moving on.** The top face is straight within 1 mm over its length.

### 3.7 Trolley

Figure 13. Making sketch of the trolley

*Figure 13. Trolley making sketch (DMP-DWG-107).*

**What it is and what it is made from.** A carriage that rolls along the beam and carries the shear head on a pivot. 6 mm and 12 mm plate; four bought 6202-2RS bearings; 15 mm bar.

**How to make it.**

1. Cut two side plates 180 x 164 mm. Clamp them together and drill four 15.5 mm axle holes, 60 mm each side of the middle, 141.5 and 25.5 mm up from the bottom edge.
2. Cut a swivel plate 180 x 58 x 12 mm. Drill a 31 mm pivot hole in its middle and two 10.5 mm index holes 45 mm from it, at 0 and 90 degrees.
3. Weld the side plates on top of the swivel plate, inner faces 46 mm apart.
4. Cut four 15 mm axles 58 mm long, threaded M15 or held by circlips; spacers centre each bearing.

**How it fits the parts next to it.**

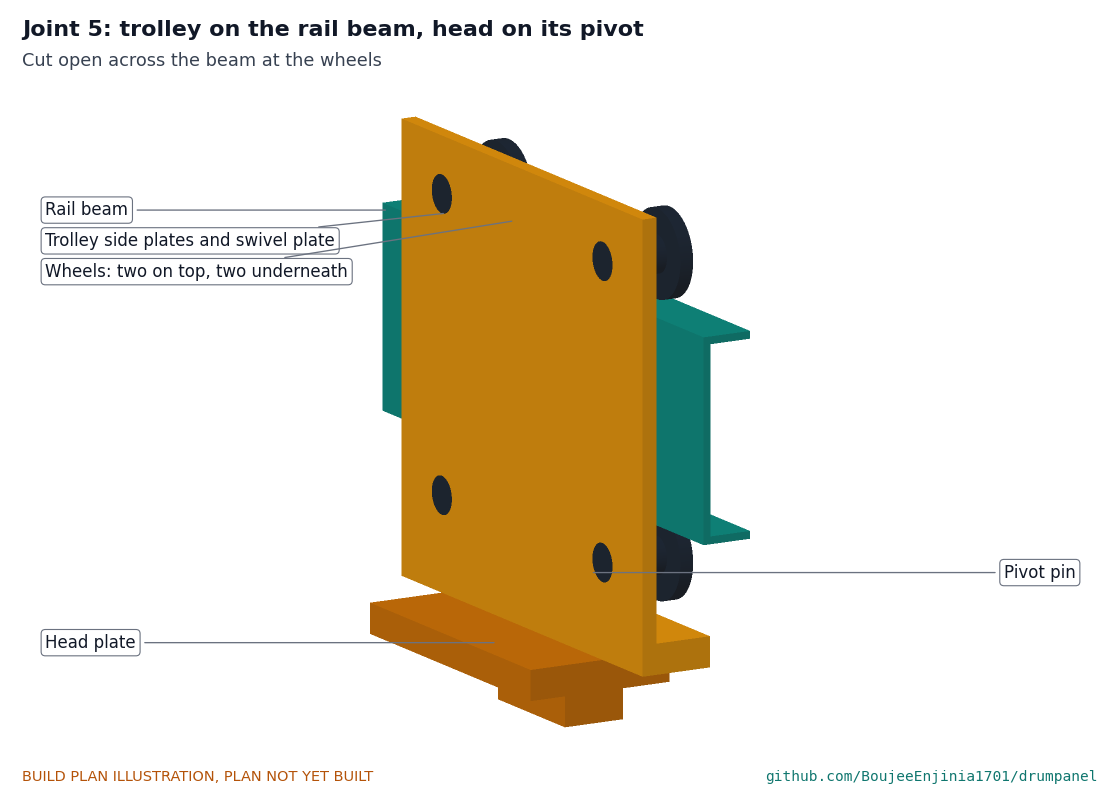
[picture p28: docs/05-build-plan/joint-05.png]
Figure 14. Joint 5: trolley on the beam, head on its pivot


*Figure 14. Joint 5. Two wheels ride on top of the beam and two run 1 mm under it, so the trolley cannot lift off; the head plate hangs from the pivot pin.*

**Check before moving on.** The trolley rolls the full length of the beam by hand without tight spots.

### 3.8 Drop bar, head plate and pivot pin

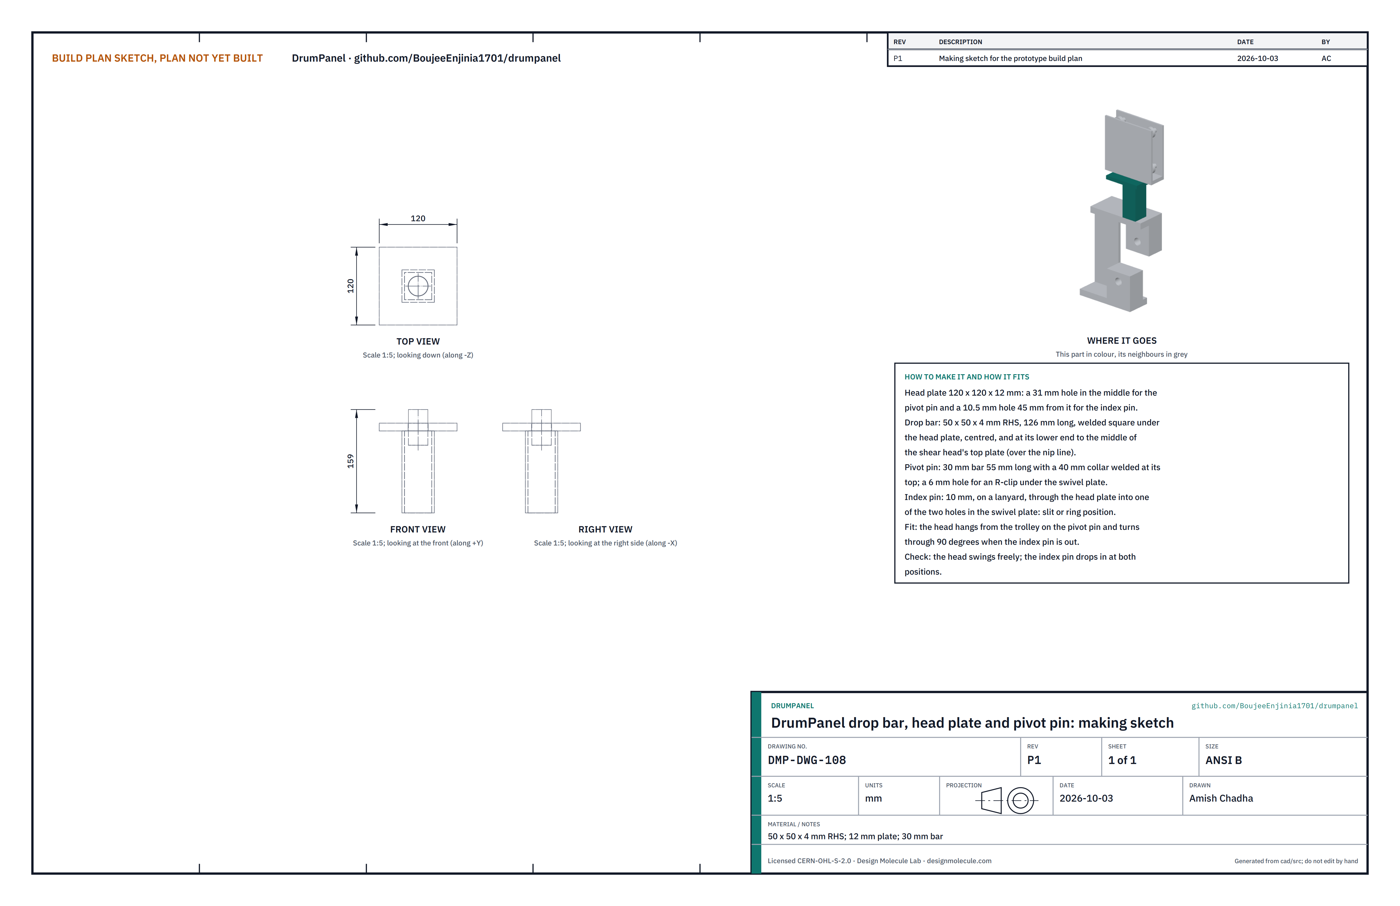
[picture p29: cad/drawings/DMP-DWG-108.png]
Figure 15. Making sketch of the drop bar


*Figure 15. Drop bar, head plate and pivot pin making sketch (DMP-DWG-108).*

**What it is and what it is made from.** The link between the trolley and the shear head. 50 x 50 x 4 mm tube; 12 mm plate; 30 and 10 mm bar.

**How to make it.**

1. Cut the head plate 120 x 120 mm; drill a 31 mm hole in its middle and a 10.5 mm hole 45 mm from it.
2. Cut the drop bar 126 mm and weld it square under the middle of the head plate.
3. Cut the pivot pin 30 mm bar, 55 mm long; weld a 40 mm collar at its top; drill a 6 mm hole for an R-clip.
4. Make a 10 mm index pin on a lanyard.
5. Weld the lower end of the drop bar to the middle of the shear head's top plate, over the nip line, once the head frame is made (section 3.9).

**How it fits the parts next to it.** The pin drops down through the swivel plate and the head plate and takes an R-clip below; the index pin locks the head in its slit or ring position.

**Check before moving on.** With the index pin out the head turns freely through 90 degrees; the index pin drops in at both positions.

### 3.9 Shear head frame

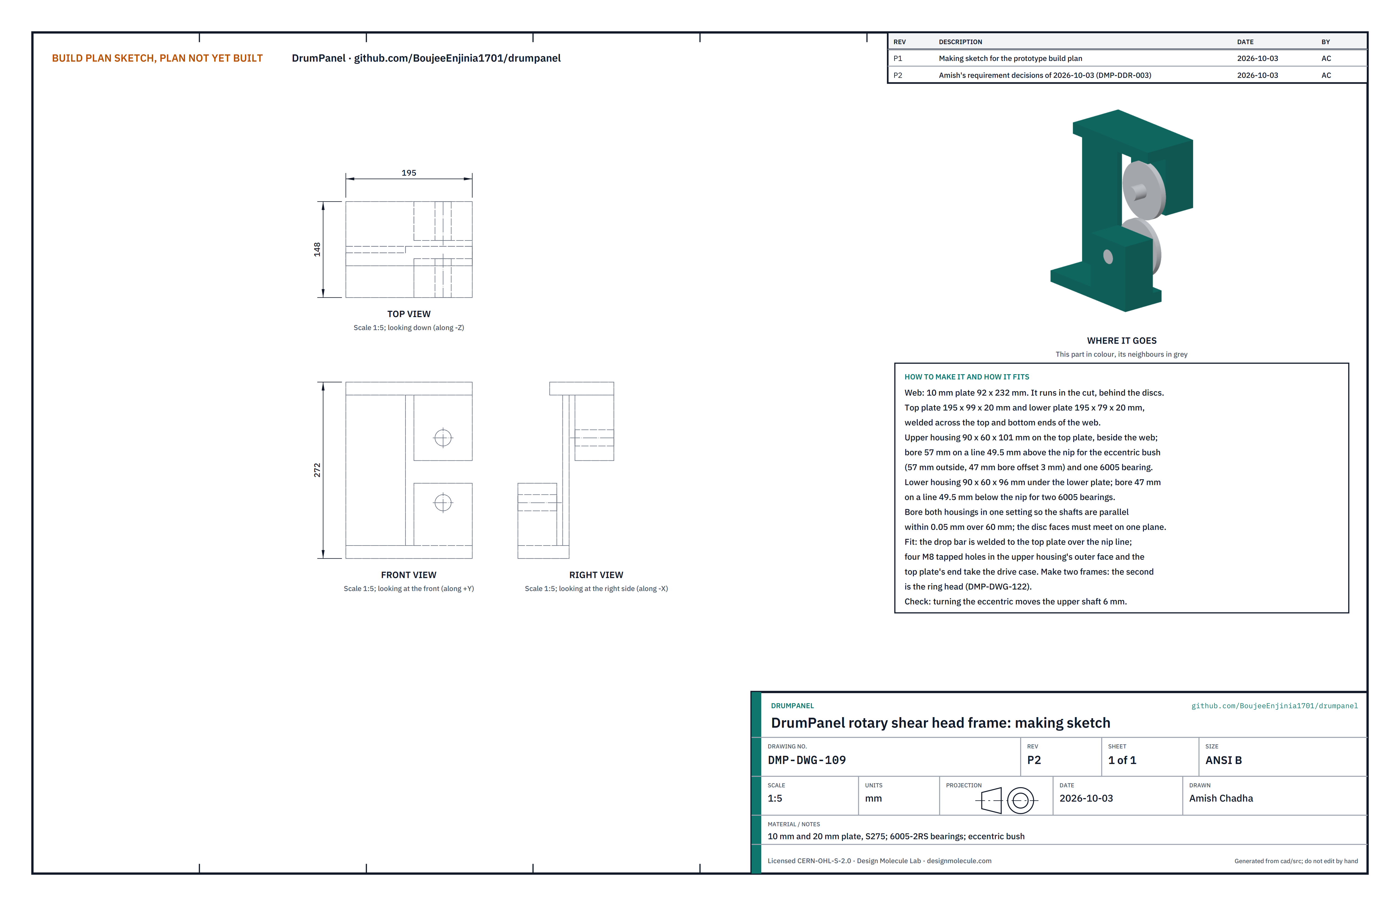
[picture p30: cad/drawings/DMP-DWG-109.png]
Figure 16. Making sketch of the shear head frame


*Figure 16. Shear head frame making sketch (DMP-DWG-109).*

**What it is and what it is made from.** The frame that holds the two slitting discs. Its thin web runs in the cut behind the discs, so the head can travel the full length of the drum. 10 mm and 20 mm plate, S275; bought 6005-2RS bearings; an eccentric bush. Make two frames: the second is the ring head (section 3.14).

**How to make it.**

1. Cut the web 92 x 232 mm from 10 mm plate, the top plate 195 x 99 mm and the lower plate 195 x 79 mm from 20 mm plate.
2. Cut two bearing housings 90 x 60 mm, 101 mm tall (upper) and 96 mm tall (lower).
3. Weld the top and lower plates across the ends of the web, the upper housing under the top plate beside the web, and the lower housing on the lower plate, as the sketch shows.
4. Bore both housings in one setting so the shafts are parallel within 0.05 mm over 60 mm: the upper 57 mm on a line 49.5 mm above the nip line, for the eccentric bush; the lower 47 mm on a line 49.5 mm below it, for two bearings.
5. Make the eccentric bush: 57 mm outside, 47 mm bore offset 3 mm, with a lever and a locking set screw.
6. On the main head only, tap four M8 holes for the drive case: two in the outer face of the upper housing and two in the end of the top plate.

**How it fits the parts next to it.**

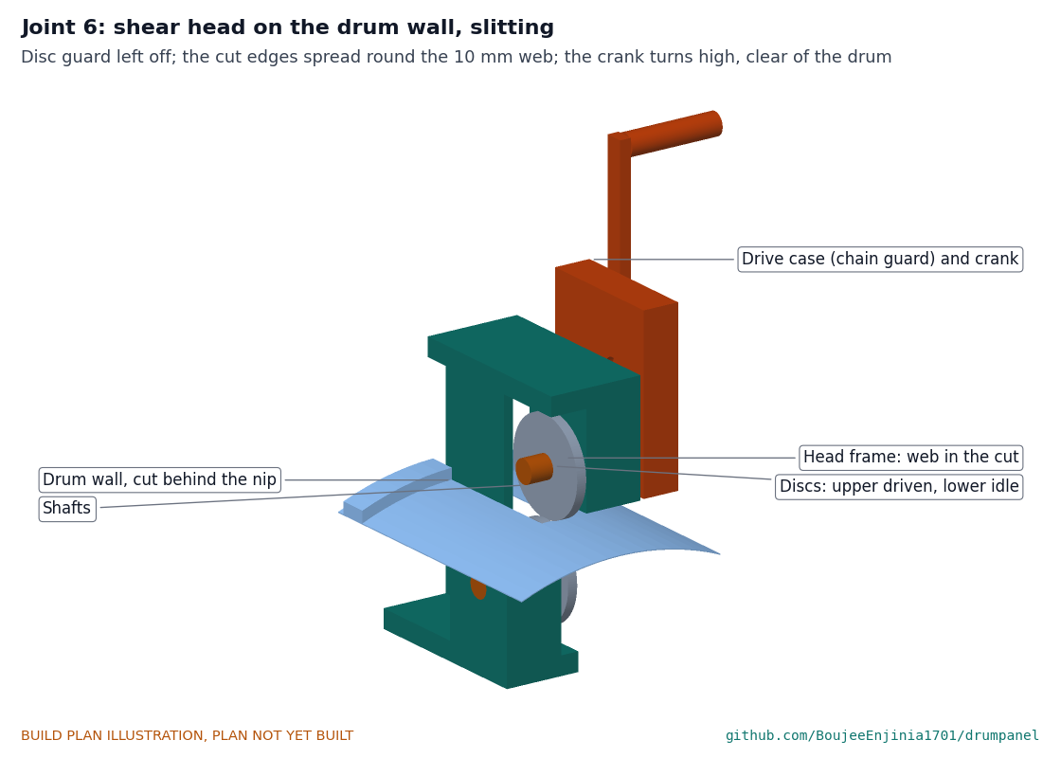
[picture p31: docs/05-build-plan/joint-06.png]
Figure 17. Joint 6: shear head slitting the drum wall


*Figure 17. Joint 6. The upper disc is driven through the drive case, the lower disc runs inside the drum, and the 10 mm web follows in the cut; the cut edges spread round it. The crank turns high on the drive case, clear of the drum. Disc guard left off for clarity.*

**Check before moving on.** Turning the eccentric moves the upper shaft through 6 mm.

### 3.10 Head shafts, discs and drive case

Figure 18. Making sketch of the head shafts

*Figure 18. Head shafts making sketch (DMP-DWG-110).*

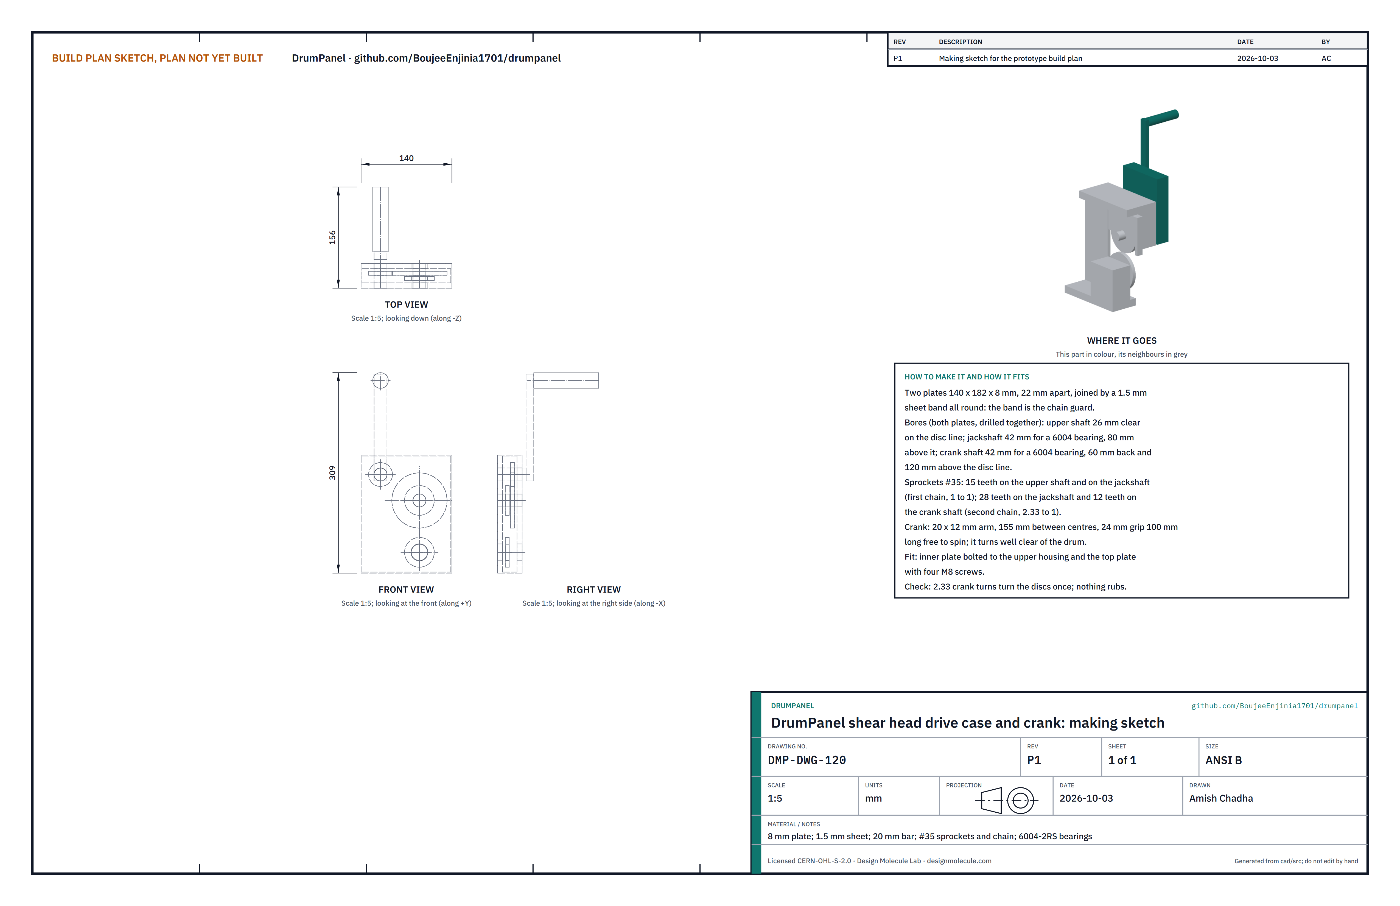
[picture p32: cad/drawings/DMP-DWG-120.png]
Figure 19. Making sketch of the drive case and crank


*Figure 19. Drive case and crank making sketch (DMP-DWG-120).*

**What it is and what it is made from.** The two shafts that carry the discs, and the drive case that turns the upper one from a crank set high on the side of the head, where it cannot hit the drum. 25 mm and 20 mm bright bar; 8 mm plate and 1.5 mm sheet; 20 x 12 mm flat; four bought 6004-2RS bearings; bought #35 sprockets of 12, 28 and two of 15 teeth and about 1 m of #35 chain; two bought D2 slitting discs 101 x 10 mm. Make a second set of shafts and discs, without the drive, for the ring head.

**How to make it.**

1. Turn the upper shaft 120 mm long: a 24 mm stub on the disc side with a 6 mm slot across its end for the ring head coupling, a 35 mm shoulder at the disc, and a keyway at the far end for a 15 tooth sprocket. Turn the lower shaft 74 mm long with the same shoulder.
2. Cut two plates 140 x 182 mm from 8 mm plate and drill them clamped together: a 26 mm clearance hole on the disc line for the upper shaft, and two 42 mm bearing bores, one 80 mm above the disc line for the jackshaft and one 60 mm back and 120 mm above the disc line for the crank shaft.
3. Turn the jackshaft and the crank shaft from 20 mm bar, 38 mm and 44 mm long, with keyways for their sprockets.
4. Fold a 1.5 mm sheet band to join the two plates all round, 22 mm apart; it is the chain guard. Screw it to both plates.
5. Make the crank: a 20 x 12 mm arm with 155 mm between centres and a 24 mm grip 100 mm long that spins freely on a 16 mm pin.
6. Clamp each disc against its shoulder: the lower disc with a countersunk M8 end screw, the upper disc with a clamp collar on the stub, both below the cutting face.

**How it fits the parts next to it.** The two cutting faces meet on one plane with no gap and no rub; shim behind a disc with 0.05 mm shims to get there. Set the overlap to 1.0 mm with the eccentric and lock it. The inner plate of the drive case bolts to the upper housing and the top plate with four M8 screws. The 12 tooth sprocket on the crank shaft drives the 28 tooth on the jackshaft; a 15 tooth beside it drives the 15 tooth on the upper shaft. Fit the chains with about 3 mm of slack before closing the band.

**Check before moving on.** About 2.3 turns of the crank turn the discs once; nothing rubs; a strip of 1 mm sheet cuts cleanly by hand.

### 3.11 Disc guard

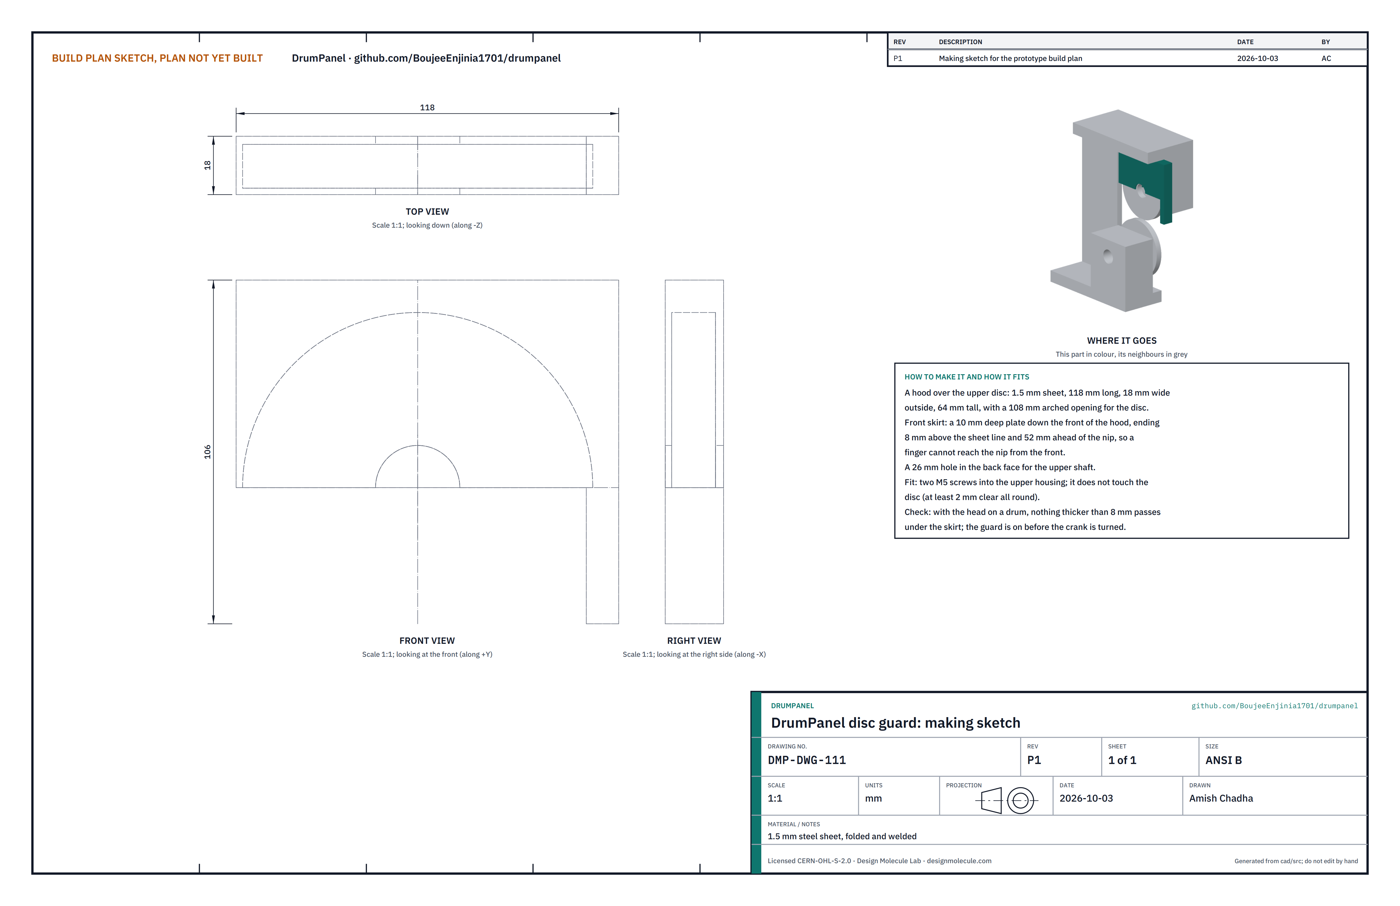
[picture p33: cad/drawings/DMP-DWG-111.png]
Figure 20. Making sketch of the disc guard


*Figure 20. Disc guard making sketch (DMP-DWG-111).*

**What it is and what it is made from.** A hood over the upper disc with a skirt at its front. 1.5 mm steel sheet. Make two: one for the ring head.

**How to make it.**

1. Fold and weld a hood 118 mm long, 18 mm wide outside and 64 mm tall, with a 108 mm arched opening for the disc and a 26 mm hole in its back face for the shaft.
2. Weld a 10 mm deep skirt down the front of the hood, ending 8 mm above the sheet line and 52 mm ahead of the nip.

**How it fits the parts next to it.** Two M5 screws into the upper housing; the hood clears the disc by at least 2 mm all round.

**Check before moving on.** With the head on a drum, nothing thicker than 8 mm passes under the skirt.

### 3.12 End cutter

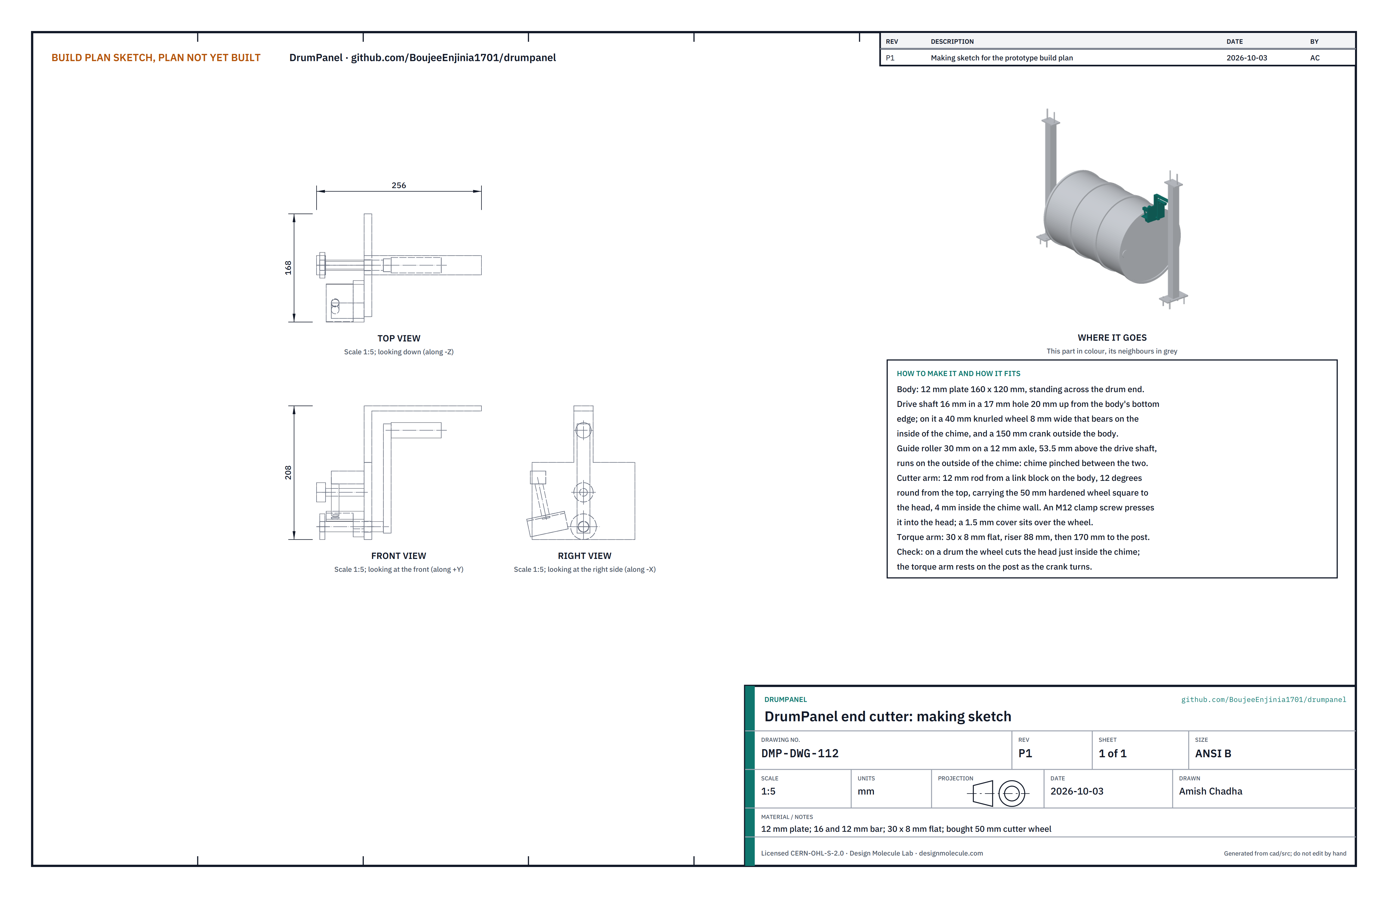
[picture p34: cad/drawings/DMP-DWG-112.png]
Figure 21. Making sketch of the end cutter


*Figure 21. End cutter making sketch (DMP-DWG-112).*

**What it is and what it is made from.** The tool that cuts each head out of the drum just inside the chime. 12 mm plate; 16 and 12 mm bar; 30 x 8 mm flat; a bought 50 mm hardened cutter wheel.

**How to make it.**

1. Cut the body 160 x 120 mm from 12 mm plate. Drill a 17 mm hole for the drive shaft 20 mm up from its bottom edge, centred.
2. Turn a 40 mm drive wheel 8 mm wide and knurl its rim; fit it on a 16 mm shaft with a 150 mm crank outside the body.
3. Turn a 30 mm guide roller on a 12 mm axle and screw the axle into the body 53.5 mm above the drive shaft, so the chime is pinched between the roller (outside) and the drive wheel (inside).
4. Make the cutter arm: a 12 mm rod from a link block on the body, set 12 degrees round from the top, carrying the cutter wheel square to the head, 4 mm inside the chime wall. Fit an M12 clamp screw that presses the wheel into the head, and a 1.5 mm cover over the wheel.
5. Make the torque arm from 30 x 8 mm flat: an 88 mm riser on the body, then 170 mm across to the rail post.

**How it fits the parts next to it.**

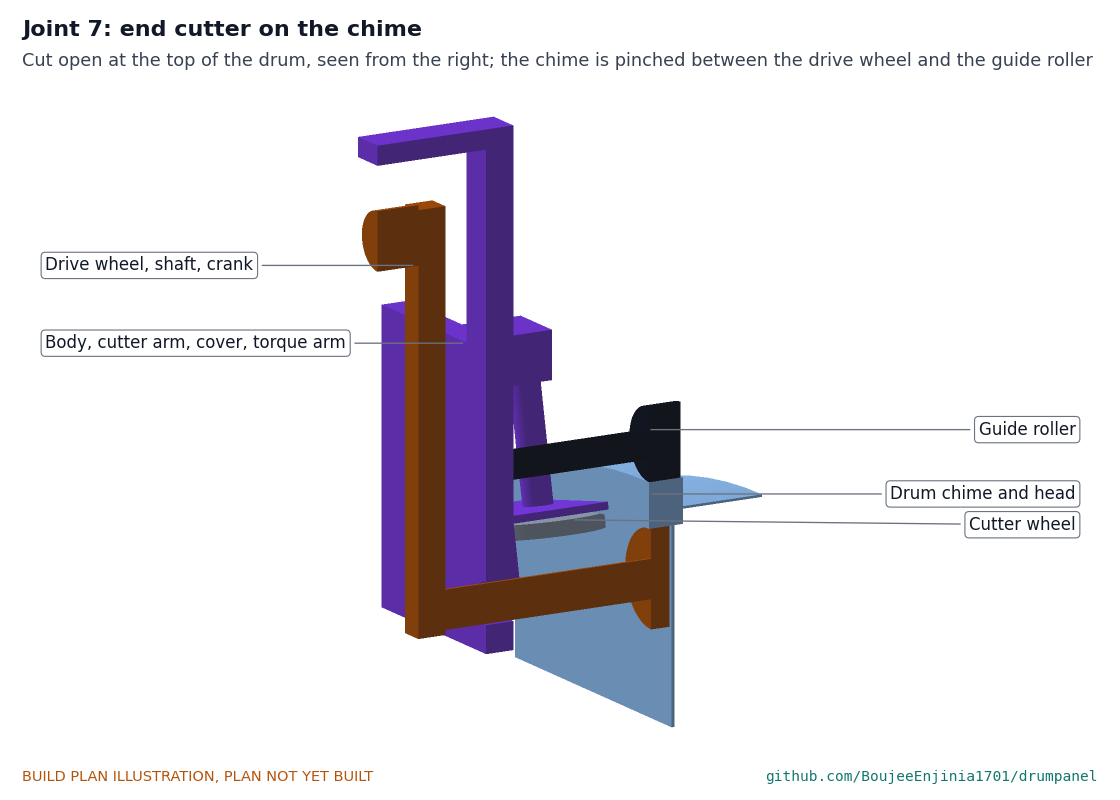
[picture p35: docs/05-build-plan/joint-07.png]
Figure 22. Joint 7: end cutter on the chime


*Figure 22. Joint 7. The drive wheel bears on the inside of the chime and the guide roller on its outside; the cutter wheel bites the head just inside the chime wall.*

**Check before moving on.** On a scrap head or a purged drum, the wheel cuts just inside the chime and the torque arm rests on the post as the crank turns.

### 3.13 Lever notching punch

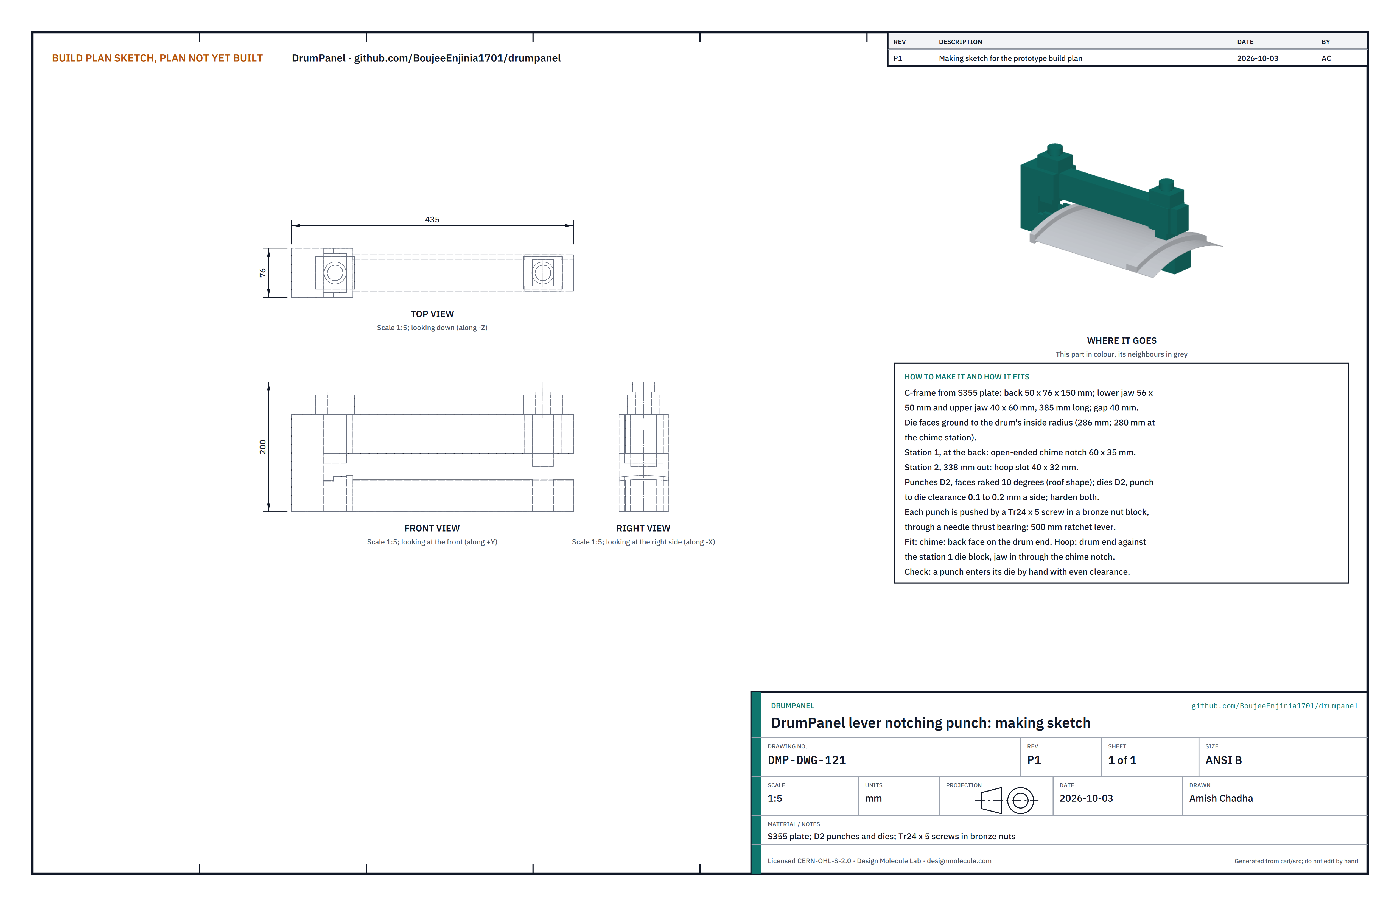
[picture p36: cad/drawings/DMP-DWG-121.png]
Figure 23. Making sketch of the lever notching punch


*Figure 23. Lever notching punch making sketch (DMP-DWG-121).*

**What it is and what it is made from.** A C-shaped punch that slides into the open end of a drum, with one jaw inside and one outside, and punches the four notches on the slit line that let the shear head start and pass: an open-ended notch 60 mm wide and 35 mm deep through the chime at each end, and a slot 40 x 32 mm through each hoop. S355 plate for the frame; two D2 punches and dies, made and hardened by a tool shop; two Tr24 x 5 screws in bronze nut blocks; two needle thrust bearings; a bought 500 mm ratchet lever with a socket to suit the screws. About 19 kg.

**How to make it.**

1. Cut the back 50 x 76 x 150 mm, the lower jaw 385 x 56 x 50 mm and the upper jaw 385 x 40 x 60 mm from S355 plate. Weld the jaws to the back with a 40 mm gap between them, square and parallel.
2. Weld a die block 45 x 76 mm under the back end of the gap (station 1) and a guide boss 56 mm wide over the jaw 338 mm out from the back (station 2), as the sketch shows.
3. Cut the die openings through the lower jaw: 60 x 35 mm at station 1, starting at the back face; 40 x 32 mm at station 2. Cut matching guide bores through the upper jaw and its bosses.
4. Grind the top of the lower jaw to the inside radius of the drum wall (286 mm) and the back part of the station 1 die block to the inside of the chime (280 mm), so the die faces sit on the steel.
5. Have the punches made from D2 to slide in their bores, faces raked 10 degrees from the middle to each side, with 0.1 to 0.2 mm clearance a side in their dies; harden both.
6. Bolt a nut block with its Tr24 x 5 bronze nut over each station; fit a screw with a hex head, and a needle thrust bearing between screw and punch.

**How it fits the parts next to it.**

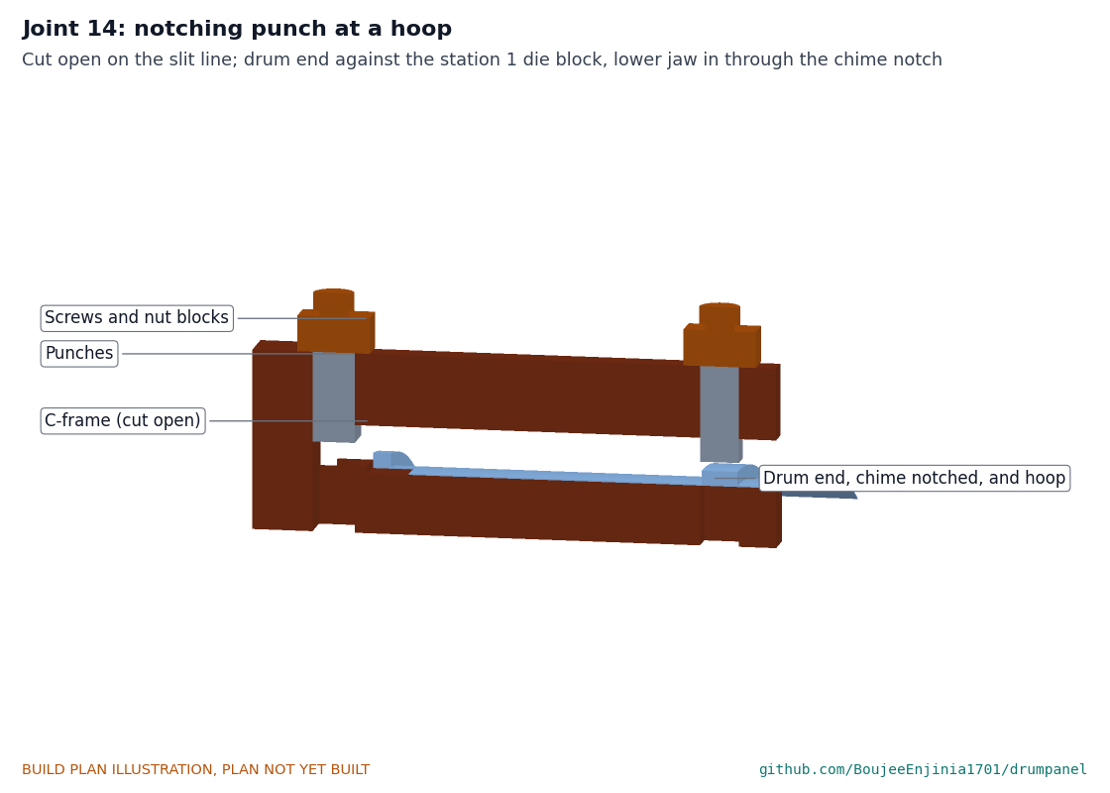
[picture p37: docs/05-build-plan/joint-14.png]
Figure 24. Joint 14: notching punch at a hoop


*Figure 24. Joint 14. Cut open on the slit line. For a hoop slot the drum end rests against the station 1 die block and the lower jaw goes in through the chime notch already cut; the die face sits on the inside of the wall under the hoop.*

Cut the two chime notches first, with the back face of the punch on the drum end and the station 1 die under the chime. Then cut each hoop slot from its own end. Run each punch down by hand until it touches, then work the ratchet lever (about 18 swings for a chime, 8 for a hoop).

**Check before moving on.** Each punch enters its die by hand with an even gap all round; on a scrap chime and a scrap hoop it cuts a clean notch with no more than 150 N on the lever.

### 3.14 Ring head, spacer plate and coupling

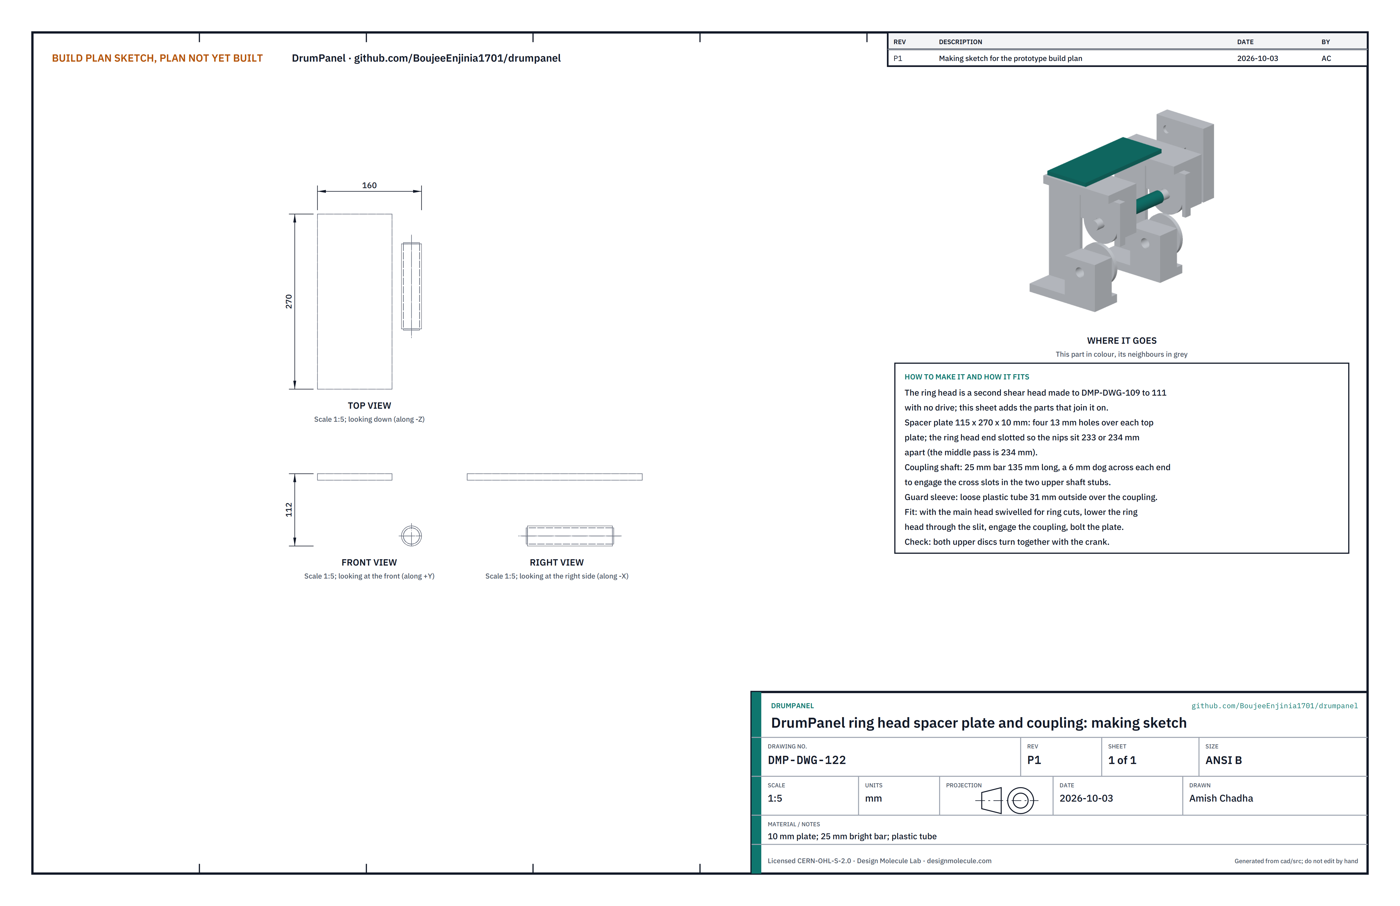
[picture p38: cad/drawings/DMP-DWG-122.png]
Figure 25. Making sketch of the ring head spacer plate and coupling


*Figure 25. Ring head spacer plate and coupling making sketch (DMP-DWG-122).*

**What it is and what it is made from.** A second shear head that is bolted to the main head for the ring cuts, so two cuts are made in each pass. Its frame, shafts, discs and guard are made to the same sketches as the main head's (sections 3.9 to 3.11) without a drive. 10 mm plate for the spacer plate; 25 mm bright bar for the coupling; a plastic tube for its guard sleeve. About 20 kg.

**How to make it.**

1. Make the second frame, shafts, discs and guard to sections 3.9 to 3.11. Its upper shaft is 98 mm long, with the same slotted stub, and has no sprocket.
2. Cut the spacer plate 115 x 270 mm from 10 mm plate. Drill four 13 mm holes over the main head's top plate and slot four over the ring head's, so the nips can sit 233 or 234 mm apart.
3. Cut the coupling shaft 135 mm long from 25 mm bar and weld a 6 mm dog across each end to engage the slots in the two upper shaft stubs.
4. Cut a loose plastic guard sleeve, 31 mm outside, to cover the coupling between the two heads.

**How it fits the parts next to it.**

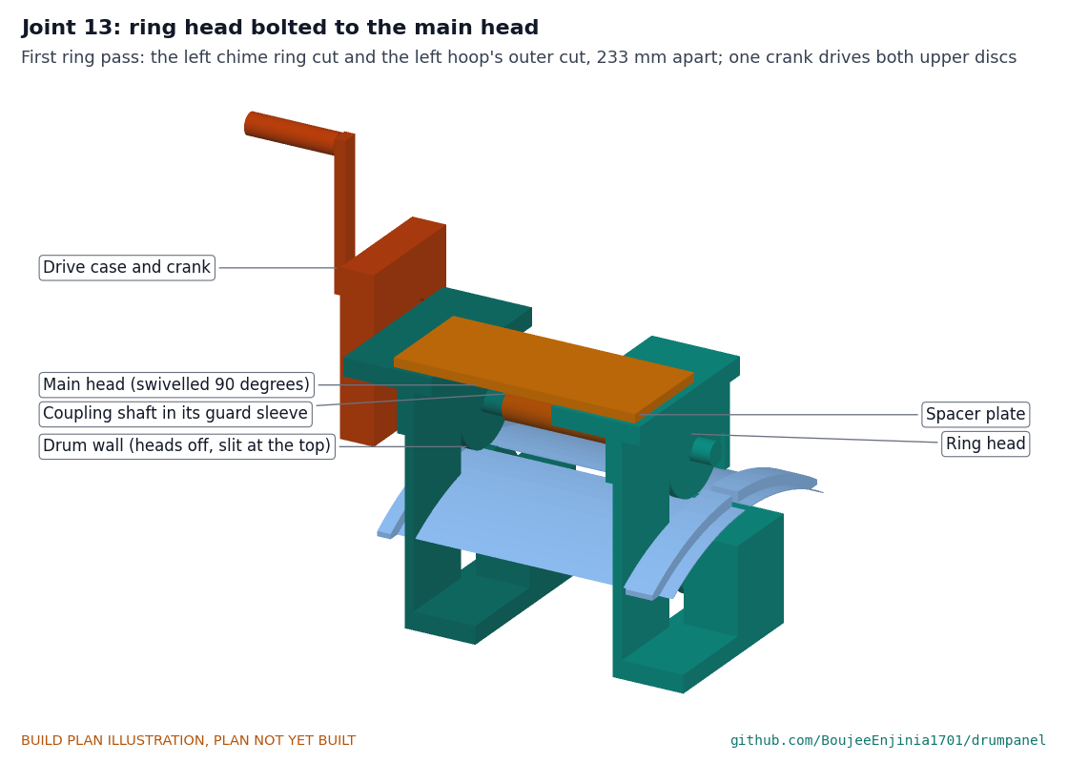
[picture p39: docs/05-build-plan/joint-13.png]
Figure 26. Joint 13: ring head bolted to the main head


*Figure 26. Joint 13. With the main head swivelled for ring cuts, the ring head is lowered through the slit 233 mm along the drum; the spacer plate bolts across both top plates and the coupling joins the two upper shafts, so one crank drives both upper discs.*

**Check before moving on.** Bolted together on the bench, both upper discs turn together when the crank is turned; the two cut planes are parallel within 0.5 mm.

### 3.15 Tool shelf

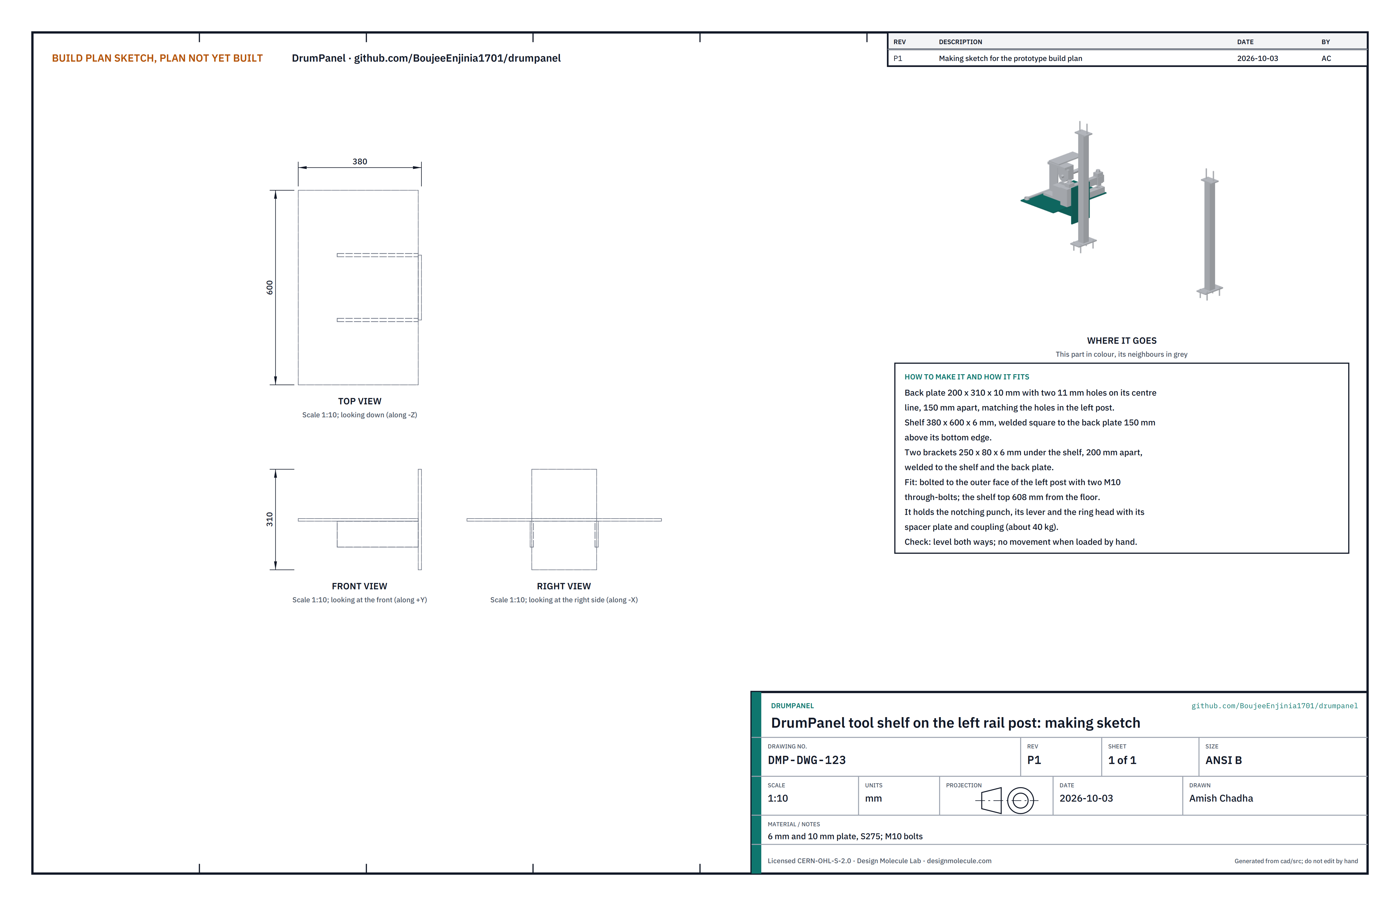
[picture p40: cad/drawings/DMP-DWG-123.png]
Figure 27. Making sketch of the tool shelf


*Figure 27. Tool shelf making sketch (DMP-DWG-123).*

**What it is and what it is made from.** A shelf on the outer face of the left rail post that holds the notching punch, its lever and the ring head with its spacer plate and coupling. 6 mm and 10 mm plate, S275; two M10 bolts. About 14 kg.

**How to make it.**

1. Cut the back plate 200 x 310 mm from 10 mm plate and drill two 11 mm holes on its centre line, 150 mm apart, to match the holes in the left post.
2. Cut the shelf 380 x 600 mm and two brackets 250 x 80 mm from 6 mm plate. Weld the shelf square to the back plate, 150 mm above its bottom edge, with the brackets under it 200 mm apart.

**How it fits the parts next to it.** Two M10 through-bolts hold it to the outer face of the left post, the shelf top 608 mm from the floor.

**Check before moving on.** The shelf is level both ways and does not move when pressed down hard by hand.

### 3.16 Roll stand base

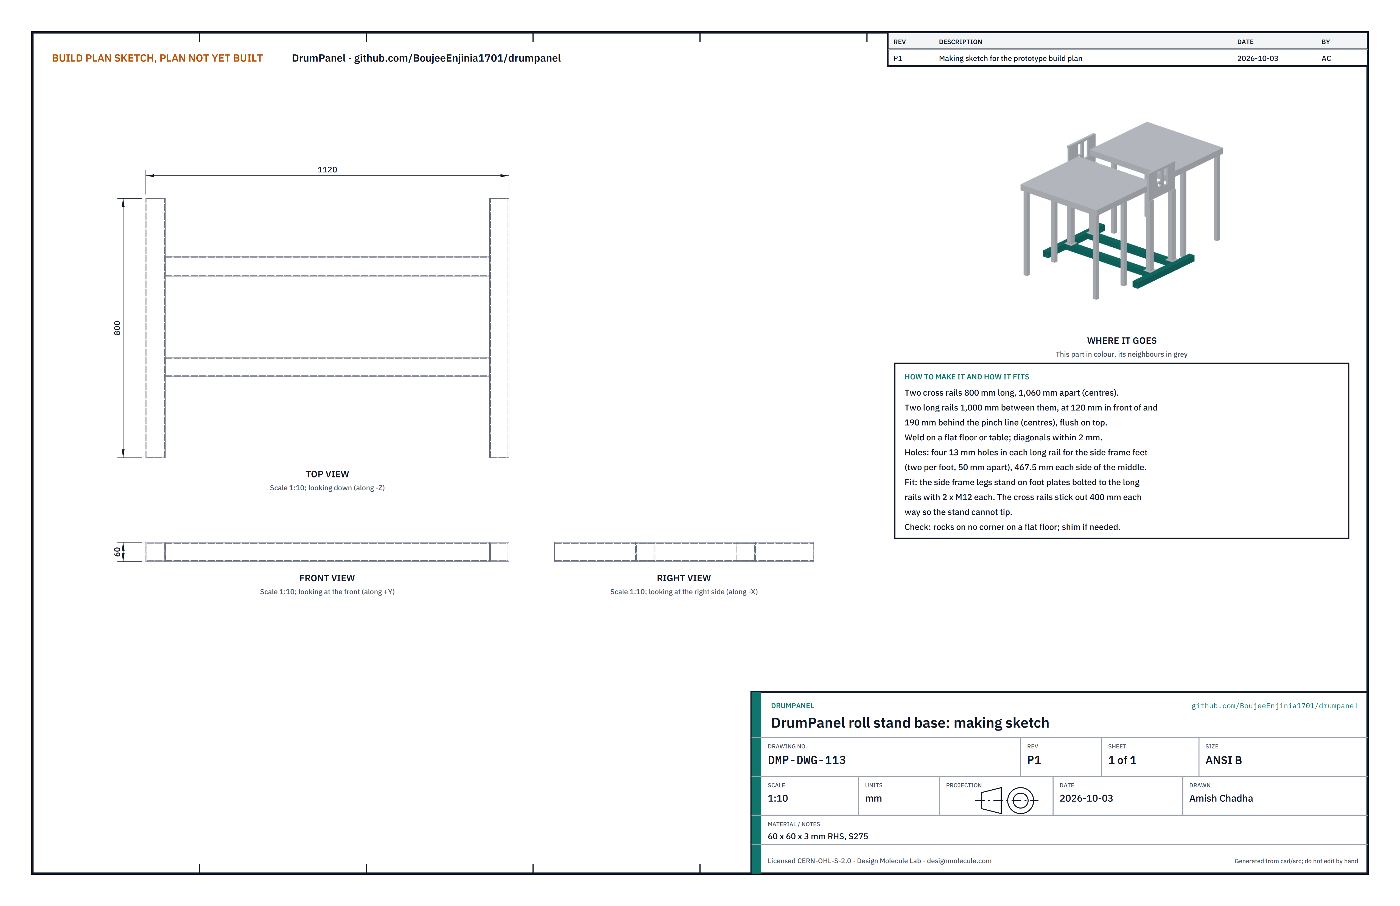
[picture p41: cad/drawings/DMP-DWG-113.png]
Figure 28. Making sketch of the roll stand base


*Figure 28. Roll stand base making sketch (DMP-DWG-113).*

**What it is and what it is made from.** A wide base that keeps the slip roll from tipping. 60 x 60 x 3 mm tube, S275.

**How to make it.**

1. Cut two cross rails 800 mm and two long rails 1,000 mm.
2. Weld the long rails between the cross rails, 120 mm in front of and 190 mm behind the pinch line (centres), the cross rails 1,060 mm apart.
3. Drill two 13 mm holes per side frame foot in the long rails, 50 mm apart, 467.5 mm each side of the middle.

**How it fits the parts next to it.** Each side frame foot bolts to a long rail with two M12 bolts.

**Check before moving on.** The base does not rock on a flat floor; shim it if needed.

### 3.17 Side frames (make 2, mirror pair)

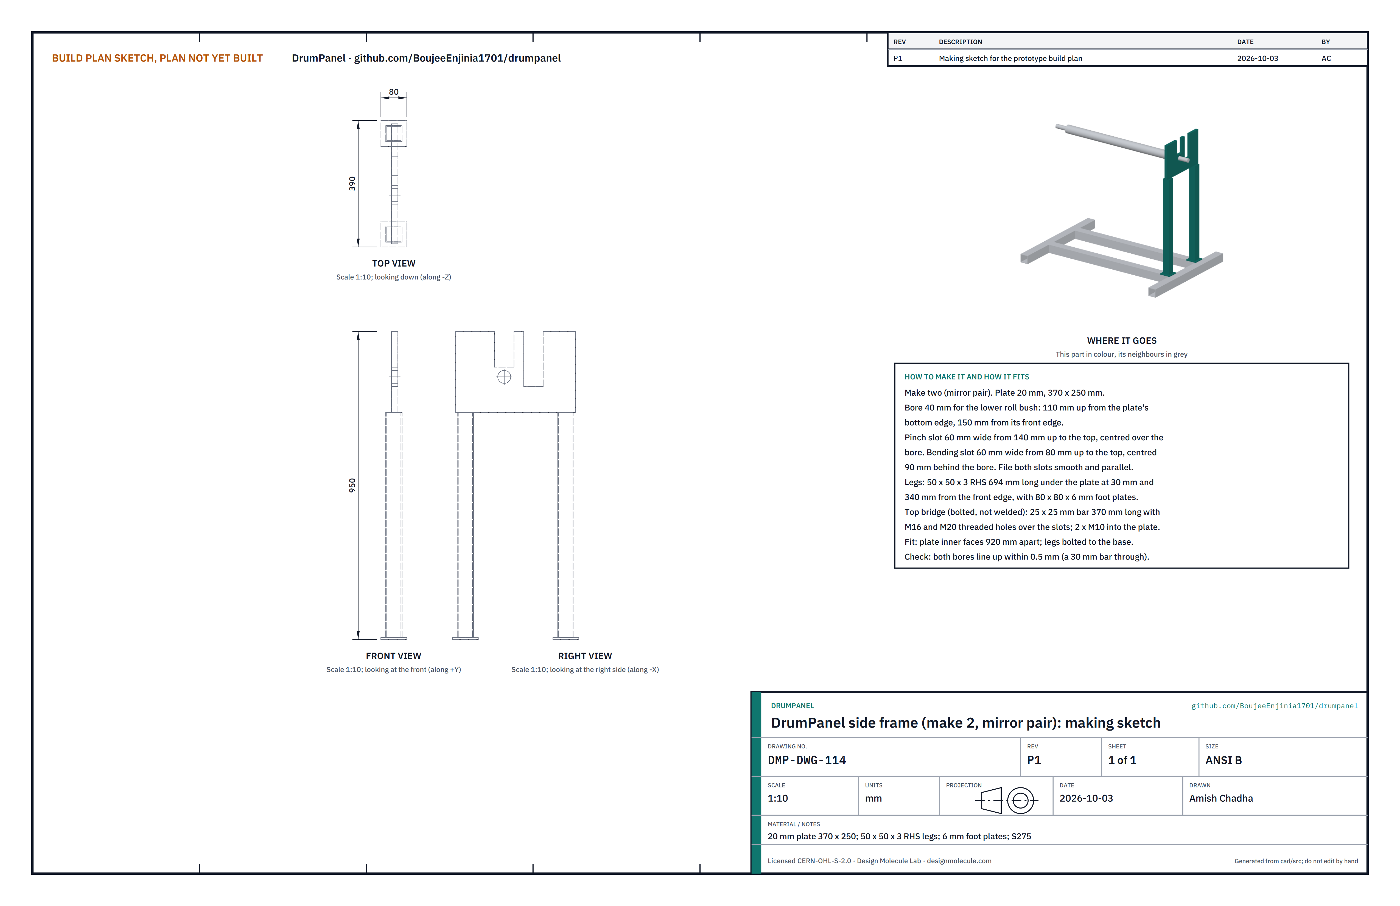
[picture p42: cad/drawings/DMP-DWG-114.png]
Figure 29. Making sketch of a side frame


*Figure 29. Side frame making sketch (DMP-DWG-114).*

**What it is and what it is made from.** The two frames that carry the rolls. 20 mm plate 370 x 250 mm; 50 x 50 x 3 mm tube legs; 6 mm foot plates; a 25 mm top bridge bar.

**How to make it.**

1. Cut the plate 370 x 250 mm. Bore 40 mm for the lower roll bush, 110 mm up from the bottom edge and 150 mm from the front edge.
2. Cut the pinch slot 60 mm wide from 140 mm up to the top edge, centred over the bore, and the bending slot 60 mm wide from 80 mm up to the top, centred 90 mm behind the bore. File both smooth and parallel.
3. Weld two legs 694 mm long under the plate, at 30 and 340 mm from its front edge, each with an 80 x 80 x 6 mm foot plate drilled for two M12 bolts.
4. Make the top bridge: 25 x 25 mm bar 370 mm long, with an M16 threaded hole over the pinch slot and an M20 threaded hole over the bending slot; drill it for two M10 bolts into the plate's front and back prongs.

**How it fits the parts next to it.**

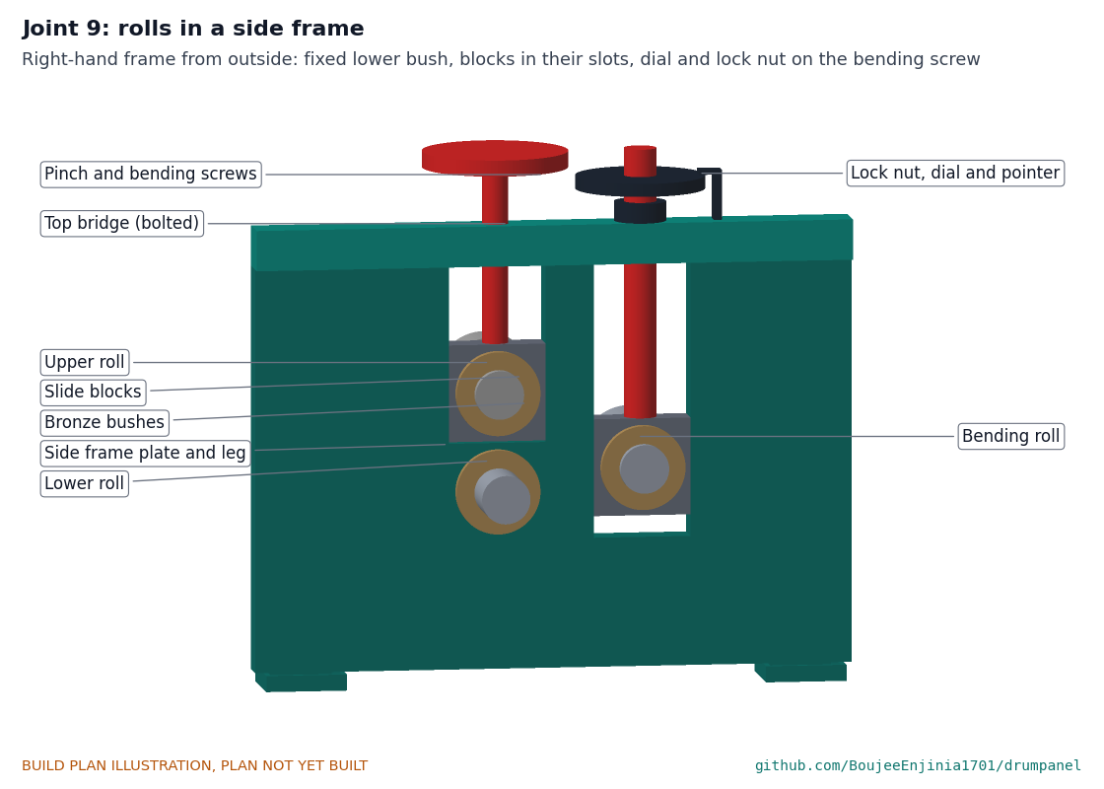
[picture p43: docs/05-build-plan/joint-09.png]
Figure 30. Joint 9: rolls in a side frame


*Figure 30. Joint 9. The lower roll runs in a fixed bush; the upper and bending rolls run in bushes in slide blocks, moved by the screws in the bolted top bridge.*

**Check before moving on.** With both frames on the base, a 30 mm bar passes through both lower bores; they line up within 0.5 mm.

### 3.18 Rolls (make 3)

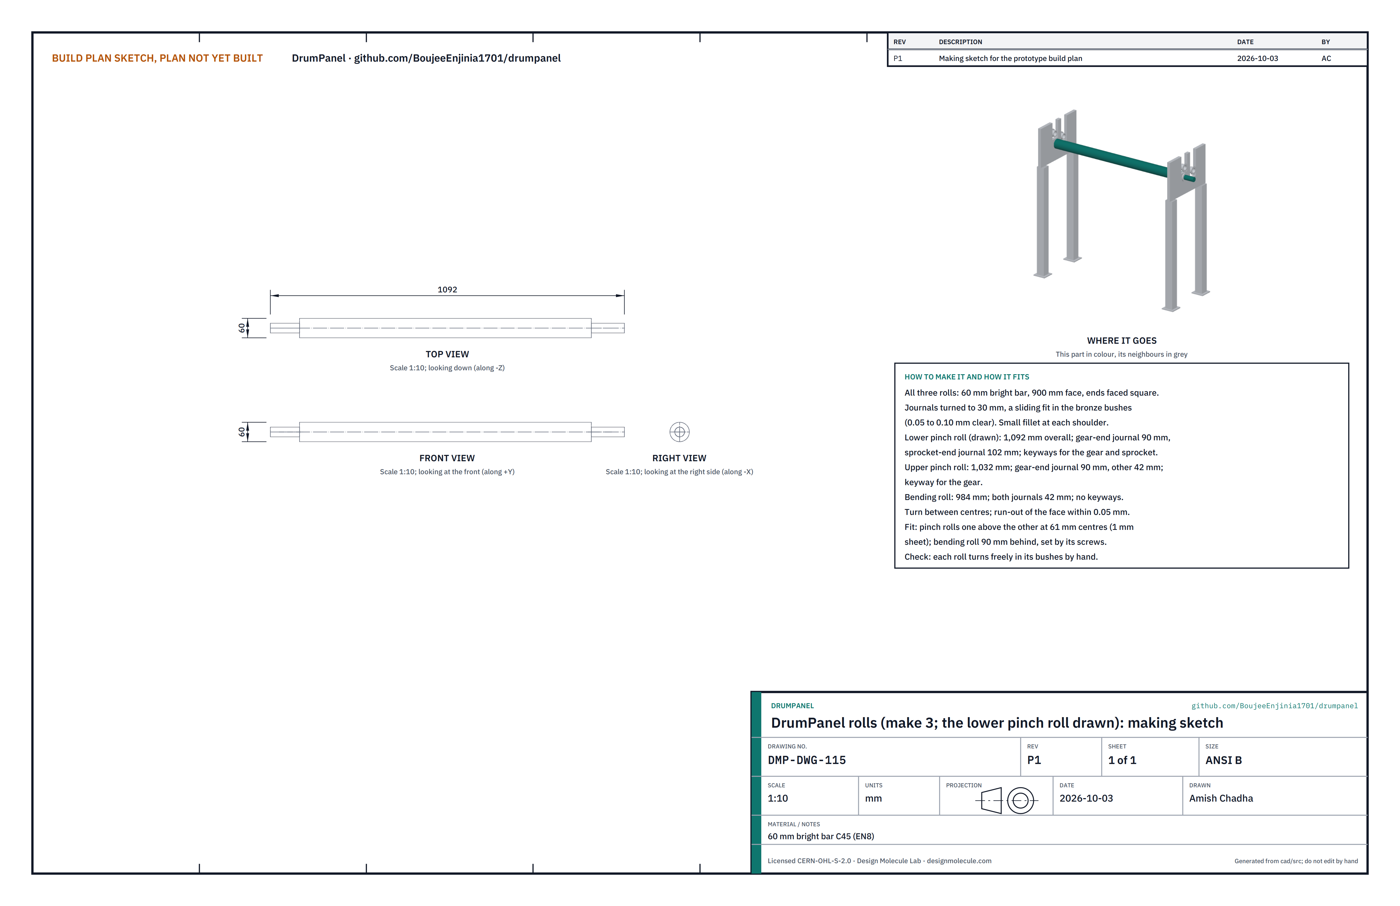
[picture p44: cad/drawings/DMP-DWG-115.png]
Figure 31. Making sketch of the lower pinch roll


*Figure 31. Rolls making sketch, lower pinch roll drawn (DMP-DWG-115).*

**What it is and what it is made from.** The lower and upper pinch rolls and the bending roll. 60 mm bright bar, C45 (EN8).

**How to make it.**

1. Cut and face the bars: lower roll 1,092 mm, upper roll 1,032 mm, bending roll 984 mm. Each has a 900 mm face.
2. Turn 30 mm journals, a sliding fit in the bronze bushes (0.05 to 0.10 mm clear), with a small fillet at each shoulder: lower roll 90 mm at the gear end and 102 mm at the sprocket end; upper roll 90 mm at the gear end and 42 mm at the other; bending roll 42 mm at each end.
3. Cut keyways for the gears (both pinch rolls) and the sprocket (lower roll).
4. Turn between centres; the face runs true within 0.05 mm.

**How it fits the parts next to it.**

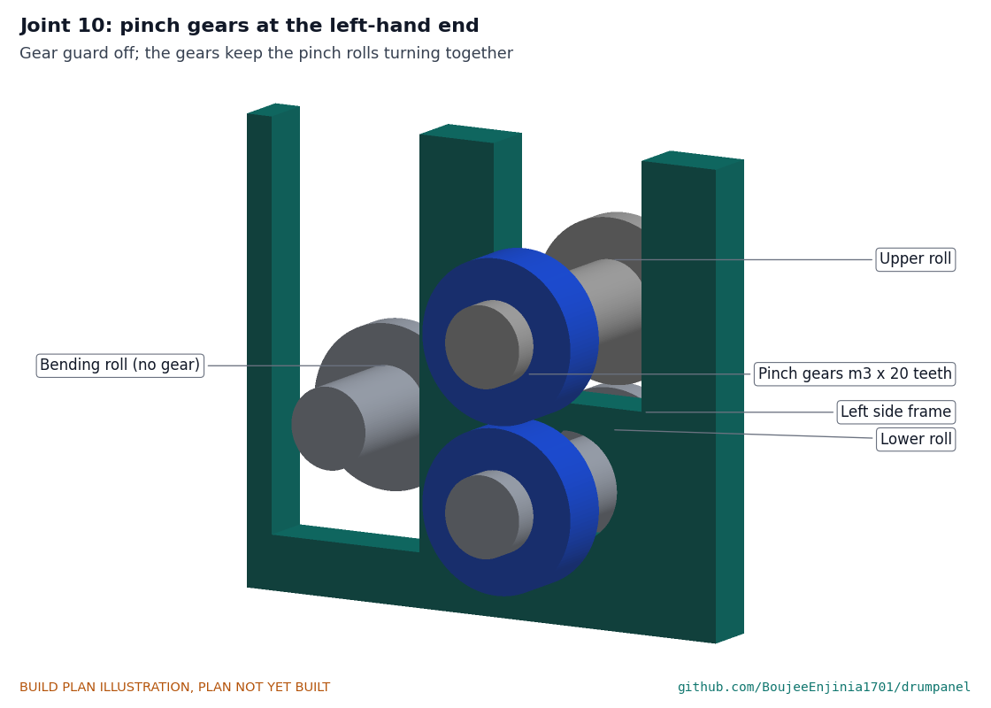
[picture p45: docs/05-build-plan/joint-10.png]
Figure 32. Joint 10: pinch gears


*Figure 32. Joint 10. The two pinch gears at the left-hand end keep the pinch rolls turning together; the bending roll has no gear.*

**Check before moving on.** Each roll turns freely in its bushes by hand.

### 3.19 Slide blocks, bushes and screws

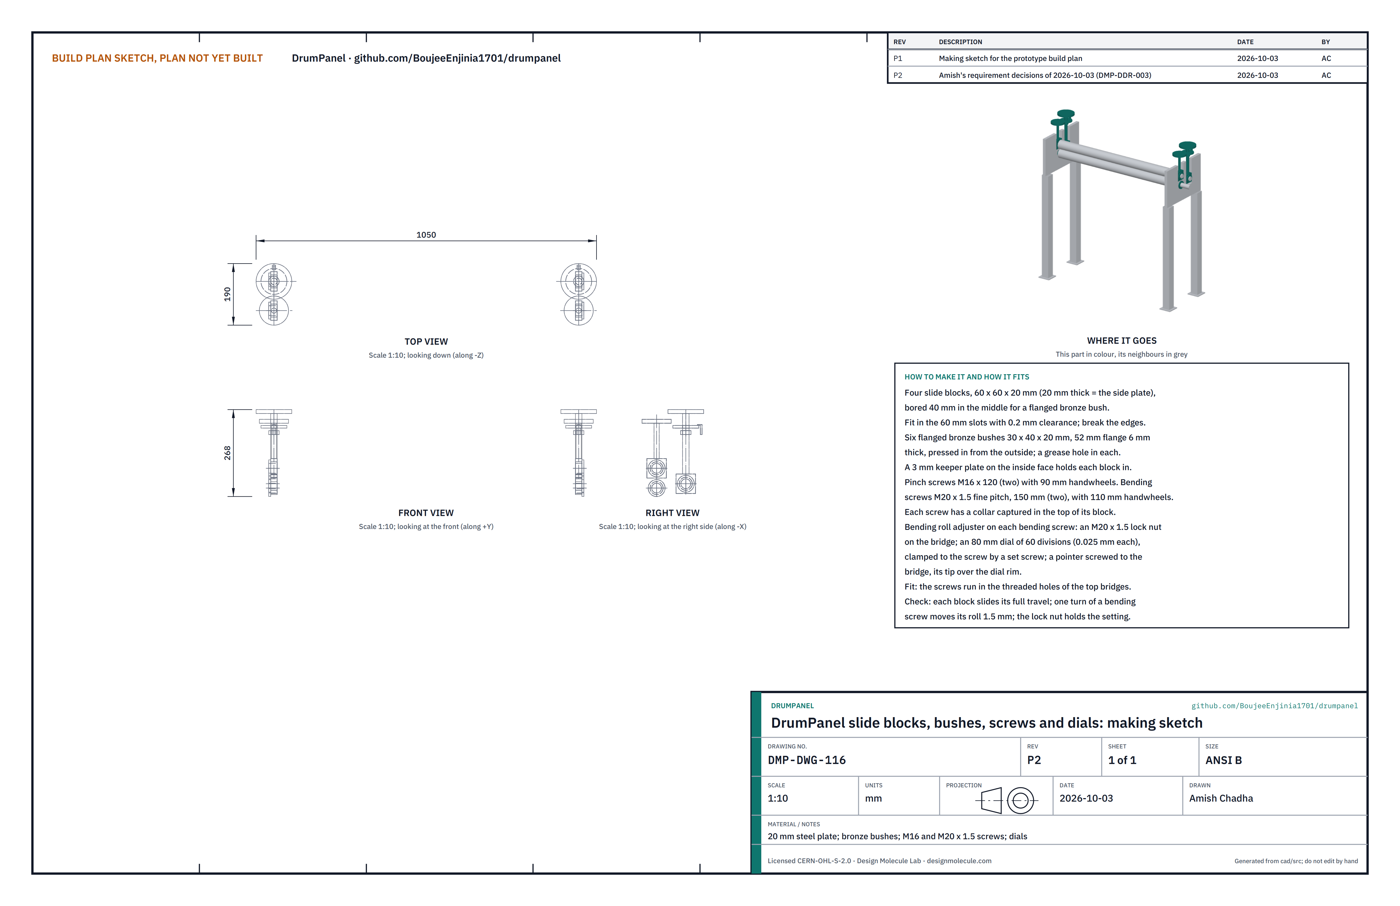
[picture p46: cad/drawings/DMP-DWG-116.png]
Figure 33. Making sketch of the slide blocks, bushes, screws and dials


*Figure 33. Slide blocks, bushes, screws and dials making sketch (DMP-DWG-116).*

**What it is and what it is made from.** Blocks that let the upper and bending rolls move up and down, the screws that move them, and the dials that set the bending roll. 20 mm plate; six bought flanged bronze bushes 30 x 40 x 20 mm; M16 screws and fine-pitch M20 x 1.5 screws; handwheels; two 80 mm dials, two M20 x 1.5 lock nuts and two pointers.

**How to make it.**

1. Cut four blocks 60 x 60 x 20 mm and bore each 40 mm in the middle. They should slide in the 60 mm slots with 0.2 mm clearance; break the edges.
2. Press a flanged bush into each block and into each lower bore from the outside; drill a grease hole in each.
3. Make a 3 mm keeper plate for the inside face of each block.
4. Fit a captive collar at the tip of each screw (two M16 x 120 pinch screws, two fine-pitch M20 x 1.5 x 150 bending screws) so it can push and pull its block. Fit 90 mm handwheels on the pinch screws and 110 mm handwheels on the bending screws. Tap the bending screw holes in the top bridges M20 x 1.5.
5. Turn two dials 80 mm across and 8 mm thick, bored 20 mm, with a set screw; engrave 60 divisions round the rim, every tenth numbered. Each division is 0.025 mm of bending roll movement.
6. Bend two pointers from 10 x 5 mm strip to stand on the bridge with their tips over the dial rims.

**How it fits the parts next to it.** The screws run in the threaded holes of the top bridges (Joint 9). On each bending screw, the lock nut runs down onto the bridge, the dial sits above it clamped to the screw, and the pointer is screwed to the bridge. To set the roll: slacken both lock nuts, turn both screws to the same dial reading, then tighten the lock nuts.

**Check before moving on.** Each block slides through its full travel when its screw is turned; one turn of a bending screw moves its roll 1.5 mm; with the lock nut tight, the dial reading does not change when the handwheel is pushed by hand.

### 3.20 Crank bracket, crank and chain drive

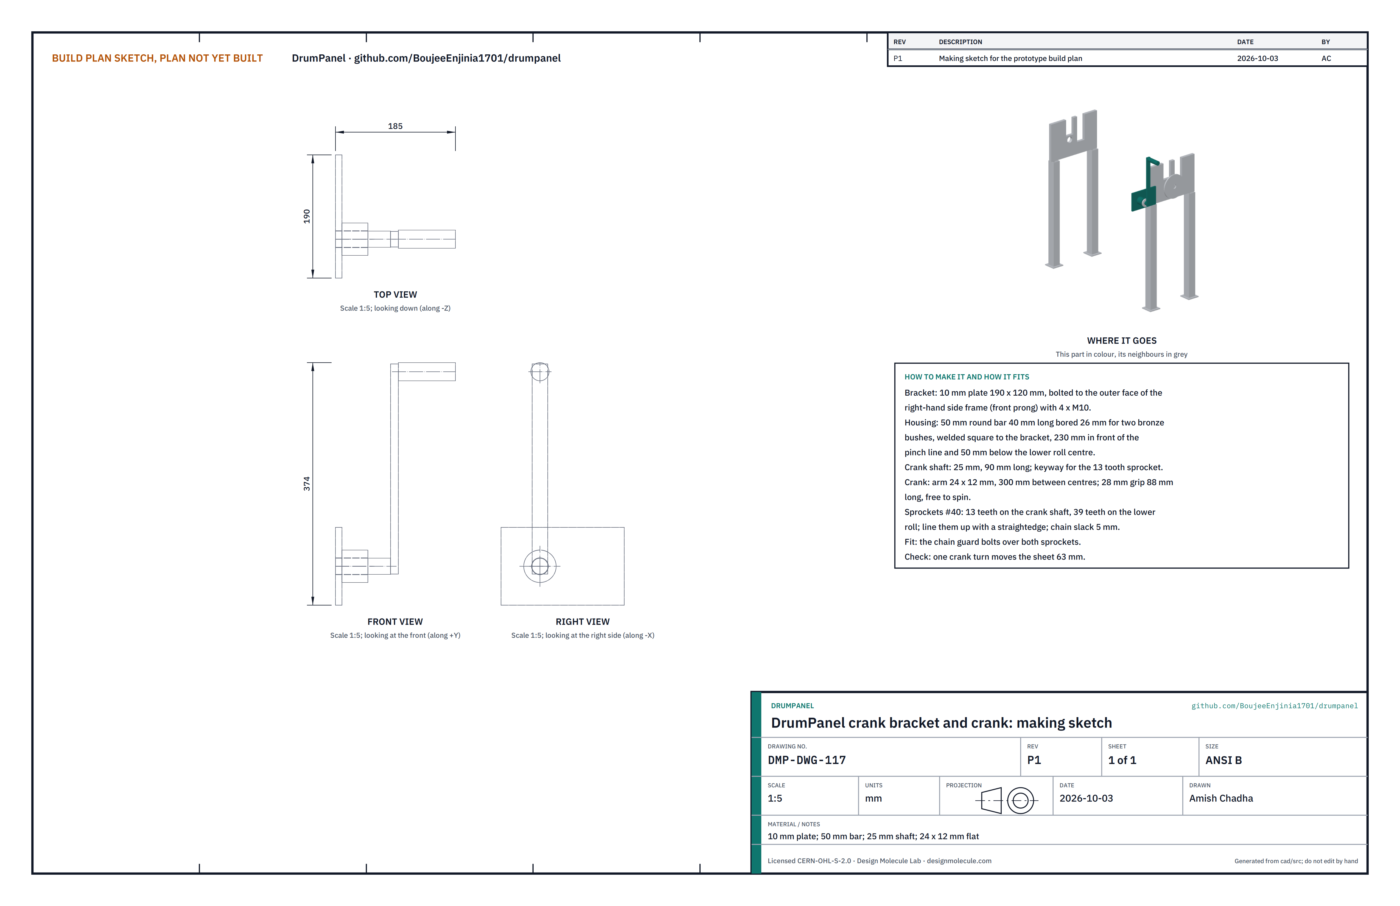
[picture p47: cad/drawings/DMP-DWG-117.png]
Figure 34. Making sketch of the crank bracket and crank


*Figure 34. Crank bracket and crank making sketch (DMP-DWG-117).*

**What it is and what it is made from.** The 300 mm crank and the 3:1 chain that drive the lower roll. 10 mm plate; 50 mm round bar; 25 mm shaft; 24 x 12 mm flat; bought #40 sprockets of 13 and 39 teeth and chain.

**How to make it.**

1. Cut the bracket 190 x 120 mm from 10 mm plate and drill four 11 mm holes to match the right-hand side frame's front prong.
2. Bore a 50 mm bar 40 mm long to 26 mm for two bronze bushes; weld it square to the bracket so the crank shaft sits 230 mm in front of the pinch line and 50 mm below the lower roll centre.
3. Cut the crank shaft 25 mm, 90 mm long, with a keyway for the 13 tooth sprocket. Make the crank: 24 x 12 mm arm, 300 mm between centres, with a 28 mm grip 88 mm long that spins freely.

**How it fits the parts next to it.**

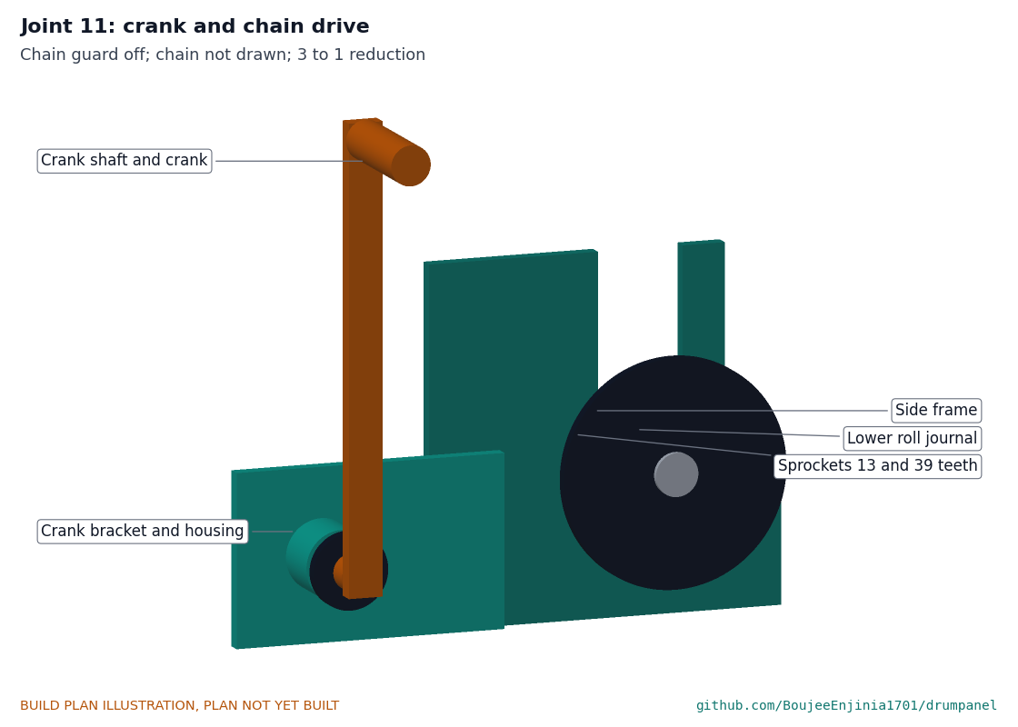
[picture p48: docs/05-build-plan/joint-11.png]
Figure 35. Joint 11: crank and chain drive


*Figure 35. Joint 11. The 13 tooth sprocket on the crank shaft drives the 39 tooth sprocket on the lower roll. Chain guard off and chain not drawn.*

**Check before moving on.** The sprockets line up under a straightedge; one crank turn moves a panel 63 mm.

### 3.21 Roll guards

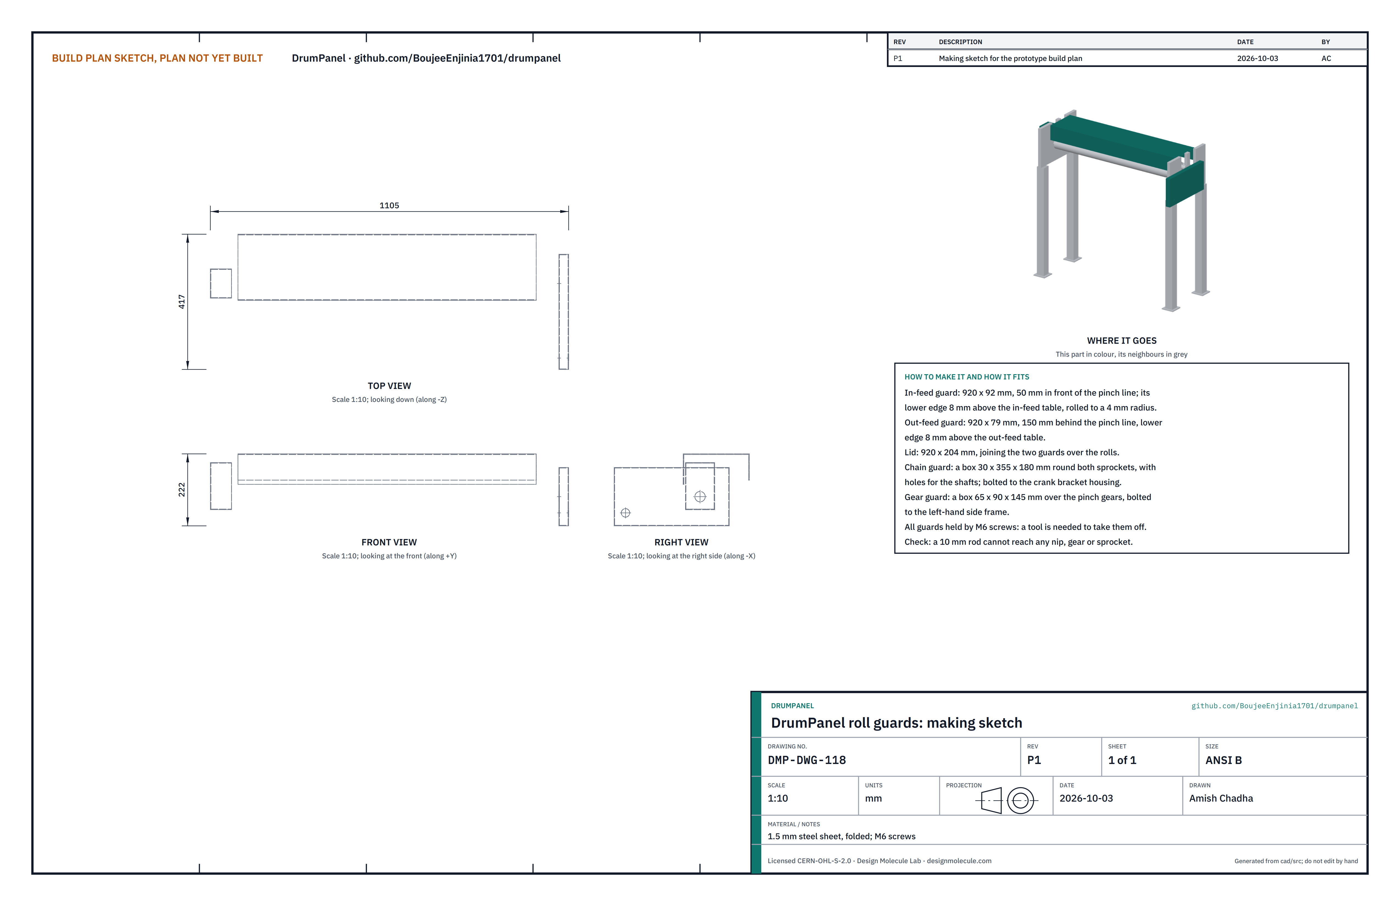
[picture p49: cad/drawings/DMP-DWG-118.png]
Figure 36. Making sketch of the roll guards


*Figure 36. Roll guards making sketch (DMP-DWG-118).*

**What it is and what it is made from.** Guards that keep fingers out of the roll nips, the gears and the chain. 1.5 mm steel sheet; M6 screws.

**How to make it.**

1. In-feed guard 920 x 92 mm, its lower edge rolled to a 4 mm radius; out-feed guard 920 x 79 mm; lid 920 x 204 mm joining them over the rolls.
2. Chain guard: a box 30 x 355 x 180 mm round both sprockets, with holes for the shafts.
3. Gear guard: a box 65 x 90 x 145 mm over the pinch gears.

**How it fits the parts next to it.**

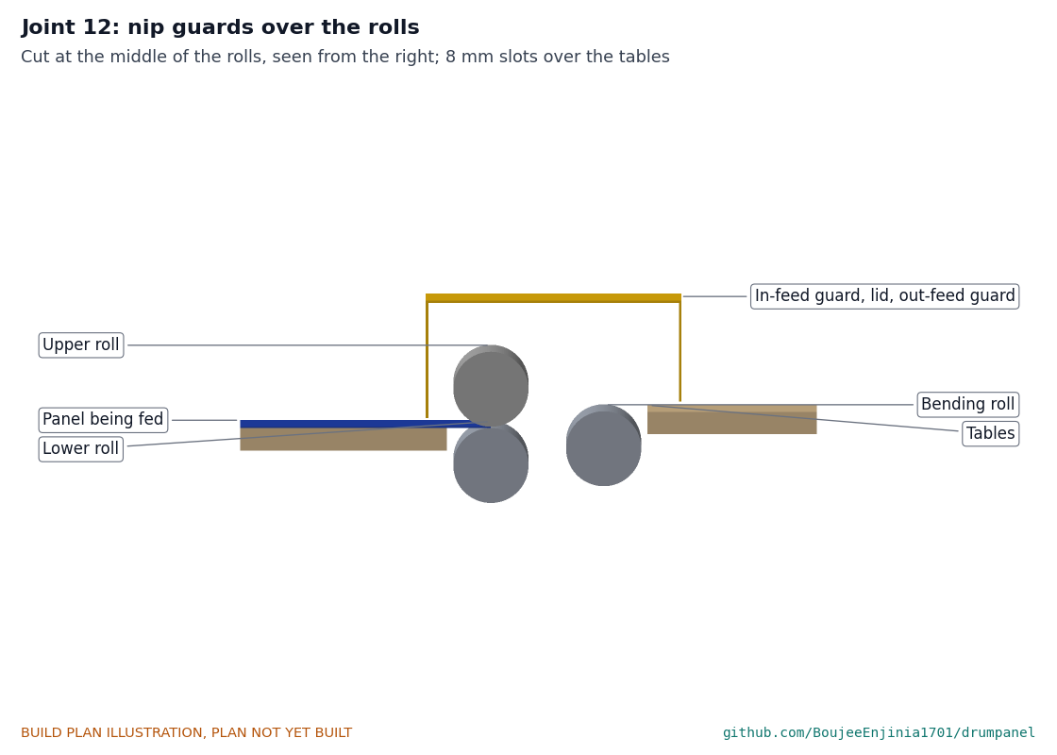
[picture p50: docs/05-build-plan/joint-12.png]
Figure 37. Joint 12: nip guards over the rolls


*Figure 37. Joint 12. The in-feed guard stands 50 mm in front of the pinch line with an 8 mm slot over the in-feed table; the out-feed guard 150 mm behind it with an 8 mm slot.*

All guards are held by M6 screws, so a tool is needed to remove them.

**Check before moving on.** A 10 mm rod cannot reach any nip, gear or sprocket.

### 3.22 In-feed and out-feed tables

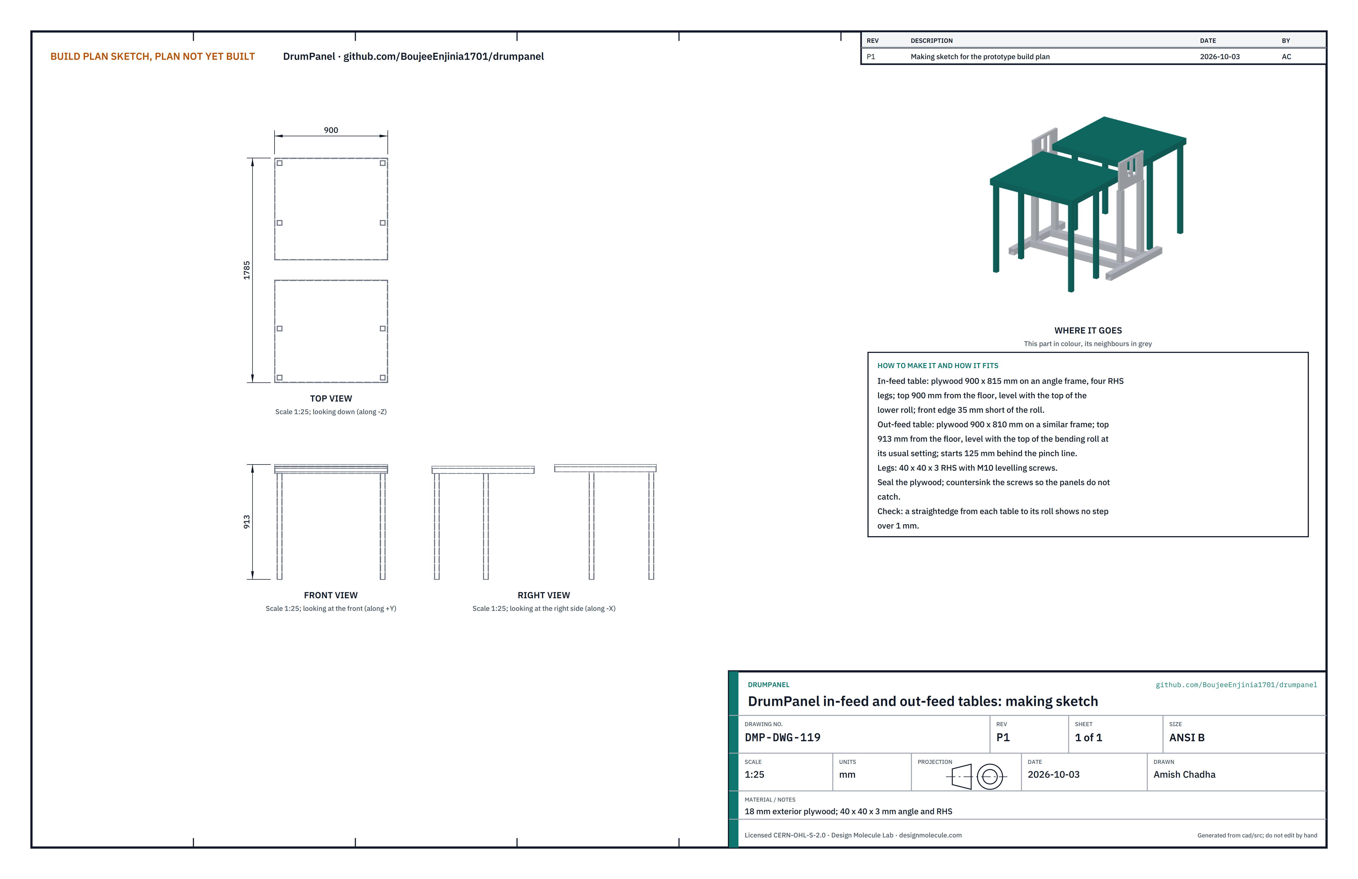
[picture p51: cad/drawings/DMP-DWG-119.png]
Figure 38. Making sketch of the tables


*Figure 38. Tables making sketch (DMP-DWG-119).*

**What it is and what it is made from.** Tables that carry the 1.8 m panels into and out of the rolls. 18 mm exterior plywood; 40 x 40 x 3 mm angle and tube.

**How to make it.**

1. In-feed table: plywood 900 x 815 mm on an angle frame with four tube legs; top 900 mm from the floor, level with the top of the lower roll, front edge 35 mm short of the roll.
2. Out-feed table: plywood 900 x 810 mm on a similar frame; top 913 mm from the floor; it starts 125 mm behind the pinch line.
3. Seal the plywood and countersink the screws so panels do not catch.

**How it fits the parts next to it.** Each table stands on its own legs with M10 levelling screws, butted up to the roll stand.

**Check before moving on.** A straightedge from each table to its roll shows no step over 1 mm.

### 3.23 Bought components

- **Drain tray:** HDPE oil drain tray about 600 x 500 x 150 mm.
- **Purge kit:** 15 m of 19 mm hose, 3/4 in bung hose adaptor, 2 in bung drain spout, a non-sparking (brass or bronze) bung wrench, a tap fitted to a spare drum as the settling drum, biodegradable detergent.
- **Vapour check kit:** a portable combustible gas detector with a catalytic bead or infrared LEL sensor, a sampling pump and a 1 m probe hose, its alarm settable at 5 % LEL (a 4-gas meter is fine), and 50 % LEL bump-test gas with a regulator. Read its manual; set the alarm before first use.
- **Pillow blocks:** four UCP205 (25 mm bore).
- **Slitting discs:** four D2 discs 101 x 10 mm, 25 mm bore, 58 to 60 HRC (two for the shear head, two for the ring head).
- **End cutter wheel:** one hardened wheel 50 x 6 mm, sold as a drum deheader or rotary cutter spare; bore it to suit the arm if needed.
- **Bearings and bushes:** four 6202-2RS (trolley), six 6005-2RS (shear head and ring head), four 6004-2RS (drive case), two needle thrust bearings to suit the punch screws, six flanged bronze bushes 30 x 40 x 20 mm and two 25 x 30 x 20 mm.
- **Gears and chains:** two spur gears module 3, 20 teeth, 20 mm face, bored 30 mm with keyway; #40 sprockets of 13 and 39 teeth and about 1.3 m of #40 chain (slip roll); #35 sprockets of 12, 28 and two of 15 teeth and about 1 m of #35 chain (shear head drive case).
- **Notching punch parts:** two Tr24 x 5 screws with bronze nuts; two D2 punch and die sets made and hardened by a tool shop to sketch DMP-DWG-121; a 500 mm ratchet lever with a socket to fit the screw heads.
- **Finishing tools:** a 10 mm steel plate 600 x 400 mm, a 1.5 kg dead-blow mallet, a swivel-blade deburring tool, flat and half-round files.
- **Procedure sheets and protective equipment:** laminated pictogram sheets; cut-resistant gloves (EN 388 level C or higher), safety glasses, ear defenders, leather aprons, nitrile gloves.

## 4. Putting it together

In each picture the parts already fitted are grey and the part being fitted is in colour, with an arrow showing the way it goes in. Two people for every lift over 25 kg.

### Step 1: drain stand chocks and tray

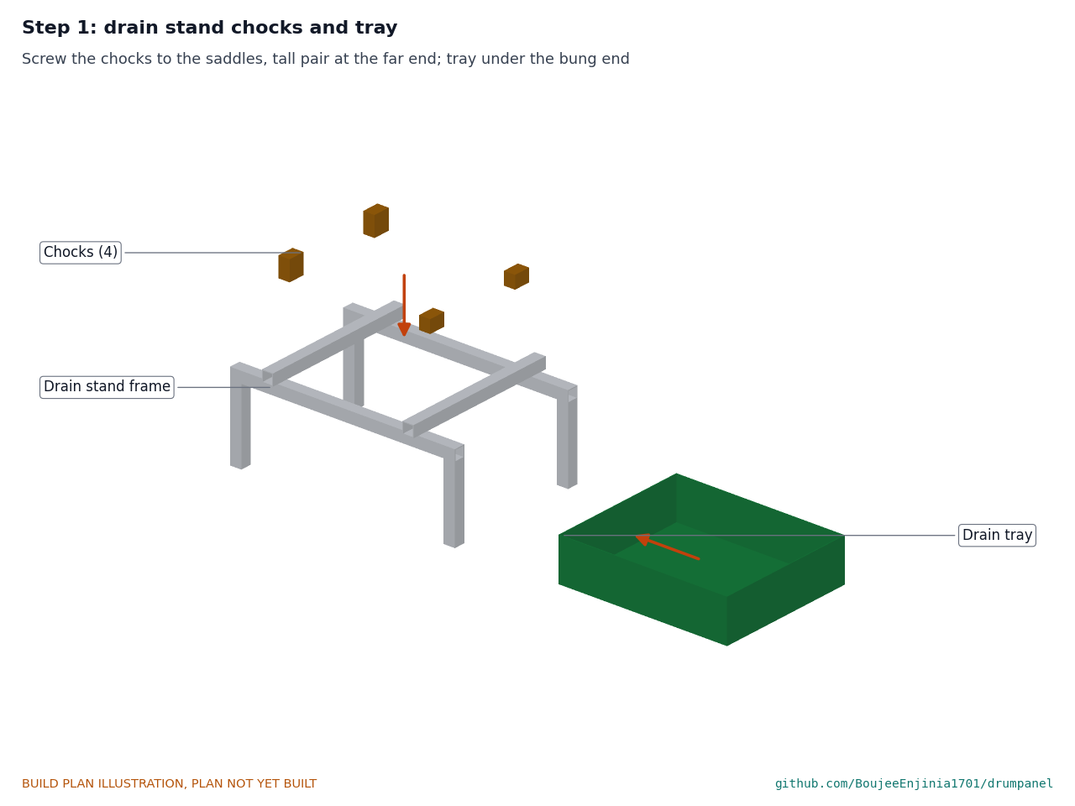
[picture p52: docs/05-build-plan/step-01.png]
Step 1


Screw the chocks to the saddles, the tall pair at the far end. Set the tray under the bung end. Place the stand on a drained floor away from the welding area.

### Step 2: cradle frame on its levelling feet

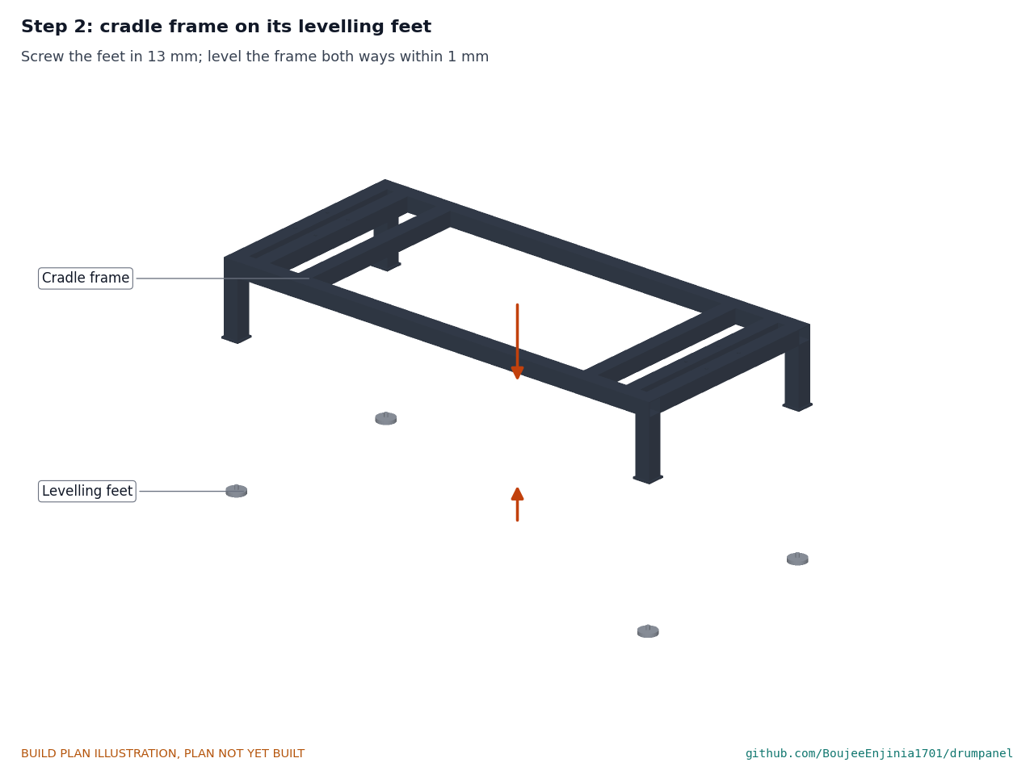
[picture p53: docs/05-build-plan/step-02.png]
Step 2


Two people: set the frame down, screw the four feet in about 13 mm, and level it both ways within 1 mm.

### Step 3: pillow blocks and roller shafts

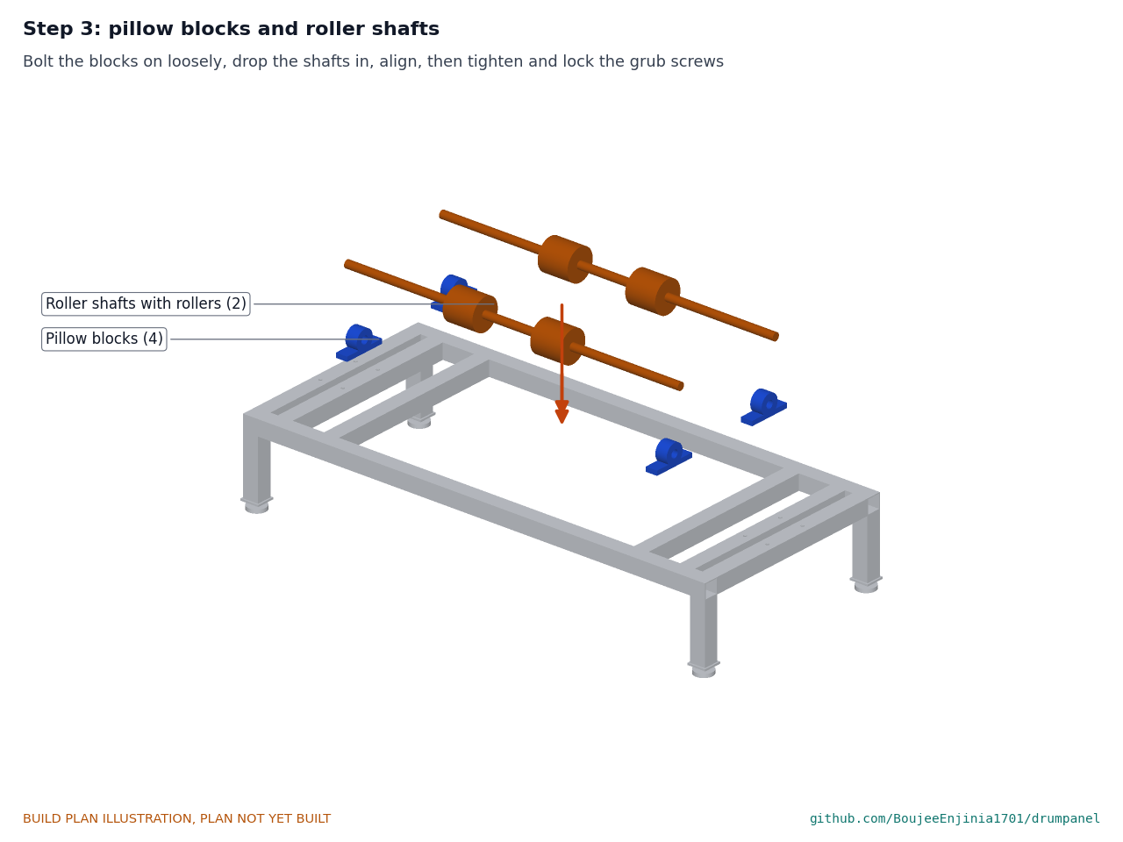
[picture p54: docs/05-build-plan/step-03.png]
Step 3


Bolt the four pillow blocks on loosely, drop the two shafts into them, line the shafts up parallel 380 mm apart, then tighten the bolts and lock the grub screws.

### Step 4: drum brake

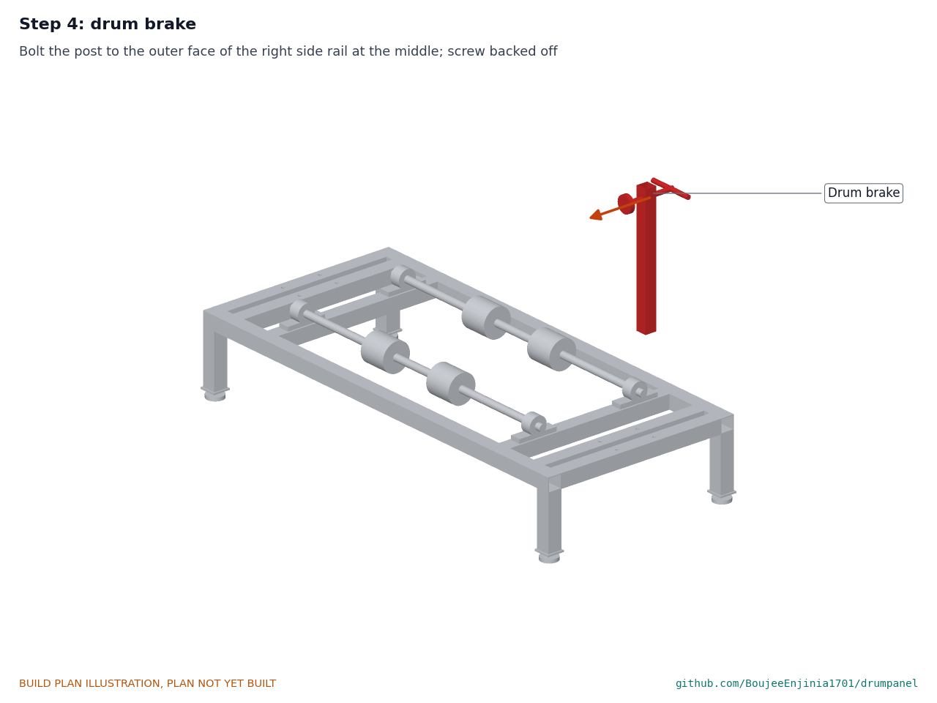
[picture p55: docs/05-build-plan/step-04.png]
Step 4


Bolt the brake post to the outer face of the right side rail at the middle with two M10 bolts. Back the screw off.

### Step 5: rail posts

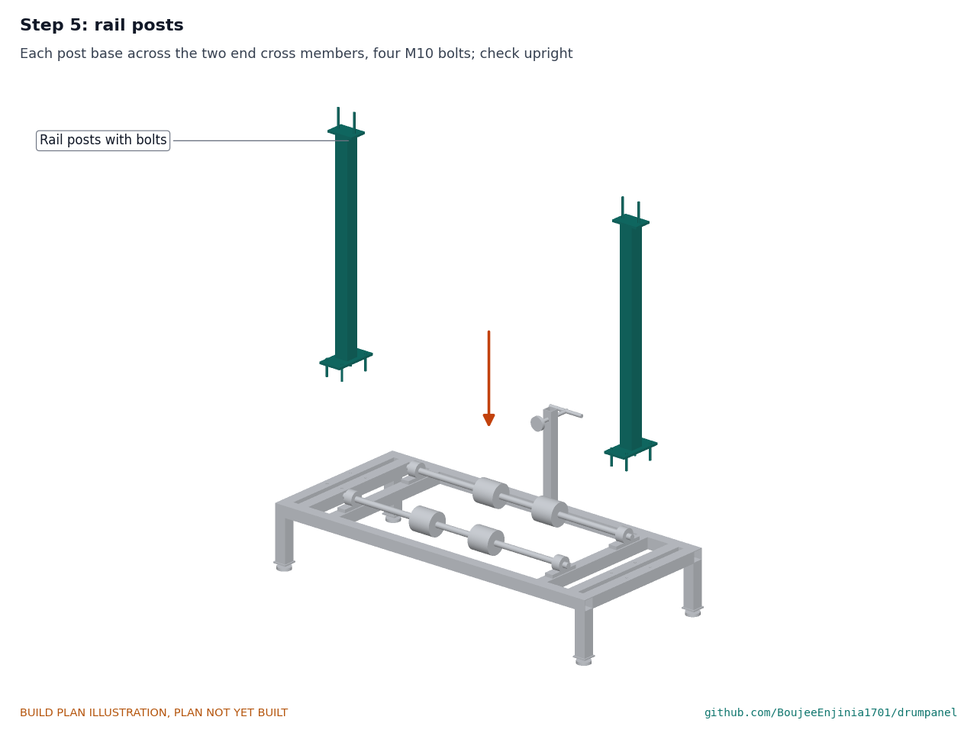
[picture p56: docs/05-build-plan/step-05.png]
Step 5


Stand each post with its base across the two end cross members and fit four M10 x 80 bolts. Check it upright before tightening.

### Step 6: rail beam and trolley

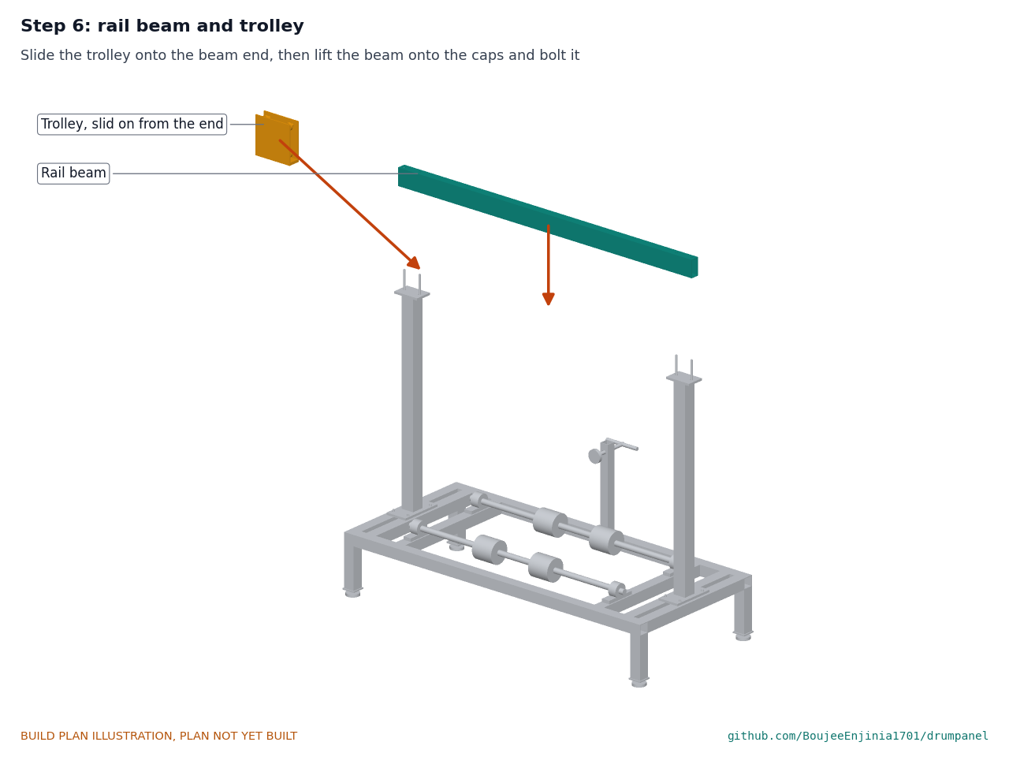
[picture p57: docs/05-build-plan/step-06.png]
Step 6


Slide the trolley onto one end of the beam with its lower wheels fitted. Two people: lift the beam onto the post caps and fit the four through-bolts with their crush tubes.

### Step 7: shear head onto the trolley

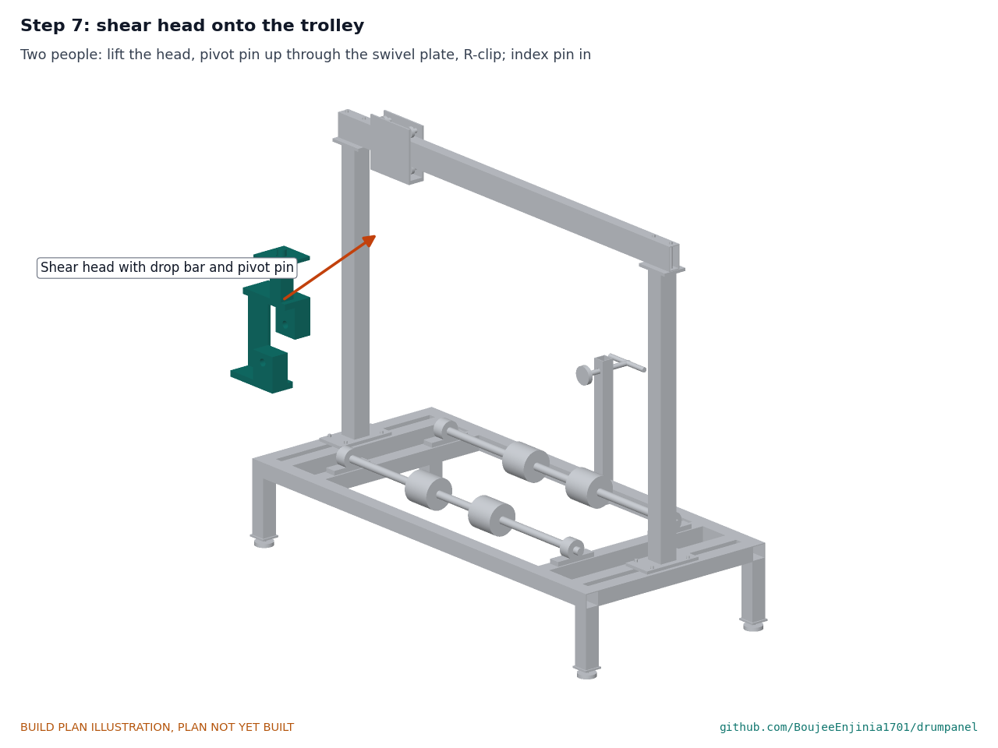
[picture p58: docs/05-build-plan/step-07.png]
Step 7


Two people: lift the head (about 20 kg with its drop bar), push the pivot pin up through the swivel plate and head plate, and fit the R-clip. Put the index pin in at the slit position.

### Step 8: shafts, discs, guard and drive case

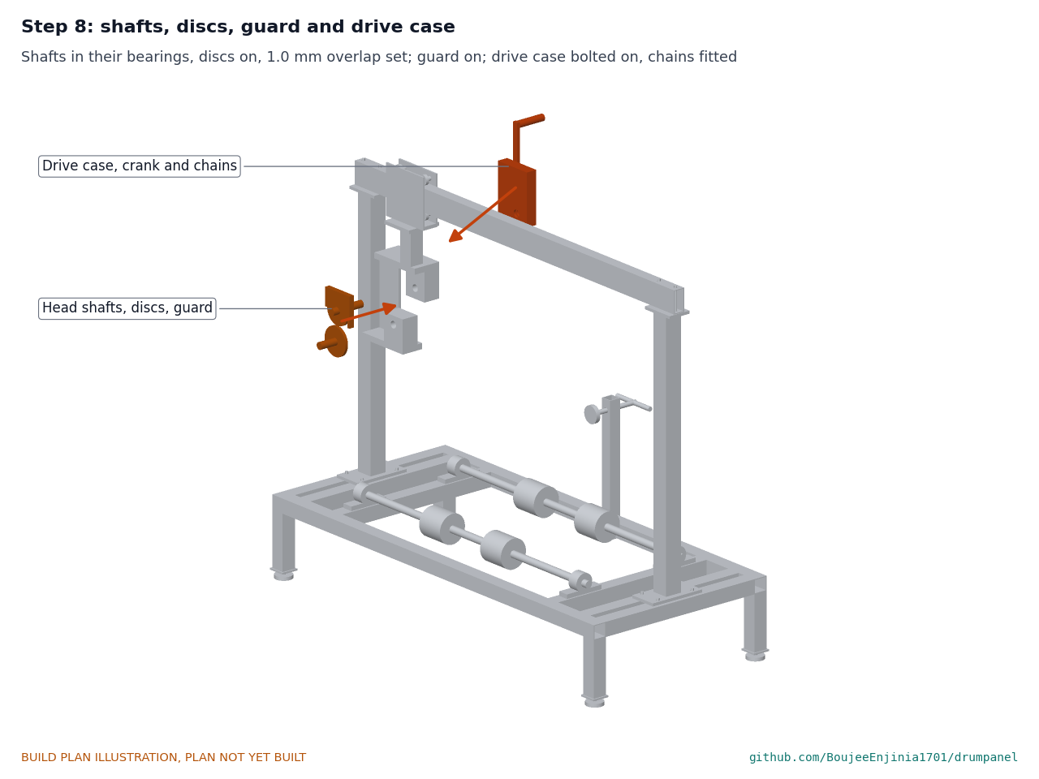
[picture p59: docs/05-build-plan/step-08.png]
Step 8


Fit the bearings, the eccentric bush and the shafts; clamp the discs on; set the 1.0 mm overlap with the eccentric and lock it. Fit the disc guard. Bolt the drive case's inner plate to the head with its four M8 screws, fit the jackshaft, the crank shaft, the sprockets and both chains, then close the case with its band and outer plate before the crank is ever turned.

### Step 9: end cutter on a drum

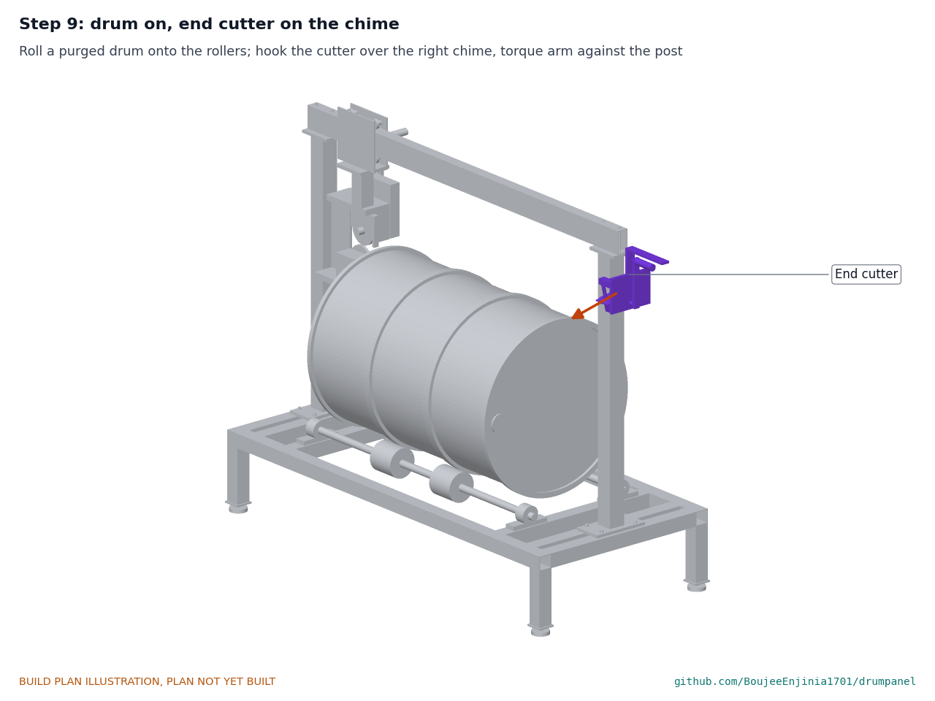
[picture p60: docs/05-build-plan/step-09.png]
Step 9


Only after safety stop S4: roll a purged and checked drum onto the rollers. Hook the end cutter over the right-hand chime, set the clamp screw, and rest the torque arm against the post. Set the drum top under the head by the levelling feet so the discs nip the wall.

### Step 10: tool shelf, notching punch and ring head

Step 10

Bolt the shelf to the outer face of the left post with its two M10 through-bolts. Set the notching punch and its lever on it, and the ring head with its spacer plate and coupling bolted on. In use, the ring head is lowered through the slit and bolted to the main head once the main head is swivelled for the ring cuts (Figure 26); two people, one steadying it while the other fits the bolts.

### Step 11: roll stand base

Step 11

Set the base where panels can be fed in from the front and taken off at the back; level it.

### Step 12: side frames on the lower roll

Step 12

Fit the bushes on the lower roll's journals. Two people: offer both side frames onto the bushes, stand them on the base, and bolt each foot with two M12 bolts.

### Step 13: upper and bending rolls into the slots

Step 13

Fit the slide blocks and bushes on each roll's journals and lower the roll down its pair of slots. Fit the keeper plates on the inside faces.

### Step 14: top bridges, screws and dials

Step 14

Bolt the bridges across the slot tops and run the screws down until their collars engage the blocks. Set the pinch with a strip of 1 mm sheet between the pinch rolls. On each bending screw, run the lock nut down to the bridge, clamp the dial above it, and screw the pointer to the bridge. Set both bending screws to the same dial reading at the nominal height, 13.4 mm above the lower roll, and lock them.

### Step 15: pinch gears

Step 15

Key both gears on at the left-hand end and set their mesh with the 1 mm strip in the pinch.

### Step 16: crank, sprockets and chain

Step 16

Bolt the crank bracket to the right-hand side frame, key the sprockets on, line them up, and fit the chain with about 5 mm of slack.

### Step 17: guards

Step 17

Screw on the nip guards, lid, chain guard and gear guard. Check the 8 mm slots over the tables.

### Step 18: in-feed and out-feed tables

Step 18

Stand the tables at the front and back, tops level with the rolls, and fix the legs.

## 5. First checks

These are the checks a TRL 4 test report would record; this plan only lists them. Requirement numbers are those of DMP-REQ-001. None involves cutting a drum until S4 and S5 are passed.

*Table 2. First checks.*

| Check | Requirement | How | Pass when |
| --- | --- | --- | --- |
| Gas detector | R2 | Bump test with 50 % LEL gas; alarm set at 5 % LEL | Alarm sounds; reading within the maker's limits |
| Purge and check | R1, R2 | One accepted drum through fill, soak, drain and check | Reading below 5 % LEL at both bungs; no flame or heat used |
| Drain stand | R11 | Fill a drum on the stand; look for movement | The stand does not move or rock with a full drum |
| Heads off | R3, R6 | Time both heads off one drum; spring scale on the crank | Under 10 min; crank force 150 N or less |
| Notches | R6 | Punch the two chime notches and the two hoop slots on the same drum; spring scale on the punch lever | Clean notches, the shear head passes them; lever force 150 N or less |
| Slit | R4, R6 | Slit a purged drum; measure the cut line against a straight line | Deviation 5 mm or less; crank force 150 N or less; the crank turns without touching the drum |
| Ring and hoop cuts | R6, R12 | Three passes with the ring head bolted on; spring scale on the crank | Three panels about 233 x 1,800 mm; crank force 150 N or less |
| Trial setting | R5 | First panel of the batch through the slip roll, adjusting the bending roll by its dials | Flat within 10 mm over 1 m after the passes; the dial reading and the number of passes recorded; a second drum set to that reading comes out flat |
| Slip roll effort | R6 | Spring scale on the crank with three panels | 150 N or less |
| Guards | R10 | A competent person checks every guard opening against ISO 13857 as built | Every opening meets the standard |
| Throughput | R7 | Half-day trial by two people, each task timed | Drums per hour recorded against the estimate of 2.26 and the target of 2.5; this trial decides R7 (DMP-DDR-004) |
| Parts cost | R9 | Sum the receipts | Recorded against the value-engineering target |

## 6. Safety stops

Stop at each point. Carry on only when everything listed is true.

- **S1. Before any making.** No drum anywhere near the workshop; welding area ventilated; fire extinguisher at hand; welding helmet, leather gloves and apron, safety glasses and hearing protection in use.
- **S2. Before any lift over 25 kg** (cradle frame 34 kg). Two people, clear floor.
- **S3. Before a drum is accepted.** Its label shows a non-volatile oil (flash point above 60 °C). Otherwise it is rejected and goes back to the supplier.
- **S4. Before a drum goes onto the cradle.** It has been purged and has passed the vapour check below 5 % LEL at both bungs that day, with a bump-tested detector. No grinder, torch or welder is used on it at any time.
- **S5. Before any crank is turned.** Every guard is fitted, the shear head's drive case closed; one person on the crank; nobody else's hands near the discs, the end cutter or the rolls; cut-resistant gloves and safety glasses on.
- **S6. Before the drum is slit.** The brake is on and the index pin is in at the slit position; the four notches are punched and the notching punch is back on its shelf.
- **S7. Before the ring cuts.** The brake is off, the head is swivelled and the index pin is in at the ring position; the ring head is bolted on with all four spacer plate bolts tight and the coupling in its guard sleeve.
- **S8. Before panels are handled or stacked.** Every cut edge is deburred.
- **S9. Purge water.** Settled and skimmed; oil kept in a closed container for a recycler; nothing poured on the ground.
- **S10. While notching.** Hands only on the ratchet lever; nobody holds the drum or the punch near the jaws while the screw is turned.

## 7. Tools, skills and workspace

**Tools.** Metal bandsaw or abrasive chop saw; angle grinder with cut-off and flap discs (never on a drum); pillar drill to 31 mm with drills 5 to 31 mm and a 57 mm hole saw or boring bar; stick welder of about 160 A for 3.2 mm E6013; welding table, clamps and magnetic squares; a lathe with at least 1.1 m between centres for the rolls and shafts (or a machine shop); taps M5 to M20 and M20 x 1.5; spanners and a torque wrench; tape, steel rule, callipers, engineer's square, spirit level, straightedge 1 m, feeler gauges.

**Skills.** A competent stick welder for the frames, posts and shear heads; a lathe operator for the rolls, shafts, bushes and dials; a tool shop for the punches and dies and their hardening; ordinary shop skill for the rest. A person trained to use and bump-test the gas detector.

**Workspace.** A covered, level concrete floor about 5 x 4 m for the three stations; a separate ventilated welding and grinding area with no drums in it; a drained spot for the drain stand with room for the settling drum.

**Personal protective equipment.** Welding helmet, leather gloves and apron; safety glasses for all cutting, drilling and grinding; hearing protection; safety boots for lifts; cut-resistant gloves for any work with cut drum steel; nitrile gloves for drum residue.

## 8. Where the numbers come from

- Model and constructability checks: `cad/src/model.py` (`python cad/src/model.py --check`); STEP and STL exports in `cad/step/` and `cad/stl/`.
- Pictures: `cad/src/build_plan_media.py`, using `.kit/build_views.py`; written to `docs/05-build-plan/` and `cad/drawings/DMP-DWG-101` to `DMP-DWG-123`.
- General arrangement: `cad/drawings/DMP-DWG-001.pdf`, Rev P2.
- Calculations: `docs/04-calcs/01-sizing.md` (DMP-CAL-001 v0.2) and `docs/04-calcs/sizing.py`.
- Bill of materials: `bom/bom.csv`.
- Decisions: `docs/decisions/0001-trl2-review-decisions.md` (DMP-DDR-001), `docs/decisions/0002-design-for-construction.md` (DMP-DDR-002) and `docs/decisions/0003-requirement-decisions-2026-10-03.md` (DMP-DDR-003).
- Requirements: `docs/03-requirements.md` (DMP-REQ-001 v0.4).
- Design decisions register: `docs/06-design-decisions.md` (DMP-DEC-001 v0.2).

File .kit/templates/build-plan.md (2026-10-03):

---
doc_id: PRJ-BLD-001
title: Project prototype build plan
project: Project name
doc_type: Build plan
version: "0.1"
status: Draft
date: YYYY-MM-DD
author: Amish Chadha
license: CERN-OHL-S-2.0
revisions:
  - version: "0.1"
    date: YYYY-MM-DD
    author: Amish Chadha
    change: First build plan; design made constructable
---

# Project prototype build plan

**Plan, not yet built.** How to build the first proof-of-concept prototype, component by component. Building and testing to it is TRL 4 work. Decisions still to be made are kept in the design decisions register (`docs/06-design-decisions.md`), not here.

## 1. What you are building

Every component, pulled apart and numbered in build order

One short paragraph: what the prototype is, how many components, which are made and which are bought, and the main ways they are made.

## 2. What changed to make it buildable

| Component | The concept had | The buildable design has | Why |
| --- | --- | --- | --- |

## 3. Making the components

### 3.1 Component name

Making sketch

**What it is and what it is made from.**

**How to make it.**

1. Mark out ...
2. Cut ...

**How it fits the parts next to it.**

Close-up of the joint

**Check before moving on.**

## 4. Putting it together

### Step 1: ...

Step 1

## 5. First checks

| Check | Requirement | How | Pass when |
| --- | --- | --- | --- |

## 6. Safety stops

## 7. Tools, skills and workspace

## 8. Where the numbers come from

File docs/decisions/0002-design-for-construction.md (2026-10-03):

---
doc_id: DMP-DDR-002
title: DrumPanel design for construction
project: DrumPanel
doc_type: Design decision record
version: "0.1"
status: Draft
date: '2026-10-03'
author: Amish Chadha
license: CERN-OHL-S-2.0
revisions:
- version: "0.1"
  date: '2026-10-03'
  author: Amish Chadha
  change: Changes that make the concept physically buildable, with the reason for each, decided under Amish's pre-approval of 2026-10-03
---

# 0002: Design for construction

- **Date:** 2026-10-03
- **Status:** accepted. Decided by Amish under his pre-approval of 2026-10-03: "start with the first 14 repos from the list of 29 projects. I pre-approve the batch runs along with any recommendations you come up with. I also accept any cost overruns or variations from the assumed scope cost."

## Context

STANDARDS section 18 asks for the design to be made constructable as the build plan is drawn (Amish, 2026-09-30: "fix the design assumptions to match and be physically feasible"). The TRL 2 concept listed eight components in words only. Drawing every part in `cad/src/model.py`, checking it with build123d, and sizing it in DMP-CAL-001 found the problems below. Every change keeps what DrumPanel does (purge, check, cold cut and roll flat, by hand) and its pitch. P7 changes the output from one sheet to three panels per drum; it is recorded here because the one-sheet output cannot be made, and the safety case is unchanged.

The model now runs its own checks with `python cad/src/model.py --check`: no two of the 42 components overlap, the 49 joints that must touch do touch, the shear head clears the drum at all six ring cut positions and at seven stations along the slit, and its parked position clears the posts and the drum. All pass.

## Decision

*Table 1. Changes made to the model, the BOM and the calculations.*

| # | Problem in the concept | Change made | Why this way |
| --- | --- | --- | --- |
| P1 | A tilting drain stand: a drum full of water (about 240 kg) would have to be tipped | A fixed stand sloping 2.9 degrees to the bung end; the drum is filled and drained in place, never lifted full | Simpler and safer; drains to within 1.4 L (DMP-CAL-001, section 2) |
| P2 | "Cradle and clamps" did not say what the drum sits on or how it is held | Four rollers under the rolling hoops, 380 mm apart, so the drum turns; a screw brake with a rubber pad holds it still | The hoops are the stiffest part of the body; the drum must both turn (ring cuts) and stay still (slit) |
| P3 | The end cutter was to remove each end; a hand wheel cannot cut through the five-layer chime seam | The end cutter cuts the head out just inside the chime; the chime ring stays on the body and is cut off later with the shear head | The head plate is single thickness; the chime's inside wall acts as the die |
| P4 | A "lever or crank-driven slitting tool" with nothing to guide it or react its force | A rotary shear head on a trolley running on an overhead rail between two posts; the upper disc is driven, the lower idles inside the drum, and a 10 mm web in the cut joins them | A gear between the discs would have to pass through the drum wall; the rail keeps the slit straight (R4) |
| P5 | No way to start a cut through the chime rings and hoops | A 40 mm hacksaw notch through each chime ring and each hoop on the slit line before slitting | The discs cannot shear a folded seam or a 12 mm ridge |
| P6 | A three-roll pyramid cannot drive the sheet by friction alone | A slip roll: pinch pair geared 1:1 and pressed together with 2 kN by two M16 screws, bending roll 90 mm behind on two M20 screws | Traction comes from the pinch, bending from the bending roll; crank 20 N (DMP-CAL-001, section 5) |
| P7 | The concept rolled the whole body flat; rolling a hoop flat would stretch its crown about 8.5 % | The shear head also cuts 30 mm each side of each hoop; the body gives three panels about 233 x 1,800 mm and two hoop strips | Only flat panels go through the rolls; matches the three sheets per drum the craft already expects |
| P8 | Rings and hoops cut with a separate tool | The shear head swivels 90 degrees on its pivot (index pin, two positions) for the six ring cuts while the crank turns the drum on its rollers | One tool, already on the rail |
| P9 | No guards drawn | Disc guard with a front skirt 8 mm over the sheet; slip roll nip guards with 8 mm slots, lid, chain and gear guards; a cover over the end cutter wheel; all need a tool to remove | ISO 13857 slot distances met on paper (DMP-CAL-001, section 7); safety additions take the conservative option |
| P10 | Panel ends that no slip roll can bend | The last 90 mm of each panel end is set by hand on a 10 mm bench plate with a dead-blow mallet | A slip roll cannot bend between its pinch line and its bending roll |
| P11 | Lower roll cannot be fitted between two welded side frames | Side frames bolted to the base; the lower roll's bushes go on first, then the frames; upper and bending rolls drop down open slots closed by bolted top bridges | An assembly order that works |
| P12 | Rail posts too close to the drum ends for the end cutter and the parked head | Posts at 712.5 mm each side of the middle, on bases across two cross members; frame 1,550 mm long | Room for the end cutter, its torque arm and the head's lower jaw |
| P13 | Shear head reaction when cutting heads | A torque arm from the end cutter rests against a rail post | The drum turns; the cutter must not |
| P14 | Drum height under the rail fixed | The cradle's levelling feet set the drum top under the shear head; no height adjustment in the drop bar | Fewer parts; drums vary by a few millimetres |

## Consequences

- Cost: the estimated cost of the constructable design is USD 2,794 against the USD 3,000 value-engineering target (USD 206 under).
- R7 (four drums an hour) is not met: the notches and six ring cuts make the cradle the bottleneck at about 2.0 drums an hour.
- R5 (flatness) depends on finding the bending roll setting by trial for each batch of drum steel.
- The drawings DMP-DWG-001 and DMP-DWG-101 to 119, the concept media and the build plan DMP-BLD-001 are drawn from the changed model.

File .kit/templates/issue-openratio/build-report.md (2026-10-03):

---
name: Build report
about: Tell us what happened when you built, printed or tested part of this design
title: "Build report: "
labels: build-report
---

This is a research and educational prototype, not a medical device. It is a TRL 3 concept and is not released for fabrication. If you build any part of it, you do so at your own risk. Reports help everyone.

**What you built** (part, sub-assembly or test)

**Materials, tools and settings**

**What worked**

**What did not work, with photos or measurements if you have them**

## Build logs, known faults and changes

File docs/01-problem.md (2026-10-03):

---
doc_id: DMP-PRB-001
title: DrumPanel problem statement
project: DrumPanel
doc_type: Problem statement
version: "0.3"
status: Draft
date: '2026-10-03'
author: Amish Chadha
license: CERN-OHL-S-2.0
revisions:
- version: "0.1"
  date: '2026-09-30'
  author: Amish Chadha
  change: Initial scaffold
- version: "0.2"
  date: '2026-10-03'
  author: Amish Chadha
  change: TRL 2 update; drum facts, constraints and acceptance rule for drum contents added; first co-design candidate named
- version: "0.3"
  date: '2026-10-03'
  author: Amish Chadha
  change: TRL 3 update; budget worded as a value-engineering target; open questions answered by the decisions of 2026-10-03 (DMP-DDR-001, DMP-DDR-002)
---

# DrumPanel problem statement

The first step in drum-based metal art, opening a drum into flat sheet, is still done by fire, chisel and body weight.

## The problem

Accounts from Croix-des-Bouquets describe the same sequence: ends removed with chisel and hammer, the drum filled with dried leaves or cane and set on fire, the side split, and the body flattened by people climbing inside and pounding it down ([SFO Museum](https://www.sfomuseum.org/exhibitions/haitian-metal-sculpture); [Roots of Development](https://store.rootsofdevelopment.org/wp-content/uploads/2023/12/About-Haitian-Metal-Art.pdf)). It is apprentices who usually do this stage ([Global Exchange](https://globalexchange.org/tag/haiti-oil-drum-art/)). The fire is there to remove paint and residue; DrumPanel treats the smoke from burning unknown residues, and the noise of chisel work, as the things to design out.

In the preliminary IP screen the closest alternatives were powered drum cutter-flatteners and an expired US patent for a drum-head cutter (US3161952A). The screen found no simple, open, hand-powered bench set that combines a purge, a vapour check, cold cutting of the ends and seam, and rolling flat. The gap is a documented manual method that a workshop can build and trust.

## Users and context

| User | Need | Context |
| --- | --- | --- |
| Metal artists and their apprentices | Flat, clean sheet from drums with less smoke, noise and effort | Small family workshops such as those in Croix-des-Bouquets |
| Local fabricators | Drawings for a bench set they can build from commodity steel | Towns with a welder and a lathe but no sheet metal machinery |
| Artisan cooperatives and fair trade buyers | A safer, repeatable preparation step they can fund and document | Export supply chains |
| Drum collectors and recyclers | A way to open drums that cannot be reused whole without burning them | Port and industrial areas |

## Operating environment

- Open-sided workshops or yards, hot and humid, often with no reliable mains power.
- Drums of 55 US gallon (about 208 L) steel, previously holding oils or unknown contents. A tight-head drum is about 572 mm inside diameter and 880 mm long over its rolled end seams (chimes), with two rolling hoops pressed out of the body and two screw bungs (50 mm and 20 mm) in one head. The body wall is usually 0.8 to 1.2 mm and the heads 1.0 to 1.5 mm.
- Workers standing at a bench; dust, rain and salt air near the coast.
- Water from a tap, a tank or a hose is available most days; electricity is not assumed.

## Constraints

- Value-engineering target: USD 3,000 in parts for the full bench set (a hypothetical control target that keeps the design lean, not a spending limit).
- Manual operation only: hand cranks, levers and clamps, no motors.
- No flame, no grinding and no power tools on a drum until it has been purged and has passed the vapour check.
- Only drums whose label shows they held a non-volatile oil (lubricating, hydraulic or vegetable oil, flash point above 60 °C) are accepted. Drums that held fuel, solvent, chemicals or anything unknown, or that have no readable label, are rejected and returned to the supplier.
- Buildable by a local fabricator from commodity steel, bearings and fasteners; hardware under CERN-OHL-S-2.0.
- Purge and vapour check must be simple enough to follow from a printed pictogram sheet.
- Published as an open engineering reference, not as certified equipment.

## Out of scope

- Cleaning drums for reuse as containers.
- Drums that held toxic, corrosive or unknown hazardous contents; these are not processed.
- Paint stripping and surface finishing beyond what the purge step removes (to be a separate question).
- Artistic cutting and embossing tools.

## Prior work

| Prior work | What it does | Gap for these users | Source |
| --- | --- | --- | --- |
| Croix-des-Bouquets burn and chisel method | Chisel off lids, split the side, burn out with dried cane or grass, flatten | Uses open fire and hand chisels | [link](https://www.sfomuseum.org/exhibitions/haitian-metal-sculpture) |
| Banana-leaf burn-out with hammer and chisel | Drum stuffed with banana leaves and burned, then sliced and stretched to a 3 by 6 ft sheet using only hammers and chisels | Same fire step; no purge or vapour check | [link](https://singingrooster.org/about-haitian-art/) |
| Body-weight flattening | Artists climb inside the split drum and use their weight to open it, then pound and sand it flat | Tiring and uneven; no rolling or clamping tool | [link](https://store.rootsofdevelopment.org/wp-content/uploads/2023/12/About-Haitian-Metal-Art.pdf) |

## Co-design

An artisan cooperative or community arts organisation working with drum-based metal artists, paired with a vocational training centre or local fabricator, to test the bench set in a working studio and shape the procedure around how apprentices actually work.

The first candidate to approach is a fair trade organisation that already works with Haitian metal artists, such as Singing Rooster, to reach a cooperative of Croix-des-Bouquets artists wherever they now work; a vocational welding school is the second candidate, for the build. Neither has been approached and nothing is agreed (DMP-DDR-001, D11).

Co-design checklist, to complete with the partner before any trial:

- [ ] Partner and studio agreed, with a named contact.
- [ ] Drum supply described: where drums come from, what they held, how they are labelled.
- [ ] Water supply and disposal route for purge water agreed.
- [ ] Pictogram procedure sheets reviewed with apprentices in their language.
- [ ] Panel sizes (about 233 x 1,800 mm) and head discs accepted by the artists.
- [ ] A person trained in the gas detector named for each session.

## Open questions, answered on 2026-10-03

Each question below was answered by a decision made under Amish's pre-approval of 2026-10-03; the decision records give the reasons.

| Question | Answer | Record |
| --- | --- | --- |
| Burning does two jobs today, clearing residue and stripping paint. What replaces the paint stripping step without fire? | The panels leave the bench set painted. Paint removal is a separate cold step (scraper and wire brush, or a non-flammable stripper outdoors) outside this design; the bench set never heats the steel. | DMP-DDR-001, D4 |
| Which purge method (water fill, air flush or steam) suits workshops with little water or power? | Water fill with a little detergent, soak 10 minutes, drain through the bottom bung; the water settles in a spare drum and is reused. Air flush needs a blower and steam needs fuel, so neither is used. | DMP-DDR-001, D1 |
| What wall thickness range of drum steel must the cutter and rolls handle? | Body 0.8 to 1.5 mm and heads 1.0 to 1.5 mm; forces are sized at 1.5 mm and the slip roll setting is worked out for 0.8 to 1.2 mm. | DMP-DDR-001, D8; DMP-CAL-001 |
| Would a shared bench set per cooperative work better than one per workshop? | One bench set shared by a cooperative or a cluster of workshops. | DMP-DDR-001, D9 |
| Which artisan cooperative would host the first trials, given the security situation in Croix-des-Bouquets? | First candidate to approach: Haitian metal artists reached through a fair trade partner, wherever they now work; nothing agreed. | DMP-DDR-001, D11 |

## Safety

> **Safety:** An empty drum that held oil can still hold flammable vapour, and cutting, grinding or heating it can make it explode. DrumPanel removes the fire from the process, but the vapour hazard stays until each drum is purged and checked. Drums that held fuel, solvent, chemicals or unknown contents are never processed. Cut drum steel has sharp edges, and the hand-cranked tools have in-running nips; the design answers these with guards, gloves and the safety stops in DMP-BLD-001. DrumPanel is published as an open engineering reference, never as certified equipment.

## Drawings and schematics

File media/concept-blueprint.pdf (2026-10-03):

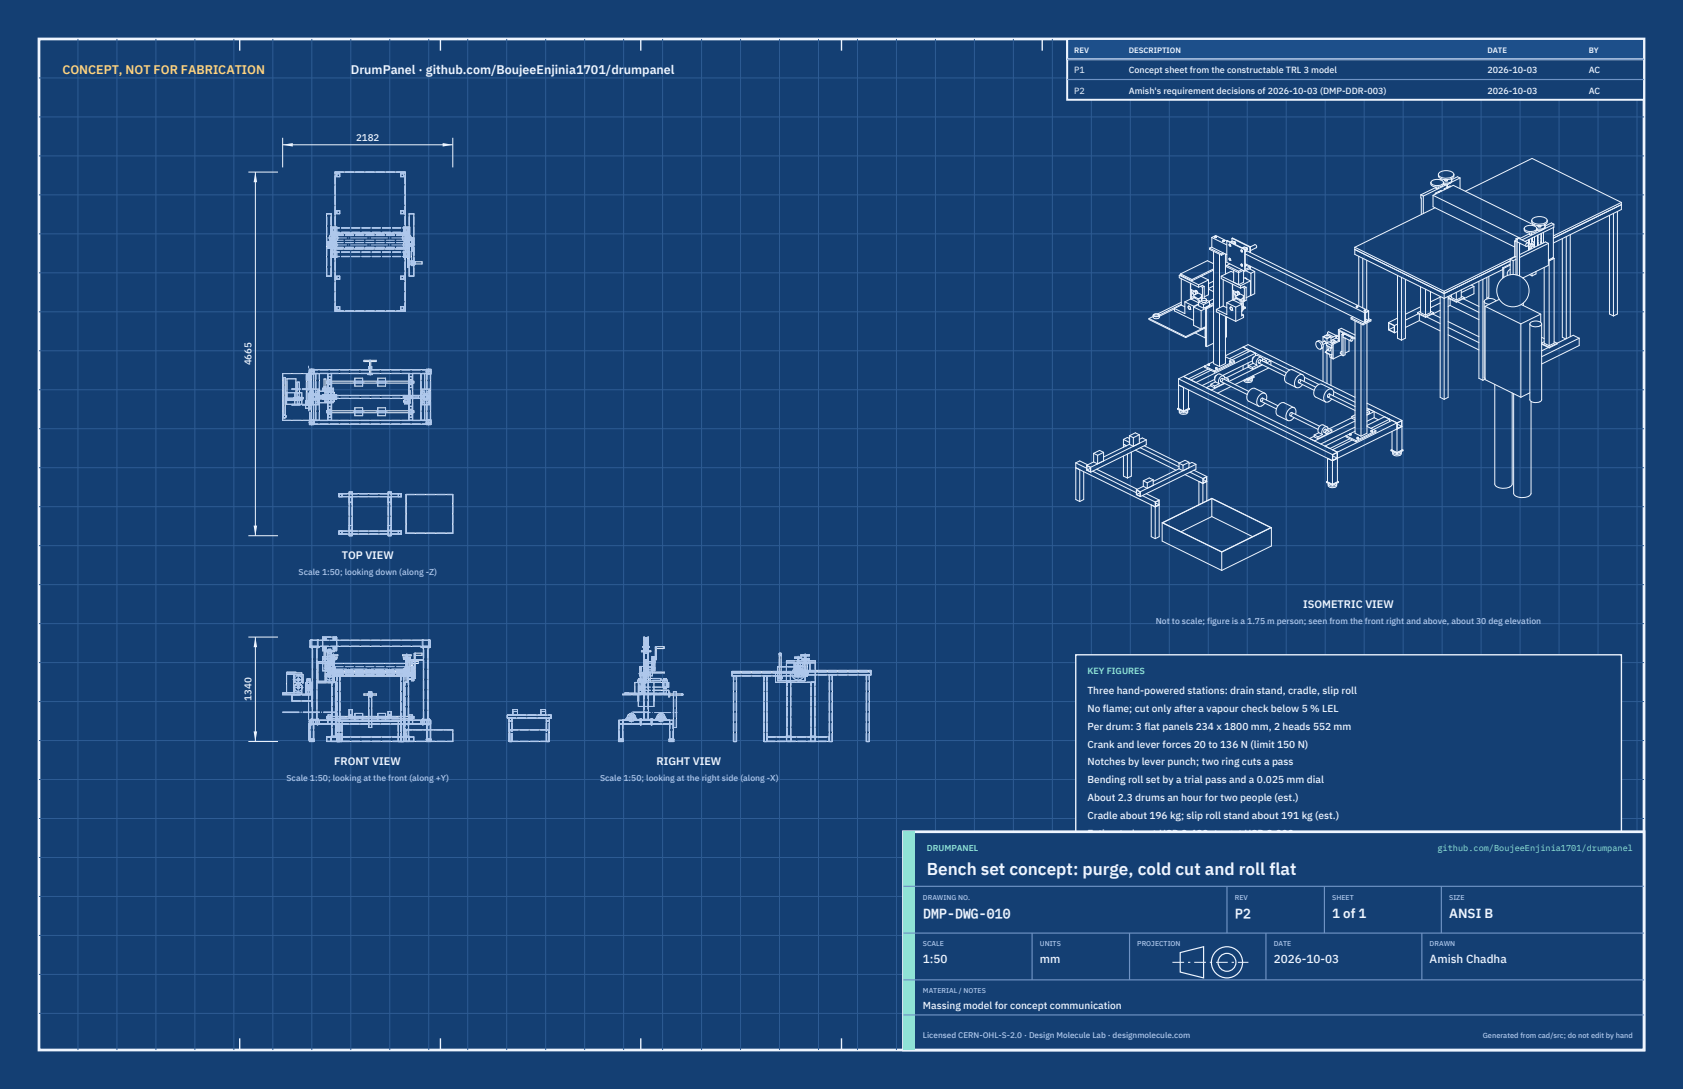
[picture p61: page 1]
CONCEPT, NOT FOR FABRICATION; DrumPanel · github.com/BoujeeEnjinia1701/drumpanel; FRONT VIEW; TOP VIEW; RIGHT VIEW; ISOMETRIC VIEW; REV; DESCRIPTION; DATE; Concept sheet from the constructable TRL 3 model; Amish's requirement decisions of 2026-10-03 (DMP-DDR-003); DRUMPANEL; github.com/BoujeeEnjinia1701/drumpanel; DRAWING NO. DMP-DWG-010; REV P2; SHEET 1 of 1; SIZE ANSI B; SCALE 1:50; UNITS mm; PROJECTION; DRAWN Amish Chadha; Licensed CERN-OHL-S-2.0 · Design Molecule Lab · designmolecule.com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

Scale 1:50; looking down (along -Z)

Not to scale; figure is a 1.75 m person; seen from the front right and above, about 30 deg elevation

KEY FIGURES
Three hand-powered stations: drain stand, cradle, slip roll
No flame; cut only after a vapour check below 5 % LEL
Per drum: 3 flat panels 234 x 1800 mm, 2 heads 552 mm
Crank and lever forces 20 to 136 N (limit 150 N)
Notches by lever punch; two ring cuts a pass
Bending roll set by a trial pass and a 0.025 mm dial
About 2.3 drums an hour for two people (est.)
Cradle about 196 kg; slip roll stand about 191 kg (est.)
Estimated cost USD 3,489; target USD 3,000

Scale 1:50; looking at the front (along +Y)

Scale 1:50; looking at the right side (along -X)

Bench set concept: purge, cold cut and roll flat

MATERIAL / NOTES
Massing model for concept communication

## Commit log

2026-10-03 DrumPanel at TRL 3: constructable design (kit 1.7.0)
    Problem, concept and requirements; sizing calculations; CAD model, STEP and STL; general arrangement drawing; bill of materials; build plan with making sketches, joint close-ups and step pictures; design decisions register (all decided under Amish's 2026-10-03 pre-approval); TRL 2 and TRL 3 review; photoreal renders and storefront card. Private until Amish opens it.
    [bom.csv, cutting-cradle.step, drain-stand.step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]
2026-10-03 Carry Amish's 2026-10-03 requirement decisions into the design
    Amish chose option A on each requirement decision ("1A 2A 3A 4A 5A 6A 7A 8A 9A 10A 11A"). CampBreak: primed foot valve, pre-coupled suction hose and a drilled 30 s gather (R9 now 3.2 min at 100 m, me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
    [bom.csv, cutting-cradle.step, drain-stand.step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]
2026-10-04 Carry Amish's round-2 and round-3 decisions into the design
    Amish approved all 46 round-2 recommendations ("i agree with all the 46 recommendations you provided. please proceed.") and all round-3 recommendations ("For round 3, I agree with all your proposed r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
2026-10-28 Kit 1.9.1 upgrade: pipeline documents and detailed CAD for every option
    Kit 1.9.1 installed (.kit, CLAUDE.md, .claude/commands). Kit 1.8 pipeline: STEM check with fixes under the 2026-10-23 standing instruction, concept options with the current design as option A, URS, PRS, generated RTM, REG, FEA, RSK with design FMEA, MKT, PLN and DDR; kit 1.9 D3 model of every option passing cad/fidelity.json; independent review recorded in the STEM check. Amish's 2026-10-25 decisions recorded where he approved a recommendation; all others proposed, awaiting Amish. Product renders and the options picture follow in a later commit where not yet included.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
2026-10-29 Add the concept options picture rendered from the D3 option models
    media/options.png from Blender Cycles panels of every option, rendered on Amish's Mac; the label reads CURRENT DESIGN unless project.yaml records Amish's choice. Clears the docs check, which needs th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

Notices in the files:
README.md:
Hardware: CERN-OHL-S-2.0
